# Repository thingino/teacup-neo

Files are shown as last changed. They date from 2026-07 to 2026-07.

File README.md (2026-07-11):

# Teacup Neo

A universal development platform for **any Ingenic SoC** — T10, T20, T21, T23, T30,
T31, T32, T33, T40, T41, and the A1 NVR processor — regardless of package
(QFN88 / QFN96 / BGA232 / BGA356 / BGA381).

Two boards:
- a **carrier** — the universal baseboard: adjustable SoC power, all peripherals,
  full pin breakout, and an on-board **ESP32-S3 management controller** so an agent
  (an LLM, CI, or a human) can drive the target wired *or* wireless — flash, reset,
  boot-select, console, and voltage-margin it hands-off;
- a small per-SoC **interposer** — the SoC + its package fanout + clock + decoupling
  + straps (+ optional local power / boot NOR), presented on a **DDR4 card-edge**
  (UDIMM-288 desktop) socket.

Swap the interposer, keep the carrier — the package stops mattering.

## The design

**Full spec: [`docs/UNIVERSAL.md`](docs/UNIVERSAL.md).** It covers the connector
choice, the power architecture (adjustable VCORE/VDDR with digipot voltage control +
margining), the verified T10→A1 rail table, clock/flash/boot, the ESP32-S3 BMC and
autonomous flash loop, full sensor/camera support (MIPI + DVP across the whole
family), full **A1** support (dual SATA 3.0 + dual GbE), dedicated camera-SoC
peripherals (audio, PWM/IR-cut/IR-LED, JTAG), carrier test points, and the
pin-breakout budget.

**Building it:** [`docs/BUILD.md`](docs/BUILD.md) is the agent-facing build playbook —
the headless KiCad pipeline (footprints → symbols → label-driven schematics →
`pcbnew` netlist apply → FreeRouting → manufacturing), the per-phase verification
gates, and the gotchas already proven on the T41 board in [`old/`](old/).

**Status: design / specification.** No open or deferred design questions remain; the
next step is the geography-first pin assignment against a carrier floorplan.

## `old/` — the T41 precursor

[`old/`](old/) holds the original single-SoC **T41 (QFN96)** board that proved the
approach and the headless-KiCad pipeline (kicad-cli + pcbnew + FreeRouting). It's
netlist-verified and ~83% auto-routed — details in [`old/README.md`](old/README.md).

License: GPL-3.0 (inherited from the upstream [Teacup](https://github.com/CapnRon/Teacup)).

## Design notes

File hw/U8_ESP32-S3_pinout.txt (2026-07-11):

U8 -- ESP32-S3-WROOM-1-N16R2 -- pin assignment
Generated from hw/sheets/bmc.kicad_sch (build_bmc.py, U8_PINS)

Pin  Module signal  Net / function
------------------------------------------------------------
1    GND            GND flag
2    3V3            +3V3_ALWAYS
3    EN             HOSTED_RESET
4    GPIO4          I2C_PWR_SDA
5    GPIO5          I2C_PWR_SCL
6    GPIO6          I2C_ID_SDA
7    GPIO7          I2C_ID_SCL
8    GPIO15         HOSTED_SPI_CLK
9    GPIO16         HOSTED_SPI_MOSI
10   GPIO17         UART1_TX
11   GPIO18         UART1_RX
12   GPIO8          BOOTSEL
13   GPIO19         BMC_USB_DM
14   GPIO20         BMC_USB_DP
15   GPIO3          RESET_EN
16   GPIO46         SW5V_EN_ALT
17   GPIO9          SFC_IO3
18   GPIO10         SFC_CS
19   GPIO11         SFC_IO0
20   GPIO12         SFC_CLK
21   GPIO13         SFC_IO1
22   GPIO14         SFC_IO2
23   GPIO21         HOSTED_SPI_MISO
24   GPIO47         HOSTED_SPI_CS
25   GPIO48         HOSTED_HANDSHAKE
26   GPIO45         HOSTED_DATA_READY
27   GPIO0          U8_BOOT
28   SPIIO6         EXP_INT
29   SPIIO7         spare
30   SPIDQS         EN_CS_U4
31   GPIO38         EN_CS_U5
32   MTCK           USB_OC1
33   MTDO           USB_OC2
34   MTDI           USB_OC3
35   MTMS           spare
36   U0RXD          ESP32_CONSOLE_RX
37   U0TXD          ESP32_CONSOLE_TX
38   GPIO2          SW5V_EN_BMC
39   GPIO1          VCORE_SNS
40   GND            (tied to pin 1's GND point)
41   GND            (tied to pin 1's GND point)

Notes:
- 2 GPIOs genuinely spare (29, 35); everything else allocated.
- Pins 28-30 (SPIIO6/SPIIO7/SPIDQS) are octal-PSRAM-only pins,
  usable as plain GPIO here because this is the quad-PSRAM (R2) variant.
- EN_CS_U4/U5 (flash CS-select) and SW5V_EN_BMC/SW5V_EN_ALT (power-domain
  switching) are kept on native GPIO deliberately -- margin/timing testing.
- USB_OC1-3 kept native for fast overcurrent response.
- USB_EN1-3, PG_SW5V, PG_VCORE, PG_SW5V_ALT, SW_SENSE_1/4, DCJACK_PRESENT
  moved off native GPIO onto U15 (TCA9555PWR, 16-bit I2C GPIO expander,
  LCSC C465732), sharing the I2C_PWR bus (not I2C_ID -- keeps the digipot/
  ID-EEPROM bus-isolation principle intact). Address 0x20 (A0-A2 grounded),
  no conflict with the MCP4661 digipot's 0x28-range address.
- HOSTED_SPI_CLK/MOSI/MISO/CS, HOSTED_HANDSHAKE, HOSTED_DATA_READY: ESP-Hosted
  full-duplex SPI co-processor link to the interposer SoC, crossing J1 pins 43-48.
  HOSTED_RESET (pin 3, ESP32's own EN) crosses via J1 pin 86 -- host side must
  drive it open-drain so it doesn't fight R8's pull-up.
- EXP_INT: U15's interrupt output, carrier-local, not crossing J1.

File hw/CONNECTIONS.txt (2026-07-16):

TEACUP UNIVERSAL CARRIER BOARD - CONNECTION REFERENCE
Generated directly from the KiCad netlist export (ground truth -- if the
schematic's visual layout is unclear or you're rebuilding it by hand, this
is what every pin SHOULD end up wired to, regardless of how it currently renders.
================================================================================

### POWER
--------------------------------------------------------------------------------

C1  (22uF)
      footprint: Capacitor_SMD:C_0805_2012Metric
      pin    1                       -> +5V_SW
      pin    2                       -> GND

C2  (100nF)
      footprint: Capacitor_SMD:C_0402_1005Metric
      pin    1                       -> +5V_SW
      pin    2                       -> GND

C3  (100nF)
      footprint: Capacitor_SMD:C_0402_1005Metric
      pin    1                       -> U1_BST
      pin    2                       -> U1_SW

C4  (1uF)
      footprint: Capacitor_SMD:C_0402_1005Metric
      pin    1                       -> U1_VCC
      pin    2                       -> GND

C5  (4.7nF)
      footprint: Capacitor_SMD:C_0402_1005Metric
      pin    1                       -> U1_SS
      pin    2                       -> GND

C6  (10uF)
      footprint: Capacitor_SMD:C_0805_2012Metric
      pin    1                       -> +5V_SW
      pin    2                       -> GND

C7  (100nF)
      footprint: Capacitor_SMD:C_0402_1005Metric
      pin    1                       -> U2_BST
      pin    2                       -> U2_SW

C9  (22uF)
      footprint: Capacitor_SMD:C_0805_2012Metric
      pin    1                       -> VCORE
      pin    2                       -> GND

C10  (22uF)
      footprint: Capacitor_SMD:C_0805_2012Metric
      pin    1                       -> VCORE
      pin    2                       -> GND

C11  (22uF)
      footprint: Capacitor_SMD:C_0805_2012Metric
      pin    1                       -> VDDR
      pin    2                       -> GND

C12  (100nF)
      footprint: Capacitor_SMD:C_0402_1005Metric
      pin    1                       -> +3V3
      pin    2                       -> GND

C13  (1nF)
      footprint: Capacitor_SMD:C_0402_1005Metric
      pin    1                       -> U4_CT
      pin    2                       -> GND

C14  (1uF)
      footprint: Capacitor_SMD:C_0603_1608Metric
      pin    1                       -> U5_VIN
      pin    2                       -> GND

C15  (10uF)
      footprint: Capacitor_SMD:C_0805_2012Metric
      pin    1                       -> +3V3_ALWAYS
      pin    2                       -> GND

C16  (10uF)
      footprint: Capacitor_SMD:C_0805_2012Metric
      pin    1                       -> +5V_SW
      pin    2                       -> GND

C17  (100nF)
      footprint: Capacitor_SMD:C_0402_1005Metric
      pin    1                       -> U7_BST
      pin    2                       -> U7_SW

C18  (22uF)
      footprint: Capacitor_SMD:C_0805_2012Metric
      pin    1                       -> +3V3
      pin    2                       -> GND

C19  (1uF)
      footprint: Capacitor_SMD:C_0603_1608Metric
      pin    1                       -> +3V3
      pin    2                       -> GND

C20  (10uF)
      footprint: Capacitor_SMD:C_0805_2012Metric
      pin    1                       -> +1V8
      pin    2                       -> GND

C23  (1nF)
      footprint: Capacitor_SMD:C_0402_1005Metric
      pin    1                       -> U14_CT
      pin    2                       -> GND

D1  (PMEG2010ER)
      footprint: Diode_SMD:Nexperia_CFP3_SOD-123W
      pin    1  K                    -> U5_VIN
      pin    2  A                    -> +5V_BMC

D2  (PMEG2010ER)
      footprint: Diode_SMD:Nexperia_CFP3_SOD-123W
      pin    1  K                    -> U5_VIN
      pin    2  A                    -> +5V_ALT

JP2  (0.8V)
      footprint: Connector_PinHeader_2.54mm:PinHeader_1x02_P2.54mm_Vertical
      pin    1  Pin_1                -> VCORE_FB_SEL
      pin    2  Pin_2                -> VCORE_FB_0V8

JP3  (0.9V)
      footprint: Connector_PinHeader_2.54mm:PinHeader_1x02_P2.54mm_Vertical
      pin    1  Pin_1                -> VCORE_FB_SEL
      pin    2  Pin_2                -> VCORE_FB_0V9

JP4  (1.0V)
      footprint: Connector_PinHeader_2.54mm:PinHeader_1x02_P2.54mm_Vertical
      pin    1  Pin_1                -> VCORE_FB_SEL
      pin    2  Pin_2                -> VCORE_FB_1V0

JP5  (1.1V)
      footprint: Connector_PinHeader_2.54mm:PinHeader_1x02_P2.54mm_Vertical
      pin    1  Pin_1                -> VCORE_FB_SEL
      pin    2  Pin_2                -> VCORE_FB_1V1

JP6  (COMPUTER)
      footprint: Connector_PinHeader_2.54mm:PinHeader_1x02_P2.54mm_Vertical
      pin    1  Pin_1                -> VCORE_FB_SEL
      pin    2  Pin_2                -> VCORE_FB_DIGIPOT

JP7  (1.35V)
      footprint: Connector_PinHeader_2.54mm:PinHeader_1x02_P2.54mm_Vertical
      pin    1  Pin_1                -> VDDR_FB_SEL
      pin    2  Pin_2                -> VDDR_FB_1V35

JP8  (1.5V)
      footprint: Connector_PinHeader_2.54mm:PinHeader_1x02_P2.54mm_Vertical
      pin    1  Pin_1                -> VDDR_FB_SEL
      pin    2  Pin_2                -> VDDR_FB_1V5

JP9  (1.8V)
      footprint: Connector_PinHeader_2.54mm:PinHeader_1x02_P2.54mm_Vertical
      pin    1  Pin_1                -> VDDR_FB_SEL
      pin    2  Pin_2                -> VDDR_FB_1V8

JP10  (COMPUTER)
      footprint: Connector_PinHeader_2.54mm:PinHeader_1x02_P2.54mm_Vertical
      pin    1  Pin_1                -> VDDR_FB_SEL
      pin    2  Pin_2                -> VDDR_FB_DIGIPOT

L1  (2.2uH)
      footprint: Inductor_SMD:L_1210_3225Metric
      pin    1                       -> U1_SW
      pin    2                       -> VCORE

L2  (2.2uH)
      footprint: Inductor_SMD:L_1210_3225Metric
      pin    1                       -> U2_SW
      pin    2                       -> VDDR

L3  (2.2uH)
      footprint: Inductor_SMD:L_1210_3225Metric
      pin    1                       -> U7_SW
      pin    2                       -> +3V3

R1  (100k)
      footprint: Resistor_SMD:R_0402_1005Metric
      pin    1                       -> +5V_SW
      pin    2                       -> U1_EN

R2  (10k)
      footprint: Resistor_SMD:R_0402_1005Metric
      pin    1                       -> +3V3
      pin    2                       -> PG_VCORE

R3  (100k)
      footprint: Resistor_SMD:R_0402_1005Metric
      pin    1                       -> +3V3
      pin    2                       -> U2_EN

R4  (10k)
      footprint: Resistor_SMD:R_0402_1005Metric
      pin    1                       -> +3V3
      pin    2                       -> PG_SW5V

R5  (100k)
      footprint: Resistor_SMD:R_0402_1005Metric
      pin    1                       -> +5V_SW
      pin    2                       -> U7_EN

R6  (31.6k)
      footprint: Resistor_SMD:R_0402_1005Metric
      pin    1                       -> +3V3
      pin    2                       -> P3V3_FB

R7  (10k)
      footprint: Resistor_SMD:R_0402_1005Metric
      pin    1                       -> P3V3_FB
      pin    2                       -> GND

R20  (100k)
      footprint: Resistor_SMD:R_0402_1005Metric
      pin    1                       -> EN_SW_BMC
      pin    2                       -> GND

R21  (1k)
      footprint: Resistor_SMD:R_0402_1005Metric
      pin    1                       -> SW5V_EN_BMC
      pin    2                       -> EN_SW_BMC

R22  (100k)
      footprint: Resistor_SMD:R_0402_1005Metric
      pin    1                       -> EN_SW_ALT
      pin    2                       -> GND

R23  (1k)
      footprint: Resistor_SMD:R_0402_1005Metric
      pin    1                       -> SW5V_EN_ALT
      pin    2                       -> EN_SW_ALT

R24  (10k)
      footprint: Resistor_SMD:R_0402_1005Metric
      pin    1                       -> +3V3
      pin    2                       -> PG_SW5V_ALT

R25  (4.7k)
      footprint: Resistor_SMD:R_0402_1005Metric
      pin    1                       -> +3V3
      pin    2                       -> I2C_PWR_SDA

R26  (4.7k)
      footprint: Resistor_SMD:R_0402_1005Metric
      pin    1                       -> +3V3
      pin    2                       -> I2C_PWR_SCL

R27  (3.32k)
      footprint: Resistor_SMD:R_0402_1005Metric
      pin    1                       -> VCORE
      pin    2                       -> VCORE_FB_0V8

R28  (10.0k)
      footprint: Resistor_SMD:R_0402_1005Metric
      pin    1                       -> VCORE_FB_0V8
      pin    2                       -> GND

R29  (4.99k)
      footprint: Resistor_SMD:R_0402_1005Metric
      pin    1                       -> VCORE
      pin    2                       -> VCORE_FB_0V9

R30  (10.0k)
      footprint: Resistor_SMD:R_0402_1005Metric
      pin    1                       -> VCORE_FB_0V9
      pin    2                       -> GND

R31  (6.65k)
      footprint: Resistor_SMD:R_0402_1005Metric
      pin    1                       -> VCORE
      pin    2                       -> VCORE_FB_1V0

R32  (10.0k)
      footprint: Resistor_SMD:R_0402_1005Metric
      pin    1                       -> VCORE_FB_1V0
      pin    2                       -> GND

R33  (8.25k)
      footprint: Resistor_SMD:R_0402_1005Metric
      pin    1                       -> VCORE
      pin    2                       -> VCORE_FB_1V1

R34  (10.0k)
      footprint: Resistor_SMD:R_0402_1005Metric
      pin    1                       -> VCORE_FB_1V1
      pin    2                       -> GND

R35  (6.81k)
      footprint: Resistor_SMD:R_0402_1005Metric
      pin    1                       -> VDDR
      pin    2                       -> VDDR_FB_1V35

R36  (10.0k)
      footprint: Resistor_SMD:R_0402_1005Metric
      pin    1                       -> VDDR_FB_1V35
      pin    2                       -> GND

R37  (8.66k)
      footprint: Resistor_SMD:R_0402_1005Metric
      pin    1                       -> VDDR
      pin    2                       -> VDDR_FB_1V5

R38  (10.0k)
      footprint: Resistor_SMD:R_0402_1005Metric
      pin    1                       -> VDDR_FB_1V5
      pin    2                       -> GND

R39  (12.4k)
      footprint: Resistor_SMD:R_0402_1005Metric
      pin    1                       -> VDDR
      pin    2                       -> VDDR_FB_1V8

R40  (10.0k)
      footprint: Resistor_SMD:R_0402_1005Metric
      pin    1                       -> VDDR_FB_1V8
      pin    2                       -> GND

U1  (AP62600SJ-7)
      footprint: teacup-carrier:QFN-12_L3.0-W2.0-P0.50-TL_AP62600SJ-7
      pin    1  PGND                 -> GND
      pin    2  VIN                  -> +5V_SW
      pin    3  EN                   -> U1_EN
      pin    4  MODE                 -> GND
      pin    5  FSEL                 -> GND
      pin    6  PG                   -> PG_VCORE
      pin    7  BST                  -> U1_BST
      pin    8  SW                   -> U1_SW
      pin    9  VCC                  -> U1_VCC
      pin   10  SS/TR                -> U1_SS
      pin   11  GND                  -> GND
      pin   12  FB                   -> VCORE_FB_SEL

U2  (AP62300WU-7)
      footprint: teacup-carrier:TSOT-23-6_L2.9-W1.6-P0.95-LS2.8-BL
      pin    1  GND                  -> GND
      pin    2  SW                   -> U2_SW
      pin    3  VIN                  -> +5V_SW
      pin    4  FB                   -> VDDR_FB_SEL
      pin    5  EN                   -> U2_EN
      pin    6  BST                  -> U2_BST

U3  (MCP4661-104E_ST)
      footprint: Package_SO:TSSOP-14_4.4x5mm_P0.65mm
      pin    1  HVC/A0               -> GND
      pin    2  SCL                  -> I2C_PWR_SCL
      pin    3  SDA                  -> I2C_PWR_SDA
      pin    4  VSS                  -> GND
      pin    5  P1B                  -> GND
      pin    6  P1W                  -> VDDR_FB_DIGIPOT
      pin    7  P1A                  -> VDDR
      pin    8  P0A                  -> VCORE
      pin    9  P0W                  -> VCORE_FB_DIGIPOT
      pin   10  P0B                  -> GND
      pin   11  WP                   -> +3V3
      pin   12  A2                   -> GND
      pin   13  A1                   -> GND
      pin   14  VDD                  -> +3V3

U4  (TPS22990DMLR)
      footprint: teacup-carrier:WSON-10_L3.0-W2.0-P0.50-BL-EP_TI_DML
      pin    1  CT                   -> U4_CT
      pin    2  NC                   -> (not connected)
      pin    3  VIN                  -> +5V_BMC
      pin    4  VBIAS                -> +5V_BMC
      pin    5  ON                   -> EN_SW_BMC
      pin    6  GND                  -> GND
      pin    7  PG                   -> PG_SW5V
      pin    8  VOUT                 -> +5V_SW
      pin    9  VOUT                 -> +5V_SW
      pin   10  VOUT                 -> +5V_SW
      pin   11  VIN                  -> +5V_BMC

U5  (AZ1117CH-3.3TRG1)
      footprint: Package_TO_SOT_SMD:SOT-223-3_TabPin2
      pin    1  IN                   -> U5_VIN
      pin    2  GND                  -> GND
      pin    3  OUT                  -> +3V3_ALWAYS

U6  (AZ1117CH-1.8TRG1)
      footprint: Package_TO_SOT_SMD:SOT-223-3_TabPin2
      pin    1  IN                   -> +3V3
      pin    2  GND                  -> GND
      pin    3  OUT                  -> +1V8

U7  (AP62300WU-7)
      footprint: teacup-carrier:TSOT-23-6_L2.9-W1.6-P0.95-LS2.8-BL
      pin    1  GND                  -> GND
      pin    2  SW                   -> U7_SW
      pin    3  VIN                  -> +5V_SW
      pin    4  FB                   -> P3V3_FB
      pin    5  EN                   -> U7_EN
      pin    6  BST                  -> U7_BST

U14  (TPS22990DMLR)
      footprint: teacup-carrier:WSON-10_L3.0-W2.0-P0.50-BL-EP_TI_DML
      pin    1  CT                   -> U14_CT
      pin    2  NC                   -> (not connected)
      pin    3  VIN                  -> +5V_ALT
      pin    4  VBIAS                -> +5V_ALT
      pin    5  ON                   -> EN_SW_ALT
      pin    6  GND                  -> GND
      pin    7  PG                   -> PG_SW5V_ALT
      pin    8  VOUT                 -> +5V_SW
      pin    9  VOUT                 -> +5V_SW
      pin   10  VOUT                 -> +5V_SW
      pin   11  VIN                  -> +5V_ALT

### DDR4 UDIMM-288 CONNECTOR
--------------------------------------------------------------------------------

J1  (AH58893-T9B10-3F)
      footprint: teacup-carrier:DDR4288S0511H_UDIMM288
      pin    1  P1                   -> VCORE
      pin    2  P2                   -> VCORE
      pin    3  P3                   -> VCORE
      pin    4  P4                   -> VCORE
      pin    5  P5                   -> GND
      pin    6  P6                   -> MICLP
      pin    7  P7                   -> HPOUTL
      pin    8  P8                   -> GND
      pin    9  P9                   -> VDDR
      pin   10  P10                  -> VDDR
      pin   11  P11                  -> GND
      pin   12  P12                  -> GND
      pin   13  P13                  -> +3V3
      pin   14  P14                  -> +3V3
      pin   15  P15                  -> +1V8
      pin   16  P16                  -> +1V8
      pin   17  P17                  -> +5V_SW
      pin   18  P18                  -> +5V_SW
      pin   19  P19                  -> GND
      pin   20  P20                  -> USBA_HOST_DP
      pin   21  P21                  -> USBA_HOST_DM
      pin   22  P22                  -> GND
      pin   23  P23                  -> VCORE_SNS
      pin   24  P24                  -> HOSTED_DATA_READY
      pin   25  P25                  -> HOSTED_HANDSHAKE
      pin   26  P26                  -> HOSTED_SPI_CS
      pin   27  P27                  -> HOSTED_SPI_MISO
      pin   28  P28                  -> SFC_IO2
      pin   29  P29                  -> SFC_IO1
      pin   30  P30                  -> SFC_CLK
      pin   31  P31                  -> SFC_IO0
      pin   32  P32                  -> SFC_CS
      pin   33  P33                  -> SFC_IO3
      pin   34  P34                  -> RESET_EN
      pin   35  P35                  -> BOOTSEL
      pin   36  P36                  -> GND
      pin   37  P37                  -> GND
      pin   38  P38                  -> GND
      pin   39  P39                  -> GND
      pin   40  P40                  -> GND
      pin   41  P41                  -> GND
      pin   42  P42                  -> UART1_RX
      pin   43  P43                  -> UART1_TX
      pin   44  P44                  -> HOSTED_SPI_MOSI
      pin   45  P45                  -> HOSTED_SPI_CLK
      pin   46  P46                  -> I2C_ID_SCL
      pin   47  P47                  -> I2C_ID_SDA
      pin   48  P48                  -> HOSTED_RESET
      pin   49  P49                  -> GND
      pin   50  P50                  -> MSC0_D1
      pin   51  P51                  -> GND
      pin   52  P52                  -> MSC0_D0
      pin   53  P53                  -> MSC0_CLK
      pin   54  P54                  -> MSC0_CMD
      pin   55  P55                  -> MSC0_D3_CD
      pin   56  P56                  -> MSC0_D2
      pin   57  P57                  -> GND
      pin   58  P58                  -> GND
      pin   59  P59                  -> GND
      pin   60  P60                  -> MIPI0_SCCB_SDA
      pin   61  P61                  -> MIPI0_SCCB_SCL
      pin   62  P62                  -> MIPI0_GPIO
      pin   63  P63                  -> GND
      pin   64  P64                  -> MIPI0_CLKP
      pin   65  P65                  -> MIPI0_CLKN
      pin   66  P66                  -> GND
      pin   67  P67                  -> MIPI0_D1P
      pin   68  P68                  -> MIPI0_D1N
      pin   69  P69                  -> GND
      pin   70  P70                  -> MIPI0_D0P
      pin   71  P71                  -> MIPI0_D0N
      pin   72  P72                  -> GND
      pin   73  P73                  -> MIPI1_SCCB_SDA
      pin   74  P74                  -> MIPI1_SCCB_SCL
      pin   75  P75                  -> MIPI1_GPIO
      pin   76  P76                  -> GND
      pin   77  P77                  -> MIPI1_CLKP
      pin   78  P78                  -> MIPI1_CLKN
      pin   79  P79                  -> GND
      pin   80  P80                  -> MIPI1_D1P
      pin   81  P81                  -> MIPI1_D1N
      pin   82  P82                  -> GND
      pin   83  P83                  -> MIPI1_D0P
      pin   84  P84                  -> MIPI1_D0N
      pin   85  P85                  -> GND
      pin   86  P86                  -> GND
      pin   87  P87                  -> GMAC0_MDIO
      pin   88  P88                  -> GMAC0_MDCK
      pin   89  P89                  -> GMAC0_TXCLK
      pin   90  P90                  -> GMAC0_PHYCLK
      pin   91  P91                  -> GMAC0_TXEN
      pin   92  P92                  -> GMAC0_TXD0
      pin   93  P93                  -> GMAC0_TXD1
      pin   94  P94                  -> GMAC0_RXDV
      pin   95  P95                  -> GMAC0_RXD0
      pin   96  P96                  -> GMAC0_RXD1
      pin   97  P97                  -> GND
      pin   98  P98                  -> UART0_RXD
      pin   99  P99                  -> UART0_TXD
      pin  100  P100                 -> UART0_CTS
      pin  101  P101                 -> UART0_RTS
      pin  102  P102                 -> GND
      pin  103  P103                 -> UART2_RXD
      pin  104  P104                 -> UART2_TXD
      pin  105  P105                 -> UART2_CTS
      pin  106  P106                 -> UART2_RTS
      pin  107  P107                 -> GND
      pin  108  P108                 -> UART3_RXD
      pin  109  P109                 -> UART3_TXD
      pin  110  P110                 -> UART3_CTS
      pin  111  P111                 -> UART3_RTS
      pin  112  P112                 -> GND
      pin  113  P113                 -> GMAC1_MDIO
      pin  114  P114                 -> GMAC1_MDCK
      pin  115  P115                 -> GMAC1_TXCLK
      pin  116  P116                 -> GMAC1_PHYCLK
      pin  117  P117                 -> GMAC1_TXEN
      pin  118  P118                 -> GMAC1_TXD0
      pin  119  P119                 -> GMAC1_TXD1
      pin  120  P120                 -> GMAC1_RXDV
      pin  121  P121                 -> GMAC1_RXD0
      pin  122  P122                 -> GMAC1_RXD1
      pin  123  P123                 -> GND
      pin  124  P124                 -> SSI0_CLK
      pin  125  P125                 -> SSI0_DT
      pin  126  P126                 -> SSI0_DR
      pin  127  P127                 -> SSI0_CE0
      pin  128  P128                 -> SSI0_CE1
      pin  129  P129                 -> SSI0_GPC
      pin  130  P130                 -> GND
      pin  131  P131                 -> SSI1_CLK
      pin  132  P132                 -> SSI1_DT
      pin  133  P133                 -> SSI1_DR
      pin  134  P134                 -> SSI1_CE0
      pin  135  P135                 -> GND
      pin  136  P136                 -> PWM0
      pin  137  P137                 -> PWM1
      pin  138  P138                 -> PWM2
      pin  139  P139                 -> PWM3
      pin  140  P140                 -> PWM4
      pin  141  P141                 -> PWM5
      pin  142  P142                 -> PWM6
      pin  143  P143                 -> PWM7
      pin  144  P144                 -> GND
      pin  145  P145                 -> GND
      pin  146  P146                 -> SAR_AUX0
      pin  147  P147                 -> GND
      pin  148  P148                 -> SMB0_SDA
      pin  149  P149                 -> SMB0_SCK
      pin  150  P150                 -> SMB1_SDA
      pin  151  P151                 -> SMB1_SCK
      pin  152  P152                 -> GND
      pin  153  P153                 -> GPIO0
      pin  154  P154                 -> GPIO1
      pin  155  P155                 -> GPIO2
      pin  156  P156                 -> GPIO3
      pin  157  P157                 -> GPIO4
      pin  158  P158                 -> GPIO5
      pin  159  P159                 -> GPIO6
      pin  160  P160                 -> GPIO7
      pin  161  P161                 -> GPIO8
      pin  162  P162                 -> GPIO9
      pin  163  P163                 -> GPIO10
      pin  164  P164                 -> GPIO11
      pin  165  P165                 -> GPIO12
      pin  166  P166                 -> GPIO13
      pin  167  P167                 -> GPIO14
      pin  168  P168                 -> GPIO15
      pin  169  P169                 -> GND
      pin  170  P170                 -> GND
      pin  171  P171                 -> GND
      pin  172  P172                 -> GND
      pin  173  P173                 -> SPARE_P173
      pin  174  P174                 -> SPARE_P174
      pin  175  P175                 -> SPARE_P175
      pin  176  P176                 -> SPARE_P176
      pin  177  P177                 -> SPARE_P177
      pin  178  P178                 -> SPARE_P178
      pin  179  P179                 -> SPARE_P179
      pin  180  P180                 -> SPARE_P180
      pin  181  P181                 -> SPARE_P181
      pin  182  P182                 -> SPARE_P182
      pin  183  P183                 -> SPARE_P183
      pin  184  P184                 -> SPARE_P184
      pin  185  P185                 -> SPARE_P185
      pin  186  P186                 -> SPARE_P186
      pin  187  P187                 -> SPARE_P187
      pin  188  P188                 -> SPARE_P188
      pin  189  P189                 -> SPARE_P189
      pin  190  P190                 -> SPARE_P190
      pin  191  P191                 -> SPARE_P191
      pin  192  P192                 -> SPARE_P192
      pin  193  P193                 -> SPARE_P193
      pin  194  P194                 -> SPARE_P194
      pin  195  P195                 -> SPARE_P195
      pin  196  P196                 -> SPARE_P196
      pin  197  P197                 -> SPARE_P197
      pin  198  P198                 -> SPARE_P198
      pin  199  P199                 -> SPARE_P199
      pin  200  P200                 -> SPARE_P200
      pin  201  P201                 -> SPARE_P201
      pin  202  P202                 -> SPARE_P202
      pin  203  P203                 -> SPARE_P203
      pin  204  P204                 -> SPARE_P204
      pin  205  P205                 -> SPARE_P205
      pin  206  P206                 -> SPARE_P206
      pin  207  P207                 -> SPARE_P207
      pin  208  P208                 -> SPARE_P208
      pin  209  P209                 -> SPARE_P209
      pin  210  P210                 -> SPARE_P210
      pin  211  P211                 -> SPARE_P211
      pin  212  P212                 -> SPARE_P212
      pin  213  P213                 -> SPARE_P213
      pin  214  P214                 -> SPARE_P214
      pin  215  P215                 -> SPARE_P215
      pin  216  P216                 -> SPARE_P216
      pin  217  P217                 -> SPARE_P217
      pin  218  P218                 -> SPARE_P218
      pin  219  P219                 -> SPARE_P219
      pin  220  P220                 -> SPARE_P220
      pin  221  P221                 -> SPARE_P221
      pin  222  P222                 -> SPARE_P222
      pin  223  P223                 -> SPARE_P223
      pin  224  P224                 -> SPARE_P224
      pin  225  P225                 -> SPARE_P225
      pin  226  P226                 -> SPARE_P226
      pin  227  P227                 -> SPARE_P227
      pin  228  P228                 -> SPARE_P228
      pin  229  P229                 -> SPARE_P229
      pin  230  P230                 -> SPARE_P230
      pin  231  P231                 -> SPARE_P231
      pin  232  P232                 -> SPARE_P232
      pin  233  P233                 -> SPARE_P233
      pin  234  P234                 -> SPARE_P234
      pin  235  P235                 -> SPARE_P235
      pin  236  P236                 -> SPARE_P236
      pin  237  P237                 -> SPARE_P237
      pin  238  P238                 -> SPARE_P238
      pin  239  P239                 -> SPARE_P239
      pin  240  P240                 -> SPARE_P240
      pin  241  P241                 -> SPARE_P241
      pin  242  P242                 -> SPARE_P242
      pin  243  P243                 -> SPARE_P243
      pin  244  P244                 -> SPARE_P244
      pin  245  P245                 -> SPARE_P245
      pin  246  P246                 -> SPARE_P246
      pin  247  P247                 -> SPARE_P247
      pin  248  P248                 -> SPARE_P248
      pin  249  P249                 -> SPARE_P249
      pin  250  P250                 -> SPARE_P250
      pin  251  P251                 -> SPARE_P251
      pin  252  P252                 -> SPARE_P252
      pin  253  P253                 -> SPARE_P253
      pin  254  P254                 -> SPARE_P254
      pin  255  P255                 -> SPARE_P255
      pin  256  P256                 -> SPARE_P256
      pin  257  P257                 -> SPARE_P257
      pin  258  P258                 -> SPARE_P258
      pin  259  P259                 -> SPARE_P259
      pin  260  P260                 -> SPARE_P260
      pin  261  P261                 -> SPARE_P261
      pin  262  P262                 -> SPARE_P262
      pin  263  P263                 -> SPARE_P263
      pin  264  P264                 -> SPARE_P264
      pin  265  P265                 -> SPARE_P265
      pin  266  P266                 -> SPARE_P266
      pin  267  P267                 -> SPARE_P267
      pin  268  P268                 -> SPARE_P268
      pin  269  P269                 -> SPARE_P269
      pin  270  P270                 -> SPARE_P270
      pin  271  P271                 -> SPARE_P271
      pin  272  P272                 -> SPARE_P272
      pin  273  P273                 -> SPARE_P273
      pin  274  P274                 -> SPARE_P274
      pin  275  P275                 -> SPARE_P275
      pin  276  P276                 -> SPARE_P276
      pin  277  P277                 -> SPARE_P277
      pin  278  P278                 -> SPARE_P278
      pin  279  P279                 -> SPARE_P279
      pin  280  P280                 -> SPARE_P280
      pin  281  P281                 -> SPARE_P281
      pin  282  P282                 -> SPARE_P282
      pin  283  P283                 -> MSC1_CLK
      pin  284  P284                 -> MSC1_CMD
      pin  285  P285                 -> MSC1_D0
      pin  286  P286                 -> MSC1_D1
      pin  287  P287                 -> MSC1_D2
      pin  288  P288                 -> MSC1_D3_CD

### BMC - ESP32-S3
--------------------------------------------------------------------------------

C21  (10uF)
      footprint: Capacitor_SMD:C_0805_2012Metric
      pin    1                       -> +3V3_ALWAYS
      pin    2                       -> GND

C22  (100nF)
      footprint: Capacitor_SMD:C_0402_1005Metric
      pin    1                       -> +3V3_ALWAYS
      pin    2                       -> GND

C24  (100nF)
      footprint: Capacitor_SMD:C_0402_1005Metric
      pin    1                       -> +3V3
      pin    2                       -> GND

C25  (100nF)
      footprint: Capacitor_SMD:C_0402_1005Metric
      pin    1                       -> +3V3
      pin    2                       -> GND

C26  (100nF)
      footprint: Capacitor_SMD:C_0402_1005Metric
      pin    1                       -> +3V3
      pin    2                       -> GND

R8  (10k)
      footprint: Resistor_SMD:R_0402_1005Metric
      pin    1                       -> +3V3
      pin    2                       -> HOSTED_RESET

R9  (10k)
      footprint: Resistor_SMD:R_0402_1005Metric
      pin    1                       -> +3V3
      pin    2                       -> U8_BOOT

R10  (10k)
      footprint: Resistor_SMD:R_0402_1005Metric
      pin    1                       -> +3V3
      pin    2                       -> SW_SENSE_1

R11  (10k)
      footprint: Resistor_SMD:R_0402_1005Metric
      pin    1                       -> +3V3
      pin    2                       -> SW_SENSE_4

R41  (4.7k)
      footprint: Resistor_SMD:R_0402_1005Metric
      pin    1                       -> +3V3
      pin    2                       -> I2C_ID_SDA

R42  (4.7k)
      footprint: Resistor_SMD:R_0402_1005Metric
      pin    1                       -> +3V3
      pin    2                       -> I2C_ID_SCL

SW1  (SSSS711403)
      footprint: teacup-carrier:SW-TH_SSSS711403
      pin    1                       -> SW_SENSE_1
      pin    2                       -> (not connected)
      pin    3                       -> GND
      pin    4                       -> SW_SENSE_4
      pin    5                       -> (not connected)
      pin    6                       -> (not connected)

SW2  (SSSS711403)
      footprint: teacup-carrier:SW-TH_SSSS711403
      pin    1                       -> EN_SW_ALT
      pin    2                       -> (not connected)
      pin    3                       -> +5V_ALT
      pin    4                       -> EN_SW_BMC
      pin    5                       -> (not connected)
      pin    6                       -> (not connected)

U8  (ESP32-S3-WROOM-1-N16R2)
      footprint: teacup-carrier:ESP32-S3-WROOM-1
      pin    1  GND                  -> GND
      pin    2  3V3                  -> +3V3_ALWAYS
      pin    3  EN                   -> HOSTED_RESET
      pin    4  GPIO4                -> I2C_PWR_SDA
      pin    5  GPIO5                -> I2C_PWR_SCL
      pin    6  GPIO6                -> I2C_ID_SDA
      pin    7  GPIO7                -> I2C_ID_SCL
      pin    8  GPIO15               -> HOSTED_SPI_CLK
      pin    9  GPIO16               -> HOSTED_SPI_MOSI
      pin   10  GPIO17               -> UART1_TX
      pin   11  GPIO18               -> UART1_RX
      pin   12  GPIO8                -> BOOTSEL
      pin   13  GPIO19               -> BMC_USB_DM
      pin   14  GPIO20               -> BMC_USB_DP
      pin   15  GPIO3                -> RESET_EN
      pin   16  GPIO46               -> SW5V_EN_ALT
      pin   17  GPIO9                -> SFC_IO3
      pin   18  GPIO10               -> SFC_CS
      pin   19  GPIO11               -> SFC_IO0
      pin   20  GPIO12               -> SFC_CLK
      pin   21  GPIO13               -> SFC_IO1
      pin   22  GPIO14               -> SFC_IO2
      pin   23  GPIO21               -> HOSTED_SPI_MISO
      pin   24  GPIO47               -> HOSTED_SPI_CS
      pin   25  GPIO48               -> HOSTED_HANDSHAKE
      pin   26  GPIO45               -> HOSTED_DATA_READY
      pin   27  GPIO0                -> U8_BOOT
      pin   28  SPIIO6               -> EXP_INT
      pin   29  SPIIO7               -> (not connected)
      pin   30  SPIDQS               -> EN_CS_U4
      pin   31  GPIO38               -> EN_CS_U5
      pin   32  MTCK                 -> USB_OC1
      pin   33  MTDO                 -> USB_OC2
      pin   34  MTDI                 -> USB_OC3
      pin   35  MTMS                 -> (not connected)
      pin   36  U0RXD                -> ESP32_CONSOLE_RX
      pin   37  U0TXD                -> ESP32_CONSOLE_TX
      pin   38  GPIO2                -> SW5V_EN_BMC
      pin   39  GPIO1                -> VCORE_SNS
      pin   40  GND                  -> GND
      pin   41  GND                  -> GND

U9  (TS5A3166)
      footprint: Package_TO_SOT_SMD:SOT-23-5
      pin    1  NO                   -> NOR_U4_CE
      pin    2  COM                  -> SFC_CS
      pin    3  GND                  -> GND
      pin    4  IN                   -> EN_CS_U4
      pin    5  V+                   -> +3V3

U10  (TS5A3166)
      footprint: Package_TO_SOT_SMD:SOT-23-5
      pin    1  NO                   -> NOR_U5_CE
      pin    2  COM                  -> SFC_CS
      pin    3  GND                  -> GND
      pin    4  IN                   -> EN_CS_U5
      pin    5  V+                   -> +3V3

U11  (DIP-8 Socket)
      footprint: Package_DIP:DIP-8_W7.62mm_Socket
      pin    1  ~{CS}                -> NOR_U5_CE
      pin    2  DO(IO1)              -> SFC_IO1
      pin    3  IO2                  -> SFC_IO2
      pin    4  GND                  -> GND
      pin    5  DI(IO0)              -> SFC_IO0
      pin    6  CLK                  -> SFC_CLK
      pin    7  IO3                  -> SFC_IO3
      pin    8  VCC                  -> +3V3

U12  (TPS2053BDR)
      footprint: Package_SO:SOIC-16_3.9x9.9mm_P1.27mm
      pin    1  GND                  -> GND
      pin    2  IN1                  -> +5V_SW
      pin    3  EN1                  -> USB_EN1
      pin    4  EN2                  -> USB_EN2
      pin    5  GND                  -> GND
      pin    6  IN2                  -> +5V_SW
      pin    7  EN3                  -> USB_EN3
      pin    8  NC                   -> (not connected)
      pin    9  NC                   -> (not connected)
      pin   10  NC                   -> (not connected)
      pin   11  OUT3                 -> USB3_VBUS_OUT
      pin   12  OC3                  -> USB_OC3
      pin   13  OC2                  -> USB_OC2
      pin   14  OUT2                 -> USB2_VBUS_OUT
      pin   15  OUT1                 -> USB1_VBUS_OUT
      pin   16  OC1                  -> USB_OC1

U13  (W25Q32JVSS)
      footprint: Package_SO:SOIC-8_5.3x5.3mm_P1.27mm
      pin    1  ~{CS}                -> NOR_U4_CE
      pin    2  DO(IO1)              -> SFC_IO1
      pin    3  IO2                  -> SFC_IO2
      pin    4  GND                  -> GND
      pin    5  DI(IO0)              -> SFC_IO0
      pin    6  CLK                  -> SFC_CLK
      pin    7  IO3                  -> SFC_IO3
      pin    8  VCC                  -> +3V3

U15  (TCA9555PWR)
      footprint: Package_SO:TSSOP-24_4.4x7.8mm_P0.65mm
      pin    1  ~{INT}               -> EXP_INT
      pin    2  A1                   -> GND
      pin    3  A2                   -> GND
      pin    4  P00                  -> USB_EN1
      pin    5  P01                  -> USB_EN2
      pin    6  P02                  -> USB_EN3
      pin    7  P03                  -> PG_SW5V
      pin    8  P04                  -> PG_VCORE
      pin    9  P05                  -> PG_SW5V_ALT
      pin   10  P06                  -> SW_SENSE_1
      pin   11  P07                  -> SW_SENSE_4
      pin   12  GND                  -> GND
      pin   13  P10                  -> DCJACK_PRESENT
      pin   14  P11                  -> (not connected)
      pin   15  P12                  -> (not connected)
      pin   16  P13                  -> (not connected)
      pin   17  P14                  -> (not connected)
      pin   18  P15                  -> (not connected)
      pin   19  P16                  -> (not connected)
      pin   20  P17                  -> (not connected)
      pin   21  A0                   -> GND
      pin   22  SCL                  -> I2C_PWR_SCL
      pin   23  SDA                  -> I2C_PWR_SDA
      pin   24  VCC                  -> +3V3

### CARRIER PHYSICAL I/O
--------------------------------------------------------------------------------

C27  (10uF)
      footprint: Capacitor_SMD:C_0805_2012Metric
      pin    1                       -> +5V_BMC
      pin    2                       -> GND

C28  (10uF)
      footprint: Capacitor_SMD:C_0805_2012Metric
      pin    1                       -> +5V_ALT
      pin    2                       -> GND

C29  (10uF)
      footprint: Capacitor_SMD:C_0805_2012Metric
      pin    1                       -> DCJACK_VBUS
      pin    2                       -> GND

J2  (TYPE-C-31-M-12)
      footprint: Connector_USB:USB_C_Receptacle_HRO_TYPE-C-31-M-12
      pin   A1  GND                  -> GND
      pin  A12  GND                  -> GND
      pin   A4  VBUS                 -> ALTUSB_VBUS
      pin   A5  CC1                  -> USBC_CC1
      pin   A6  D+                   -> USBA_HOST_DP
      pin   A7  D-                   -> USBA_HOST_DM
      pin   A8  SBU1                 -> (not connected)
      pin   A9  VBUS                 -> ALTUSB_VBUS
      pin   B1  GND                  -> GND
      pin  B12  GND                  -> GND
      pin   B4  VBUS                 -> ALTUSB_VBUS
      pin   B5  CC2                  -> USBC_CC2
      pin   B6  D+                   -> USBA_HOST_DP
      pin   B7  D-                   -> USBA_HOST_DM
      pin   B8  SBU2                 -> (not connected)
      pin   B9  VBUS                 -> ALTUSB_VBUS
      pin   S1  SHIELD               -> GND

J3  (TE_292303-7)
      footprint: Connector_USB:USB_A_TE_292303-7_Horizontal
      pin    1  VBUS                 -> USB1_VBUS_OUT
      pin    2  D-                   -> USBA_HOST_DM
      pin    3  D+                   -> USBA_HOST_DP
      pin    4  GND                  -> GND
      pin    5  Shield               -> GND

J4  (Hirose_DM3D-SF)
      footprint: Connector_Card:microSD_HC_Hirose_DM3D-SF
      pin    1  DAT2                 -> MSC0_D2
      pin    2  DAT3/CD              -> MSC0_D3_CD
      pin    3  CMD                  -> MSC0_CMD
      pin    4  VDD                  -> +3V3
      pin    5  CLK                  -> MSC0_CLK
      pin    6  VSS                  -> GND
      pin    7  DAT0                 -> MSC0_D0
      pin    8  DAT1                 -> MSC0_D1
      pin    9  DET_B                -> GND
      pin   10  DET_A                -> MSC0_CD
      pin   11  SHIELD               -> (not connected)

J5  (Wuerth_694106301002)
      footprint: Connector_BarrelJack:BarrelJack_Wuerth_6941xx301002
      pin    1                       -> DCJACK_VBUS
      pin    2                       -> GND
      pin    3                       -> DCJACK_PRESENT

J6  (AudioJack4_Ground)
      footprint: Connector_Audio:Jack_3.5mm_PJ320D_Horizontal
      pin    G                       -> (not connected)
      pin   R1                       -> HPOUTL
      pin   R2                       -> GND
      pin    S                       -> MICLP
      pin    T                       -> HPOUTL

J7  (SFW15R-2STE1LF)
      footprint: teacup-carrier:FPC-SMD_15P-P1.00_SFW15R-2STE1LF
      pin    1                       -> +3V3
      pin    2                       -> MIPI0_SCCB_SDA
      pin    3                       -> MIPI0_SCCB_SCL
      pin    4                       -> +3V3
      pin    5                       -> MIPI0_SENSOR_EN
      pin    6                       -> GND
      pin    7                       -> MIPI0_CLKP
      pin    8                       -> MIPI0_CLKN
      pin    9                       -> GND
      pin   10                       -> MIPI0_D1P
      pin   11                       -> MIPI0_D1N
      pin   12                       -> GND
      pin   13                       -> MIPI0_D0P
      pin   14                       -> MIPI0_D0N
      pin   15                       -> GND
      pin   16                       -> (not connected)
      pin   17                       -> (not connected)

J8  (SFW15R-2STE1LF)
      footprint: teacup-carrier:FPC-SMD_15P-P1.00_SFW15R-2STE1LF
      pin    1                       -> +3V3
      pin    2                       -> MIPI1_SCCB_SDA
      pin    3                       -> MIPI1_SCCB_SCL
      pin    4                       -> +3V3
      pin    5                       -> MIPI1_SENSOR_EN
      pin    6                       -> GND
      pin    7                       -> MIPI1_CLKP
      pin    8                       -> MIPI1_CLKN
      pin    9                       -> GND
      pin   10                       -> MIPI1_D1P
      pin   11                       -> MIPI1_D1N
      pin   12                       -> GND
      pin   13                       -> MIPI1_D0P
      pin   14                       -> MIPI1_D0N
      pin   15                       -> GND
      pin   16                       -> (not connected)
      pin   17                       -> (not connected)

J9  (TYPE-C-31-M-12)
      footprint: Connector_USB:USB_C_Receptacle_HRO_TYPE-C-31-M-12
      pin   A1  GND                  -> GND
      pin  A12  GND                  -> GND
      pin   A4  VBUS                 -> +5V_BMC
      pin   A5  CC1                  -> USBC2_CC1
      pin   A6  D+                   -> BMC_USB_DP
      pin   A7  D-                   -> BMC_USB_DM
      pin   A8  SBU1                 -> (not connected)
      pin   A9  VBUS                 -> +5V_BMC
      pin   B1  GND                  -> GND
      pin  B12  GND                  -> GND
      pin   B4  VBUS                 -> +5V_BMC
      pin   B5  CC2                  -> USBC2_CC2
      pin   B6  D+                   -> BMC_USB_DP
      pin   B7  D-                   -> BMC_USB_DM
      pin   B8  SBU2                 -> (not connected)
      pin   B9  VBUS                 -> +5V_BMC
      pin   S1  SHIELD               -> GND

J38  (AMP_MIC_TAP)
      footprint: Connector_PinHeader_2.54mm:PinHeader_1x03_P2.54mm_Vertical
      pin    1  Pin_1                -> HPOUTL
      pin    2  Pin_2                -> GND
      pin    3  Pin_3                -> MICLP

JP11  (EN_SEL)
      footprint: Connector_PinHeader_2.54mm:PinHeader_1x03_P2.54mm_Vertical_SMD_Pin1Left
      pin    1  Pin_1                -> MIPI0_GPIO
      pin    2  Pin_2                -> MIPI0_SENSOR_EN
      pin    3  Pin_3                -> +3V3

JP12  (EN_SEL)
      footprint: Connector_PinHeader_2.54mm:PinHeader_1x03_P2.54mm_Vertical_SMD_Pin1Left
      pin    1  Pin_1                -> MIPI1_GPIO
      pin    2  Pin_2                -> MIPI1_SENSOR_EN
      pin    3  Pin_3                -> +3V3

Q1  (AO3401A)
      footprint: Package_TO_SOT_SMD:SOT-23
      pin    1  G                    -> Q1_GATE
      pin    2  S                    -> DCJACK_VBUS
      pin    3  D                    -> +5V_ALT

Q2  (AO3401A)
      footprint: Package_TO_SOT_SMD:SOT-23
      pin    1  G                    -> Q2_GATE
      pin    2  S                    -> ALTUSB_VBUS
      pin    3  D                    -> +5V_ALT

R12  (5.1k)
      footprint: Resistor_SMD:R_0402_1005Metric
      pin    1                       -> USBC_CC1
      pin    2                       -> GND

R13  (5.1k)
      footprint: Resistor_SMD:R_0402_1005Metric
      pin    1                       -> USBC_CC2
      pin    2                       -> GND

R14  (10k)
      footprint: Resistor_SMD:R_0402_1005Metric
      pin    1                       -> +3V3
      pin    2                       -> DCJACK_PRESENT

R15  (100k)
      footprint: Resistor_SMD:R_0402_1005Metric
      pin    1                       -> Q1_GATE
      pin    2                       -> GND

R16  (4.7k)
      footprint: Resistor_SMD:R_0402_1005Metric
      pin    1                       -> DCJACK_VBUS
      pin    2                       -> Q2_GATE

R17  (100k)
      footprint: Resistor_SMD:R_0402_1005Metric
      pin    1                       -> Q2_GATE
      pin    2                       -> GND

R18  (5.1k)
      footprint: Resistor_SMD:R_0402_1005Metric
      pin    1                       -> USBC2_CC1
      pin    2                       -> GND

R19  (5.1k)
      footprint: Resistor_SMD:R_0402_1005Metric
      pin    1                       -> USBC2_CC2
      pin    2                       -> GND

R43  (1M)
      footprint: Resistor_SMD:R_0402_1005Metric
      pin    1                       -> +3V3
      pin    2                       -> MSC0_CD

### PIN BREAKOUT HEADERS
--------------------------------------------------------------------------------

J20  (HDR_J20)
      footprint: Connector_PinHeader_2.54mm:PinHeader_2x06_P2.54mm_Vertical
      pin    1  Pin_1                -> GND
      pin    2  Pin_2                -> GMAC0_MDIO
      pin    3  Pin_3                -> GMAC0_MDCK
      pin    4  Pin_4                -> GMAC0_TXCLK
      pin    5  Pin_5                -> GMAC0_PHYCLK
      pin    6  Pin_6                -> GMAC0_TXEN
      pin    7  Pin_7                -> GMAC0_TXD0
      pin    8  Pin_8                -> GMAC0_TXD1
      pin    9  Pin_9                -> GMAC0_RXDV
      pin   10  Pin_10               -> GMAC0_RXD0
      pin   11  Pin_11               -> GMAC0_RXD1
      pin   12  Pin_12               -> GND

J21  (HDR_J21)
      footprint: Connector_PinHeader_2.54mm:PinHeader_2x06_P2.54mm_Vertical
      pin    1  Pin_1                -> GND
      pin    2  Pin_2                -> GMAC1_MDIO
      pin    3  Pin_3                -> GMAC1_MDCK
      pin    4  Pin_4                -> GMAC1_TXCLK
      pin    5  Pin_5                -> GMAC1_PHYCLK
      pin    6  Pin_6                -> GMAC1_TXEN
      pin    7  Pin_7                -> GMAC1_TXD0
      pin    8  Pin_8                -> GMAC1_TXD1
      pin    9  Pin_9                -> GMAC1_RXDV
      pin   10  Pin_10               -> GMAC1_RXD0
      pin   11  Pin_11               -> GMAC1_RXD1
      pin   12  Pin_12               -> GND

J22  (HDR_J22)
      footprint: Connector_PinHeader_2.54mm:PinHeader_1x05_P2.54mm_Vertical
      pin    1  Pin_1                -> GND
      pin    2  Pin_2                -> UART0_RXD
      pin    3  Pin_3                -> UART0_TXD
      pin    4  Pin_4                -> UART0_CTS
      pin    5  Pin_5                -> UART0_RTS

J23  (HDR_J23)
      footprint: Connector_PinHeader_2.54mm:PinHeader_1x05_P2.54mm_Vertical
      pin    1  Pin_1                -> GND
      pin    2  Pin_2                -> UART2_RXD
      pin    3  Pin_3                -> UART2_TXD
      pin    4  Pin_4                -> UART2_CTS
      pin    5  Pin_5                -> UART2_RTS

J24  (HDR_J24)
      footprint: Connector_PinHeader_2.54mm:PinHeader_1x05_P2.54mm_Vertical
      pin    1  Pin_1                -> GND
      pin    2  Pin_2                -> UART3_RXD
      pin    3  Pin_3                -> UART3_TXD
      pin    4  Pin_4                -> UART3_CTS
      pin    5  Pin_5                -> UART3_RTS

J25  (HDR_J25)
      footprint: Connector_PinHeader_2.54mm:PinHeader_2x04_P2.54mm_Vertical
      pin    1  Pin_1                -> GND
      pin    2  Pin_2                -> SSI0_CLK
      pin    3  Pin_3                -> SSI0_DT
      pin    4  Pin_4                -> SSI0_DR
      pin    5  Pin_5                -> SSI0_CE0
      pin    6  Pin_6                -> SSI0_CE1
      pin    7  Pin_7                -> SSI0_GPC
      pin    8  Pin_8                -> GND

J26  (HDR_J26)
      footprint: Connector_PinHeader_2.54mm:PinHeader_1x05_P2.54mm_Vertical
      pin    1  Pin_1                -> GND
      pin    2  Pin_2                -> SSI1_CLK
      pin    3  Pin_3                -> SSI1_DT
      pin    4  Pin_4                -> SSI1_DR
      pin    5  Pin_5                -> SSI1_CE0

J27  (HDR_J27)
      footprint: Connector_PinHeader_2.54mm:PinHeader_2x05_P2.54mm_Vertical
      pin    1  Pin_1                -> GND
      pin    2  Pin_2                -> PWM0
      pin    3  Pin_3                -> PWM1
      pin    4  Pin_4                -> PWM2
      pin    5  Pin_5                -> PWM3
      pin    6  Pin_6                -> PWM4
      pin    7  Pin_7                -> PWM5
      pin    8  Pin_8                -> PWM6
      pin    9  Pin_9                -> PWM7
      pin   10  Pin_10               -> GND

J28  (HDR_J28)
      footprint: Connector_PinHeader_2.54mm:PinHeader_1x02_P2.54mm_Vertical
      pin    1  Pin_1                -> GND
      pin    2  Pin_2                -> SAR_AUX0

J29  (HDR_J29)
      footprint: Connector_PinHeader_2.54mm:PinHeader_1x05_P2.54mm_Vertical
      pin    1  Pin_1                -> GND
      pin    2  Pin_2                -> SMB0_SDA
      pin    3  Pin_3                -> SMB0_SCK
      pin    4  Pin_4                -> SMB1_SDA
      pin    5  Pin_5                -> SMB1_SCK

J30  (HDR_J30)
      footprint: Connector_PinHeader_2.54mm:PinHeader_2x09_P2.54mm_Vertical
      pin    1  Pin_1                -> GND
      pin    2  Pin_2                -> GPIO0
      pin    3  Pin_3                -> GPIO1
      pin    4  Pin_4                -> GPIO2
      pin    5  Pin_5                -> GPIO3
      pin    6  Pin_6                -> GPIO4
      pin    7  Pin_7                -> GPIO5
      pin    8  Pin_8                -> GPIO6
      pin    9  Pin_9                -> GPIO7
      pin   10  Pin_10               -> GPIO8
      pin   11  Pin_11               -> GPIO9
      pin   12  Pin_12               -> GPIO10
      pin   13  Pin_13               -> GPIO11
      pin   14  Pin_14               -> GPIO12
      pin   15  Pin_15               -> GPIO13
      pin   16  Pin_16               -> GPIO14
      pin   17  Pin_17               -> GPIO15
      pin   18  Pin_18               -> GND

J31  (HDR_J31)
      footprint: Connector_PinHeader_2.54mm:PinHeader_2x11_P2.54mm_Vertical
      pin    1  Pin_1                -> GND
      pin    2  Pin_2                -> SPARE_P173
      pin    3  Pin_3                -> SPARE_P174
      pin    4  Pin_4                -> SPARE_P175
      pin    5  Pin_5                -> SPARE_P176
      pin    6  Pin_6                -> SPARE_P177
      pin    7  Pin_7                -> SPARE_P178
      pin    8  Pin_8                -> SPARE_P179
      pin    9  Pin_9                -> SPARE_P180
      pin   10  Pin_10               -> SPARE_P181
      pin   11  Pin_11               -> SPARE_P182
      pin   12  Pin_12               -> SPARE_P183
      pin   13  Pin_13               -> SPARE_P184
      pin   14  Pin_14               -> SPARE_P185
      pin   15  Pin_15               -> SPARE_P186
      pin   16  Pin_16               -> SPARE_P187
      pin   17  Pin_17               -> SPARE_P188
      pin   18  Pin_18               -> SPARE_P189
      pin   19  Pin_19               -> SPARE_P190
      pin   20  Pin_20               -> SPARE_P191
      pin   21  Pin_21               -> SPARE_P192
      pin   22  Pin_22               -> GND

J32  (HDR_J32)
      footprint: Connector_PinHeader_2.54mm:PinHeader_2x13_P2.54mm_Vertical
      pin    1  Pin_1                -> GND
      pin    2  Pin_2                -> SPARE_P193
      pin    3  Pin_3                -> SPARE_P194
      pin    4  Pin_4                -> SPARE_P195
      pin    5  Pin_5                -> SPARE_P196
      pin    6  Pin_6                -> SPARE_P197
      pin    7  Pin_7                -> SPARE_P198
      pin    8  Pin_8                -> SPARE_P199
      pin    9  Pin_9                -> SPARE_P200
      pin   10  Pin_10               -> SPARE_P201
      pin   11  Pin_11               -> SPARE_P202
      pin   12  Pin_12               -> SPARE_P203
      pin   13  Pin_13               -> SPARE_P204
      pin   14  Pin_14               -> SPARE_P205
      pin   15  Pin_15               -> SPARE_P206
      pin   16  Pin_16               -> SPARE_P207
      pin   17  Pin_17               -> SPARE_P208
      pin   18  Pin_18               -> SPARE_P209
      pin   19  Pin_19               -> SPARE_P210
      pin   20  Pin_20               -> SPARE_P211
      pin   21  Pin_21               -> SPARE_P212
      pin   22  Pin_22               -> SPARE_P213
      pin   23  Pin_23               -> SPARE_P214
      pin   24  Pin_24               -> SPARE_P215
      pin   25  Pin_25               -> SPARE_P216
      pin   26  Pin_26               -> GND

J33  (HDR_J33)
      footprint: Connector_PinHeader_2.54mm:PinHeader_2x13_P2.54mm_Vertical
      pin    1  Pin_1                -> GND
      pin    2  Pin_2                -> SPARE_P217
      pin    3  Pin_3                -> SPARE_P218
      pin    4  Pin_4                -> SPARE_P219
      pin    5  Pin_5                -> SPARE_P220
      pin    6  Pin_6                -> SPARE_P221
      pin    7  Pin_7                -> SPARE_P222
      pin    8  Pin_8                -> SPARE_P223
      pin    9  Pin_9                -> SPARE_P224
      pin   10  Pin_10               -> SPARE_P225
      pin   11  Pin_11               -> SPARE_P226
      pin   12  Pin_12               -> SPARE_P227
      pin   13  Pin_13               -> SPARE_P228
      pin   14  Pin_14               -> SPARE_P229
      pin   15  Pin_15               -> SPARE_P230
      pin   16  Pin_16               -> SPARE_P231
      pin   17  Pin_17               -> SPARE_P232
      pin   18  Pin_18               -> SPARE_P233
      pin   19  Pin_19               -> SPARE_P234
      pin   20  Pin_20               -> SPARE_P235
      pin   21  Pin_21               -> SPARE_P236
      pin   22  Pin_22               -> SPARE_P237
      pin   23  Pin_23               -> SPARE_P238
      pin   24  Pin_24               -> SPARE_P239
      pin   25  Pin_25               -> SPARE_P240
      pin   26  Pin_26               -> GND

J34  (HDR_J34)
      footprint: Connector_PinHeader_2.54mm:PinHeader_2x13_P2.54mm_Vertical
      pin    1  Pin_1                -> GND
      pin    2  Pin_2                -> SPARE_P241
      pin    3  Pin_3                -> SPARE_P242
      pin    4  Pin_4                -> SPARE_P243
      pin    5  Pin_5                -> SPARE_P244
      pin    6  Pin_6                -> SPARE_P245
      pin    7  Pin_7                -> SPARE_P246
      pin    8  Pin_8                -> SPARE_P247
      pin    9  Pin_9                -> SPARE_P248
      pin   10  Pin_10               -> SPARE_P249
      pin   11  Pin_11               -> SPARE_P250
      pin   12  Pin_12               -> SPARE_P251
      pin   13  Pin_13               -> SPARE_P252
      pin   14  Pin_14               -> SPARE_P253
      pin   15  Pin_15               -> SPARE_P254
      pin   16  Pin_16               -> SPARE_P255
      pin   17  Pin_17               -> SPARE_P256
      pin   18  Pin_18               -> SPARE_P257
      pin   19  Pin_19               -> SPARE_P258
      pin   20  Pin_20               -> SPARE_P259
      pin   21  Pin_21               -> SPARE_P260
      pin   22  Pin_22               -> SPARE_P261
      pin   23  Pin_23               -> SPARE_P262
      pin   24  Pin_24               -> SPARE_P263
      pin   25  Pin_25               -> SPARE_P264
      pin   26  Pin_26               -> GND

J35  (HDR_J35)
      footprint: Connector_PinHeader_2.54mm:PinHeader_2x13_P2.54mm_Vertical
      pin    1  Pin_1                -> GND
      pin    2  Pin_2                -> SPARE_P265
      pin    3  Pin_3                -> SPARE_P266
      pin    4  Pin_4                -> SPARE_P267
      pin    5  Pin_5                -> SPARE_P268
      pin    6  Pin_6                -> SPARE_P269
      pin    7  Pin_7                -> SPARE_P270
      pin    8  Pin_8                -> SPARE_P271
      pin    9  Pin_9                -> SPARE_P272
      pin   10  Pin_10               -> SPARE_P273
      pin   11  Pin_11               -> SPARE_P274
      pin   12  Pin_12               -> SPARE_P275
      pin   13  Pin_13               -> SPARE_P276
      pin   14  Pin_14               -> SPARE_P277
      pin   15  Pin_15               -> SPARE_P278
      pin   16  Pin_16               -> SPARE_P279
      pin   17  Pin_17               -> SPARE_P280
      pin   18  Pin_18               -> SPARE_P281
      pin   19  Pin_19               -> SPARE_P282
      pin   20  Pin_20               -> GND
      pin   21  Pin_21               -> GND
      pin   22  Pin_22               -> GND
      pin   23  Pin_23               -> GND
      pin   24  Pin_24               -> GND
      pin   25  Pin_25               -> GND
      pin   26  Pin_26               -> GND

J36  (HDR_J36)
      footprint: Connector_PinHeader_2.54mm:PinHeader_1x03_P2.54mm_Vertical
      pin    1  Pin_1                -> GND
      pin    2  Pin_2                -> UART1_RX
      pin    3  Pin_3                -> UART1_TX

J37  (HDR_J37)
      footprint: Connector_PinHeader_2.54mm:PinHeader_1x07_P2.54mm_Vertical
      pin    1  Pin_1                -> GND
      pin    2  Pin_2                -> MSC1_CLK
      pin    3  Pin_3                -> MSC1_CMD
      pin    4  Pin_4                -> MSC1_D0
      pin    5  Pin_5                -> MSC1_D1
      pin    6  Pin_6                -> MSC1_D2
      pin    7  Pin_7                -> MSC1_D3_CD

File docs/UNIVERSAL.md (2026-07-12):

# Teacup Universal — modular Ingenic dev platform

A two-board architecture that lets one baseboard host **any** Ingenic T-series /
A1 SoC by swapping a small per-SoC module. Package (QFN88 / QFN96 / BGA232 / …)
stops mattering — each SoC's package-specific fanout is absorbed by its module,
which presents a standard edge to a common socket.

- **Interposer** — the per-SoC module: SoC + package fanout + decoupling + clock
  + (optional) local power + (optional) NOR + straps, presented on a card edge (DDR4 UDIMM-288, §1).
- **Carrier** — the universal baseboard: card-edge socket + all peripherals + full
  pin breakout + 5V input + adjustable SoC power.

Terminology note: "interposer" = SoC module; "carrier" = baseboard. (Reversed
from some earlier notes — this doc is canonical.)

---

## 1. Connector: DDR4 UDIMM-288 card-edge socket (in use for this build)

A **card-edge** connector: module side = gold fingers (a fab option, $0 parts),
socket on the carrier. Chosen over Socket 370 (module needs machined pins — cost
on the part you build most) and mezzanine stacks (delicate for bench swapping).
Fingers escape perpendicular on their own layer; single row per face, so no
pad-to-pad routing. We use it **mechanically only** — the pinout is ours (§8).
4-layer carrier suffices (no PCIe/DDR crossing the edge).

**This build uses the DDR4 UDIMM-288 desktop socket.** §1a below keeps the
SO-DIMM-260 / MXM3-314 comparison and part numbers on file — the card-edge
approach is shared across all three, so re-spinning to a different socket later
(e.g. a compact camera-only build on SO-DIMM-260) reuses everything in this
section except the connector footprint and edge geometry.

**Part: Foxconn AH58893-T9B10-3F** (LCSC **C42403003**, SMD vertical, 288-position,
0.85 mm pitch). Verified on LCSC 2026-07-10: **738 in stock**, $1.93 (1+) down to
$1.26 (100+), EasyEDA footprint + symbol available for conversion to KiCad. Premium
alt if this part ever dries up: Amphenol FCI **DDR4288V0213TF** (Mouser
523-DDR4288V0213TF) — pin-compatible DDR4 UDIMM-288 socket, drop-in mechanical
substitute.

**Why UDIMM-288:** most capable and most forgiving option for a do-everything
bench that must host **A1 + SATA**. **0.85 mm pitch** (coarsest of the three
options in §1a) makes the edge fingers easiest to fab and the contacts most
robust. **288 pins → ~93 grounds**, the headroom that keeps A1's SATA (3 Gbps) +
HDMI TMDS and dual 2-lane MIPI cleanly flanked. A **heavy-duty high-cycle socket**
built for constant re-insertion, and the bigger card gives the BGA parts (A1
BGA356, T40) room to fan out. **JLCPCB-assemblable with real, verified stock** —
the deciding factor over the fine-pitch MXM3-314 (JAE discontinued, effectively
unsourceable) and the more compact SO-DIMM-260 (still viable — kept on file in
§1a for a future compact re-spin, but 288 already clears the full superset with
margin, so there's no reason to carry two connector footprints through this
build). Trade-off accepted: **~133 mm socket length**, full-width card latch at
both ends, can't be shortened — the carrier and interposer run large. That size
is the price of the margin.

**Footprint / symbol:**
- **Foxconn AH58893-T9B10-3F**: <https://www.lcsc.com/product-detail/C42403003.html> — pull the EasyEDA footprint + symbol from this page and convert to KiCad (same workflow as the QFN96 and FFC footprints built for the T41 board — see `old/hw/teacup.pretty/`).
- Premium alt **Amphenol FCI DDR4288V0213TF**: <https://www.mouser.com/ProductDetail/523-DDR4288V0213TF>
- Socket **orientation: vertical** (card stands up, desktop-RAM style — matches "interposer plugs into carrier like a DIMM"). **Stack height** TBD once the carrier floorplan sets component clearance underneath.

**Interposer mechanical:**
- **PCB thickness = 1.0 mm ±0.1** (DDR4 UDIMM card-edge spec). Hard requirement —
  too thick won't seat / spreads the contacts, too thin = intermittent. Standard
  JLCPCB/PCBWay thickness; 4–6 layer at 1.0 mm is fine.
- **Edge geometry is fixed by the socket:** gold-finger row (144/face at 0.85 mm ≈
  122 mm span → ~133 mm card width), the DDR4 **UDIMM key notch** at its JEDEC
  position, and the **side latch cut-outs**. Copy from the DDR4 UDIMM mechanical
  drawing.
- **Depth + component layout are ours** — the card only needs to be as deep
  (~20–30 mm) as fits the SoC island. Put the SoC + tall parts (NOR SOIC ~1.75 mm,
  buck inductor ~1.2 mm, crystal ~0.8 mm) on the **top** face; keep the bottom
  (toward the carrier) low-profile. The socket floats the card above the carrier
  at its stack height, so ~1.75 mm tall parts clear easily.

### 1a. Other connector options (reference only — not used in this build)

Kept on file in case a future variant re-spins away from UDIMM-288 (e.g. a
compact camera-only build with no A1/SATA target). All three share the
gold-finger card-edge approach; only pitch, length, card thickness, and the
carrier footprint differ.

| | **DDR4 UDIMM-288 desktop (in use)** | **DDR4 SO-DIMM-260 (compact option)** | **MXM3-314 (backup premium)** |
|---|---|---|---|
| Contacts | 288 | 260 | 314 |
| Pitch | **0.85 mm** (coarsest, easiest) | 0.5 mm | 0.5 mm |
| Socket length | ~133 mm (longest) | ~68 mm (compact) | ~90 mm |
| Card thickness | 1.0 mm | 1.0 mm | 1.2 mm |
| Cost | ~$1.3–1.9 | ~$0.83–1.67 | ~$10.69–17 |
| LCSC / JLCPCB | **SMD, 738 stock** (verified) | deep, sustained | last 25, discontinued |
| Ground headroom | **~93** | ~65 | ~119 |
| Trade | rugged + coarse + max-ground, **big board** | compact, cheap | fine pitch, **scarce** |

**SO-DIMM-260 — the compact / JLCPCB-friendly option.** ~68 mm, ~$1, and **the
deepest, most sustained LCSC stock of the three** (verified thousands: Foxconn
ASAA821-E8SB0-7H C2925427, AS0A826-H2SB-7H C2761525). Its 260 pins still clear the
full superset (~180 sig + 15 pwr + 65 gnd, §8), so a **camera-only build** (no A1
SATA/HDMI) is ideal on 260 — smaller, cheaper, fully JLCPCB-built. Re-spin to this
when A1 isn't a target.

**MXM3-314 — backup premium.** A fading laptop-GPU part (JAE discontinued, ACES
0-stock, only 25 on LCSC), kept for when you want max grounds and don't mind
hand-soldering an Amphenol socket. Fine 0.5 mm pitch, ~90 mm.

**Footprints / links:**
- **DDR4 SO-DIMM Foxconn ASAA821-E8SB0-7H** (compact build; EasyEDA footprint on LCSC): <https://lcsc.com/product-detail/Memory-Connector-DDR_FOXCONN-ASAA821-E8SB0-7H_C2925427.html> — also AS0A826-H2SB-7H (C2761525, ~2800 stock)
- MXM3 Amphenol 10151114-001TLF footprint+symbol: <https://www.snapeda.com/search/?q=10151114-001TLF&search-type=parts>; JAE MM70-314B1-2-R300 (LCSC C4818180, last 25)

**If re-spinning to SO-DIMM-260:** edge geometry becomes ~130/face at 0.5 mm ≈
65 mm → ~68 mm card width, SO-DIMM key notch (distinct JEDEC position from
UDIMM). Card thickness stays 1.0 mm ±0.1. MXM3-314 uses 1.2 mm card thickness and
its own notch/latch geometry per the Amphenol/JAE mechanical drawing.

---

## 2. Power architecture

The SoC core and DDR voltages are **SoC-specific** (section 3); everything else
(1.8 V, 3.3 V) is universal. That single fact drives the whole power design.

Two build modes, supported by **one connector** via bidirectional VCORE/VDDR:

| Mode | Interposer holds | Carrier holds | Result |
|---|---|---|---|
| **A — self-contained** | SoC, clock, decap, **own bucks**, straps, (NOR) | 5V, peripherals, breakout | boots on any carrier or bare on the bench |
| **B — minimal** | SoC, clock, decap, straps | **adjustable VCORE+VDDR**, peripherals | dead-simple module, needs its carrier to boot |

**The contract:** VCORE and VDDR are bidirectional connector nets. Exactly **one
driver per rail per build** — either the interposer's buck *or* the carrier's
adjustable buck, never both. Stuffing decides. 1.8 V / 3.3 V are always carrier-
sourced (universal). This lets cheap dumb interposers and premium self-contained
ones share the same baseboard.

Hard SI rules (why the interposer can't just draw everything across the edge):
- **Decoupling is mandatory on the interposer**, within mm of the SoC balls,
  vias straight to plane. A cap behind the connector's per-pin inductance is
  useless above a few MHz.
- **Sensor MIPI crosses the socket to carrier camera FFC(s) — and it's budgeted.**
  §8 already puts **2× CSI (dual 2-lane MIPI) in the 260 superset** on a carrier FFC,
  with ~65 grounds to spare — so cameras on the carrier is the default, not a pin
  problem. It crosses fine: D-PHY here is 1.5 Gbps/lane (T33/T40) to 2 Gbps/lane
  (T41), and **both sockets are qualified well past that** — DDR4 SO-DIMM passes
  DDR4-3200 (~1.6 GHz differential DQS + 3.2 GT/s DQ), MXM3 carries 8 GT/s PCIe Gen3
  — with flanking-ground pairs + length match. An interposer **may also** carry its
  own camera FFC (optional) for a self-contained mode-A module or the shortest
  sensor channel, but — unlike the clock below — it is **not required** to stay local.
  The only config that overflows 260 is dual 2-lane MIPI **plus** a full 16-bit DVP
  broken out simultaneously (+~36 pins) — which no single SoC implements (§10); the
  UDIMM-288 / MXM3-314 options exist for that phantom case.
- **Clock stays on the interposer — this one is a hard rule** (unlike MIPI above).
  EXCLK_XIN/XOUT are **high-Z analog oscillator nodes**; socket stub capacitance
  detunes the crystal loop and kills 24 MHz startup margin. Different mechanism from
  a driven, terminated differential link — a connector that passes 8 GT/s PCIe still
  can't carry a pico-amp oscillator node. RTC 32.768k crystal too, where used.
- **Mode-B VCORE sense — no analog remote-sense across the connector.** Putting the
  buck's feedback loop through the socket's finger inductance invites instability,
  and it costs pins. Instead, a three-part scheme that's DC-accurate *and*
  loop-stable:
  1. The carrier buck **Kelvin-senses at the connector** (carrier side) — kills
     the carrier-trace IR drop, keeps the connector out of the control loop.
  2. **Parallel several VCORE + GND fingers** so the connector's DC resistance is
     tiny (≈4 VCORE fingers → ~10 mV drop at 2 A) — within the ±5 % core margin.
  3. **Strong interposer decoupling** carries the *fast* transient. Above the buck's
     loop bandwidth (~100s of kHz) no sense scheme helps — that energy can only
     come from local C, and the connector inductance is why it must be local.
  4. For the residual DC error and for margining, a high-Z **VCORE_SNS** pin runs
     from the interposer point-of-load back to the **BMC ADC** (§9): the BMC reads
     the *true ball voltage* and trims the digipot (§2 above) to hit target —
     **software remote-sense.** Slow, exact, unconditionally stable, and it's the
     same measurement voltage-margining already needs. One connector pin.

**Digital voltage control (digipot) — software-set VCORE/VDDR + margining.** In
mode B, digitize each buck's FB divider with a **dual non-volatile I²C digipot:
MCP4661-104E/ST** (Microchip, TSSOP-14, **100 kΩ**, 257 taps, 2.7–5.5 V supply).
Confirmed direct from the Microchip datasheet; well-stocked at DigiKey
(1,062 units, verified 2026-07-11) — the LCSC listing for this exact TSSOP-14/
100 kΩ combination is thin-to-absent (only a QFN `-T.../ML` tape-and-reel
variant turns up, C144215), so DigiKey is the primary source for this part;
sub any dual-NV I²C pot if BOM sourcing needs a package change.

**Why 100 kΩ, not a lower value:** the pot's three terminals sit directly
across the FB divider (VOUT-to-GND, wiper to FB), so its `RAB` draws a small
continuous current off the rail it's regulating — at 1.8 V (VDDR) that's
**~18 µA on 100 kΩ** vs. ~180 µA on 10 kΩ or ~360 µA on 5 kΩ (the other two
MCP4661 stock options considered, C637131/10 kΩ and C145605/5 kΩ — both also
thin-to-out-of-stock at LCSC). Buck FB-pin bias current is nanoamp-class on
these parts, so 100 kΩ doesn't hurt divider accuracy — it just cuts the pot's
own quiescent draw by 10–20×, which matters since this current runs
continuously on every powered rail, not just during a margining sweep.
257 taps over 100 kΩ ≈ **~390 Ω/step**, still ≈1 mV/step-class resolution
over the VCORE/VDDR span once folded through the ratiometric divider math
below. The **ESP32 BMC** (§9)
sets it, making the whole power path software-defined and unlocking **voltage
margining**: the agent can sweep VCORE to find a SoC's minimum-stable core voltage,
undervolt headroom, and stability margins — real characterization, LLM-driven.
- **Ratiometric** — use the pot as the divider ratio so its ±20% absolute
  tolerance cancels; only the ratio sets voltage.
- **Loop stability** — the wiper R/C sits on the FB node; keep the feed-forward
  cap and check the buck's compensation.
- **Safe sequencing (critical)** — the BMC **sets the digipot *then* enables the
  rail** (load switch / buck EN), so VCORE is never brought up over-voltage on a
  0.8 V part. The NV pot retains its setting across power cycles; the BMC-gated
  enable covers the very first boot. This is the resolution to mode-B FB safety.

**VCORE/VDDR voltage-select jumpers — hardware-deterministic default,
supersedes the digipot-safety procedure above (decided).** The sequencing
rule above depends on the BMC having actually run at least once to write a
safe value into the digipot's NV memory — true after first bring-up, but the
same gap reopens every time an interposer is swapped for a different SoC: the
digipot's *stored* value belongs to whatever was seated last, not what's
seated now. Rather than trust NV memory (or gate power behind a manual
one-time procedure, the earlier `JP1`/bring-up-checklist approach — see git
history, now removed), `U1`/`U2`'s FB pins are the common pole of a physical
jumper bank instead of being hard-wired to the digipot wiper:
- **4 fixed presets for VCORE** (0.8/0.9/1.0/1.1 V, covering every SoC in §3's
  rail table) **+ 3 for VDDR** (1.35/1.5/1.8 V), each a plain two-resistor
  divider off the buck's own FB reference (0.6 V / 0.8 V respectively),
  permanently powered across VOUT/GND regardless of jumper position (~50-100
  µA each, negligible) so only the *selected* network's midpoint is ever
  electrically tied to FB.
- **One more position routes FB to the digipot wiper exactly as before** — the
  EEPROM-on-interposer → BMC-reads-it → BMC-writes-digipot flow (§7) still
  works whenever this position is deliberately selected, and *only* then.
- Populate exactly one shunt per regulator — none leaves FB floating
  (dangerous), two shorts two dividers together (undefined voltage).
- **The user sets these by hand** for whichever interposer is seated. Manual,
  but that's what removes the unsafe window: a preset position is correct
  voltage from the very first switching cycle, with zero dependency on
  firmware, I²C, or what happened to be left in NV memory from the last
  interposer. Values deliberately biased slightly low rather than high —
  safer to undervolt an unknown SoC than overvolt it.
- Consequence: `SW2`'s pole now ties straight to `+5V_ALT`, no gating jumper —
  the overvoltage risk that gate existed to prevent is now prevented in
  hardware on the FB path itself, regardless of what `SW2` or the digipot do.

---

## 3. SoC input-rail reference (T10 → A1)

Nominal voltages from each SoC's `*_BOARD_DESIGN_GUIDE` / datasheet in
`~/projects/thingino/ingenic-docs`. Core/DDR vary; 1.8/3.3 are universal.

| Rail | T10/T20 | T21 | T23 | T30 | T31 | T32 | T33 | T40 | T41 | A1 |
|---|---|---|---|---|---|---|---|---|---|---|
| **VDD core** | 1.1 | 1.0 | 0.8 | 1.0 | 0.8 | 0.8 | 0.9 | 0.9 | 0.8 | 0.9 |
| **DDR** (VDDMEM/DDRVDD) | 1.8 | 1.8/1.5 | 1.8/1.5 | 1.8 | 1.8/1.5/1.35 | 1.5/1.35 | 1.35/1.5/1.8 | 1.35 | 1.35/1.5/1.8 | 1.8 |
| **+1.8 V** analog/IO | DVP only† | 1.8 | 1.8 | 1.8 | 1.8 | 1.8 | 1.8 | 1.8 | 1.8 | 1.8 |
| **+3.3 V** IO | 3.3 | 3.3 | 3.3 | 3.3 | 3.3 | 3.3 | 3.3 | 3.3 | 3.3 | 3.3 |
| **+0.9 V** analog (PLL_VDD/USB_09/CSI_09) | 1.1 | 1.0 | 0.8 | 1.0 | 0.8 | 0.8 | 0.9 | 0.9 | int‡ | 0.9 |
| EFUSE (burn only) | **2.5** | 1.5 | 1.8 | **1.5** | 1.8 | 1.8 | 1.8 | 1.8 | 1.8 | 1.8 |

T30 confirmed from `T30 ... Data Sheet.20180416`: core 1.0 V, DDR 1.8 V (DDR2),
1.8 analog, 3.3 IO, RTC 1.0 V, EFUSE 1.5 V.
† **T10/T20 is the outlier** — 65 nm-era: core 1.1 V, analog (ADC/CODEC/PLL-HV) on
**3.3 V** not 1.8, EFUSE 2.5 V. It only uses 1.8 for the DVP sensor.
‡ On **SIP-QFN** parts (T31ZX, T41NQ/XQ) the 0.8–0.9 V analog sub-rails are
internal — not externally supplied. A1 and the older/non-SIP parts expose them.

DDR notes: value depends on the SoC's DDR variant (DDR2 = 1.8, DDR2L/DDR3 = 1.5,
DDR3L / T31A / T40 / T41 = 1.35). All target SoCs except the DDR3 spins are SIP,
so DDRVDD feeds the in-package die — no external DDR bus, but the rail is still
required at the right voltage.

Analog sub-rails (USB_AVD33/18/09, PLL_AVDD, CSI_VCC, CODEC_AVDD, and A1's
VGA/HDMI_AVDD plus **SATA0/1_VCC 0.9 V + SATA0/1_VCCH 1.8 V** with a SATA_RBIAS
2 kΩ 1% ref) are the **same voltages** as the main rails but must be
**bead-isolated** (1 kΩ@100 MHz) separate nets — they are their own domains for
test/probe purposes (section 6). The SATA PHY analog rails live on the **A1
interposer** (like all SoC-specific analog), fed from the carrier 0.9/1.8 through
their own beads.

---

## 4. Regulator spec (sized to the worst SoC)

Current minimums are stated in the board design guides (VDDCORE: T40/T41/A1 say
≥2A, T10–T31 say ≥1A; VDDMEM: all say ≥1A). Analog rails spec bead isolation
(tens of mA each) — aggregates below are conservative.

| Rail | Voltage | Max current | Ripple | Regulator |
|---|---|---|---|---|
| **VCORE** | 0.8–1.1 V adj | **2 A** (T40/T41/A1) | ≤60 mVpp | Adjustable buck **≥3 A**, FB-set by interposer — **AP62600SJ-7** (in use; alternatives on file in §4a) |
| **VDDR** | 1.35–1.8 V adj | **1 A** | ≤70 mVpp | Adjustable buck **≥1.5 A**, FB-set by interposer — **AP62300WU-7** (in use; SY8089-class notes on file in §4b) |
| **+1.8 V** | 1.8 V | ~0.5 A | low | buck/LDO ≥1 A |
| **+3.3 V** | 3.3 V | ~0.5 A SoC + peripherals | low | buck **≥2 A** (shared w/ carrier peripherals) |
| **+0.9 V analog** | 0.8–0.9 V | ~0.15 A | low | tiny LDO **on the interposer** (A1/old only; internal on SIP-QFN) |
| EFUSE program | 1.5 / 1.8 / 2.5 V | <50 mA one-shot | — | jumper-fed pad, **not** a continuous reg |
| **+5 V in** | 5 V | ~1.5 A SoC + peripherals → **spec ≥3 A** | — | barrel or USB-C |

**The two that matter on the carrier: an adjustable ≥3 A VCORE buck + an
adjustable ≥1.5 A VDDR buck**, both voltage-programmed by a feedback resistor on
the interposer (plug T41 → 0.8 V, T40 → 0.9 V, T20 → 1.1 V; auto-set). The 2 A
XBurst2 core requirement is what sets the VCORE size — a T41-only board could use
2 A (as teacup-neo does with SY8089), but universal must carry the worst case.

**VCORE buck part: AP62600SJ-7** (Diodes Incorporated, VQFN2030-12, LCSC
**C4748917**). **4.5–18 V input**, 0.6 V–adj output (0.6 V ±1% reference, standard
external resistive divider — same ratiometric-digipot scheme as §2), **6 A**,
1.2 MHz, full-feature synchronous buck. Datasheet confirmed direct from
Diodes Inc. (DS42003 Rev. 3); sourceable through DigiKey (2,218 in stock,
verified 2026-07-10) and Mouser — LCSC listing exists (same part number, priced)
but was out of stock at last check, so DigiKey is the primary source for now.

Replaces two earlier candidates (both kept below, §4a) after two problems
surfaced in sequence:
1. **MP2315GJ-Z** (first pick) has a **0.8 V output floor** — exactly the nominal
   VCORE for four target SoCs (T23/T31/T32/T41, §3), leaving **zero undervolt
   headroom** for the voltage margining §2 requires. Disqualifying.
2. **MP2143DJ-LF-Z** (second pick) fixes the floor (0.6 V) but its **2.5–5.5 V
   input range** puts `vSafe5V`'s 5.5 V worst case exactly at the top of its
   *recommended* operating range with no buffer against a real-world
   out-of-spec 5 V source (e.g. an unregulated wall wart sitting at 5.6–5.8 V) —
   not an absolute-max violation (abs-max is ~6 V), but outside the
   manufacturer's guaranteed-performance window, an avoidable risk on a bench
   board meant to accept whatever 5 V supply is on hand.

AP62600 solves both at once: **0.6 V floor** (full margining headroom on every
0.8 V-nominal SoC) and **4.5–18 V input** (~12.5 V of margin above the
`vSafe5V` worst case — any plausible "5 V" source is comfortably inside its
rated continuous range). 6 A capability is well past the ≥3 A spec, with room
to spare. One trade-off worth noting: **VQFN2030-12**, not the TSOT23-8 package
of the other two candidates — the interposer/carrier footprint library will
need this land pattern, not a reuse of the SOT23 one.

### 4a. VCORE buck — earlier candidates (reference only, not used in this build)

Kept on file since both were genuinely considered and each remains a valid
option for a future re-spin with different constraints (e.g. a build that
never needs sub-0.8 V margining, or one with a tightly-regulated, known-clean
5 V input where AP62600's extra input headroom buys nothing).

**MP2315GJ-Z** (Monolithic Power Systems, TSOT23-8, LCSC **C45889**). 4.5–24 V
input, 0.8 V–adj output, **3 A**, 500 kHz, current-mode control. Datasheet
confirmed on LCSC; sourceable through DigiKey/Mouser/LCSC. Originally picked
for its wide 4.5–24 V input margin — a nominal 5 V input sits comfortably
mid-range, better than MP2143's tight ceiling. **Disqualified by its 0.8 V
output floor**: exactly the nominal VCORE for T23/T31/T32/T41 (§3), which
leaves no room for the voltage margining §2 requires on those parts. Still a
fine choice for a build that doesn't need to undervolt-margin an 0.8 V-core SoC.

**MP2143DJ-LF-Z** (Monolithic Power Systems, TSOT23-8). 2.5–5.5 V input, 0.6 V–adj
output, 3 A, 1.2 MHz, constant-on-time (COT) control, 40 µA quiescent current.
Also available in a 10-pin QFN (VFDFN) variant. COT control gives faster
transient response and can ease loop compensation versus current-mode control —
worth revisiting if VCORE ripple/transient performance with AP62600 turns out
marginal in bring-up, or for a build with a lower, tightly-regulated input rail
where the 5.5 V ceiling isn't a practical concern (its 0.6 V output floor is
identical to AP62600's, so margining isn't the issue here — input margin is).
Its 5.5 V top-of-range is genuinely within its *rated continuous* operating
window (not a stress condition) — the concern is zero buffer above that line
if the actual 5 V source runs even slightly hot, not that 5.5 V itself is unsafe.

**VDDR buck part: AP62300WU-7** (Diodes Incorporated, TSOT-23-6/TSOT26, LCSC
**C1880390**). **4.2–18 V input**, 0.8 V–adj output (0.8 V ±1% reference,
external resistive divider), **3 A**, 750 kHz, COT synchronous buck. Datasheet
confirmed direct from Diodes Inc.; well-stocked at both DigiKey (5,941 units,
verified 2026-07-10) and LCSC (2,525+ units, JLCPCB-listed) — better supply
position than AP62600's current LCSC gap.

Same family as the VCORE pick (§4 above) for a consistent vendor/footprint/
FB-divider-and-digipot story across both bucks, but right-sized rather than
reusing AP62600: VDDR only needs ≥1.5 A (spec, §4 table) against a 1 A actual
load, so **AP62300's 3 A is ample headroom without the cost/board-space of a
6 A part**, and its wide **4.2–18 V input** gives the same `vSafe5V`-margin
protection as AP62600, for the same reason (§4 above).

**On the 0.8 V floor — not disqualifying here, unlike VCORE.** AP62300's FB
reference is 0.8 V (not the 0.6 V of the AP62600 chosen for VCORE). For VCORE
that floor was disqualifying because it equals several SoCs' *nominal* core
voltage (§3), leaving zero undervolt headroom. VDDR is different: the lowest
DDR nominal across every target SoC is **1.35 V** (DDR3L, §3), so an 0.8 V
floor still leaves **~550 mV (41%) of undervolt headroom** — far more than any
realistic DDR margining sweep needs. No part change required to keep §2's
margining goal intact on this rail.

### 4b. VDDR buck — earlier note (reference only, not used in this build)

**SY8089A1AAC** (Silergy, SOT-23-5) — the part the single-SoC T41 board
(teacup-neo's predecessor / `old/`) used for its VCORE/VDDR supplies at 2 A,
referenced above (§4) for context on why a T41-only board could get away with
a smaller part than the universal platform's worst-case sizing requires. Not
carried forward as the VDDR pick here: it's a **fixed small-current-class**
part family sized for a single known SoC, not chosen against the universal
board's ≥1.5 A / wide-input-margin / FB-digipot-margining requirements the way
AP62300 was — kept on file as the historical reference point, not as a
rejected candidate that was evaluated head-to-head against AP62300.

---

## 5. Clock, flash, boot

- **Clock**: 24 MHz crystal + 1 M start + 33 R series on the **interposer**, tight
  to the SoC. RTC 32.768 kHz crystal on the interposer where the SoC has RTC.
  **Part: Seiko SC-32S** (32.768 kHz, **12.5 pF** load cap, ±20 ppm, SMD3215-2P,
  **0.75 mm** tall, LCSC **C97606**). Datasheet-confirmed spec; LCSC shows
  31,865 in stock (verified 2026-07-11, ~$0.13–0.23/unit). 12.5 pF is the
  de facto standard RTC crystal load cap this family's SoCs are designed
  around (T41's board design guide calls out an external 32.768 kHz clock
  without stating a different value, and 12.5 pF is standard across the
  industry absent a SoC-specific override) — confirm per-SoC if a future
  datasheet specifies otherwise. 0.75 mm height matches the crystal budget
  already assumed in §1's interposer stack-height note. A smaller sibling,
  **Seiko SC-20S** (SMD2012-2P, 0.6 mm, LCSC C97607, 5,045 in stock), is a
  drop-in if a future interposer is tight enough on board space to need it —
  same electrical spec, smaller footprint, just less deep stock.
- **NOR flash — dual location, optional on the interposer**:
  - 8-pad SPI NOR (W25Q-class) footprint on the interposer = **optional stuff**.
  - Carrier carries its own NOR too.
  - **Only the CS0 device is bootable**, and two flashes can't share CS0. So the
    boot flash owns CS0; the other is disconnected or demoted to a GPIO-CS as
    software-only storage (the Teacup SW2 CS-disconnect switch is the precedent).
  - Populate interposer NOR + flip CS-disconnect → module boots from its own
    flash = **self-contained** (mode A). Leave it empty → boots from carrier NOR
    = **dependent** (works with this carrier). The stuffing *is* the mode choice.
  - SFC bus (CLK + IO0-3 + CS ≈ 6 pins) crosses the connector to reach carrier
    NOR; keep the stub short or series-terminate at speed.
  - Free recovery: bootrom order **SFC → SD → USB**, so no-flash-found drops to
    SD then USB-boot on its own.
  - **The carrier's own NOR is itself dual — soldered primary + socketed
    alternate — matching the single-board Teacup's U4/U5 precedent exactly,
    not a single fixed chip.** Carrier stuffs a soldered SOIC-8 **W25Q32JVSS**
    (primary, always populated) *and* a DIP-8 socket (alternate/recovery,
    user-populated) on the **same shared SFC bus** (CLK/IO0-3 tied together),
    each with its own independent CE line. CE arbitration is **two
    TS5A3166DBVR** analog switches gated from ESP32 GPIO (§9's flash-select
    row). A 3-position manual switch (**SSSS711403**, same part as the
    reference board's manual CS switch) sits alongside as a *sense* input the
    ESP32 reads to decide which switch to enable — so, unlike the power-source
    override switch below (§9), this selection currently still requires BMC
    firmware to be running; it is not a direct hardware override.

---

## 6. Test points — interposer MVP + carrier instrumentation

**Directive (CaptainRon):** the interposer should carry the minimum to be a
**self-contained testable system off the carrier** — just test pads for a minimum
viable system. Baseline set:
- **USB pads** — the SoC USB (D+/D−/VBUS/GND), for **DFU flashing + USB gadget**
  standalone. The primary bring-up interface: Ingenic parts load firmware via
  bootrom **USB boot / DFU**, so this is how you flash a bare interposer with no
  carrier. Short stub off the USB line (the same USB also crosses the connector to
  the carrier's USB-C); keep the tap short for HS integrity, or castellated pads /
  a micro-USB for convenience.
- **UART pad** — debug console (UART1), to watch boot alongside the USB flash.
- **Flash chip pads** — the 8-pad SPI NOR footprint (boot + direct program).
- **Voltage pads** — power-in / probe for each rail (below).
- **Clock** — the 24 MHz crystal (already local per §5).

With USB + UART + power + NOR, a bare interposer is fully bring-up-able: power it,
**DFU-flash over USB**, watch the console over UART — the complete standalone loop.

Power it, console it, flash it **on the bench with no carrier at all.** This *is*
the self-contained interposer (mode A) — the pads just make bring-up + fault-find
possible before the carrier exists.

**Voltage pads — fuller version (per isolated domain).** For fault-isolation
granularity, place a pad on the SoC side of each rail's bead/0R so a domain can be
isolated and injected — per **isolated domain**, not per voltage:

`VCORE · VCORE-analog(0.9) · VDDR · +1.8-digital · +1.8-analog · +3.3-digital ·
+3.3-USB(USB_AVD33) · +5V · GND · EFUSE-program`

~7 rail pads for a fully-isolated interposer; a couple collapse into the chip on
SIP-QFN parts. A1 (USB ×3 + VGA + HDMI islands) is the worst case for pad count.
For the MVP, the coarse set (VCORE, VDDR, +1.8, +3.3, +5V, GND) is enough.

**Carrier instrumentation (test points throughout).** Beyond the full signal
breakout (§8 — every SoC pin at a labeled header, which doubles as a test point):
- **Power rails** — a labeled probe pad on each carrier rail: +5V, +3.3, +1.8,
  VCORE, VDDR.
- **Buck debug** — bring each buck's **SW (LX) node** and **FB node** to a pad, to
  scope switching ripple / loop behavior during power bring-up.
- **BMC control lines** — BOOTSEL, reset-EN, flash-select, PPRST_ — pads to observe
  or manually override the ESP32.
- **I²C** (digipot + ID EEPROM) — SDA/SCL pads to sniff / bit-bang.
- **Boot straps** — POR_CTL, BOOT_SEL0 pads on both sides.
- **Ground everywhere (the one that matters most)** — scatter **GND probe points
  next to every functional block** (each buck, the SoC/connector, USB, the MIPI
  FFC, the BMC). A scope's ground lead must be short — long leads ruin high-speed
  measurements. Cheap and load-bearing.

**Convention:** every test pad **silkscreen-labeled**, one consistent footprint
(1.0 mm round or a TP part), kept clear of connectors/tall parts so a probe or clip
reaches it. A well-instrumented board debugs in minutes; a bare one costs hours.

---

## 7. Carrier ID

A small **I2C EEPROM** (or 3–4 resistor-strapped ID pins) on the interposer so:
- software auto-selects the right DFU / flash / DT profile;
- in mode B, the carrier reads the ID and sets the adjustable VCORE/VDDR (or the
  interposer just FB-sets them directly with a resistor — simpler, no firmware).

**Part: 24AA025E48T-I/SN** (Microchip, SOIC-8, 2 Kbit / 256×8 I²C EEPROM,
1.7–5.5 V, 400 kHz). Datasheet confirmed direct from Microchip; DigiKey has
13,180 in stock (verified 2026-07-11, $0.40/unit) — the base `24AA025E48-I/SN`
part number is the same die, just a different tape/reel packaging suffix, and
was thin at LCSC (32 units) at last check, so DigiKey is the source for now.

**Why this part over a plain 24C02-class EEPROM:** it's **factory-programmed
with a globally unique 48-bit EUI-48 node address**, permanently burned in and
read-only — a free, guaranteed-unique serial number per interposer with zero
manufacturing-time programming step. That's a direct fit for §9's autonomous/
fleet-management goal: an agent managing many boards (or many interposers
swapped across one carrier over time) can identify *this exact physical
module* over I²C without ever having to assign or track serial numbers itself.
2 Kbit is far more than the ID needs alone, so the remaining user-writable
space holds the DFU/flash/DT profile data and VCORE/VDDR trim/calibration
values §7 already calls for — one part serves both roles. Standard I²C EEPROM
address pins are present too, though moot here since only one interposer is
ever on the bus at a time (§1's "one module seated" rule, §8).

---
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

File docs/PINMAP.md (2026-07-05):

# Teacup T31ZX -> T41NQ/XQ pin mapping notes

Full table: `pinmap_t31_to_t41.csv`. T41 pin data: `t41nq_pins.csv` (verified
identical across T41NQ/XQ/LQ datasheets - one layout serves all three).

## What maps 1:1 (same GPIO name, new pin number)

- MIPI CSI 2-lane + clock (DATAN0/CLKN/DATAN1 even keep the same pin numbers 24/26/28)
- USB0PN/PP/AVD33: same pins 35/36/37
- SFC NOR: CE/DR/DT/CLK -> SFC0 on PA23-28
- MSC0 4-bit SD: PB00-05
- GMAC RMII header: all 10 signals, PB06-16
- UART1 console: PB23/24
- Sensor I2C (SMB0/PA12,13), MCLK (PA15), sensor GPIO (PA18) - 1.8V domain preserved
- PWM0/1 (PB17/18), PB25-31 misc bank
- BOOT_SEL0 (PC00), crystal, VCM, HPOUTL, SADC input

## Remaps (T31 GPIO absent on T41 QFN96)

J4 GPIO header (was T31 PA06-11/14/16/17 @ 1.8V) -> PC bank **@ 3.3V (VDDIO2)**:

| J4 pin | was | becomes | function preserved |
|---|-----|---|---|
| J4.5 | PA06 | PC15 (pin 3)  | PWM0, EXCLK out |
| J4.6 | PA07 | PC16 (pin 4)  | PWM1, RTC32K |
| J4.7 | PA09 | PC17 (pin 5)  | PWM2, I2S_SDTO |
| J4.8 | PA08 | PC18 (pin 1)  | PWM3, I2S_SDTI |
| J4.9 | PA11 | PC14 (pin 91) | UART2_RXD |
| J4.10  | PA10 | PC13 (pin 92) | UART2_TXD |
| J4.11  | PA16 | PC19 (pin 89) | SMB1_SDA |
| J4.12  | PA14 | PC02 (pin 11) | (gains SSI0_CLK/MSC1_CLK) |
| J4.13  | PA17 | PC20 (pin 90) | SMB1_SCK |

UART0 4-wire (was PB19-22) -> PC08/09/11/12 (pins 95/94/2/96). Net-level
unchanged (USB-C SBU A8/B8 + J6). Domain: VDDIO2 must be 3.3V.

## Dropped vs T31

- **PPRST_ / reset button S2 / J9**: T41 QFN96 is POR-only. POR_CTL (pin 60,
  3.3V level) strap per vendor reference. S2/J9 deleted (or S2 repurposed to
  power-path EN for hard reset - TBD).
- External rails gone (internal on T41): PLL_VDDHV, MIPI_AVD08 (0.8V),
  USB_AVD18, DDRPLL_VCCD. Simplifies 1.8V/0.8V distribution.
- ADC_VREF + ADC_AVDD combine into single SADC_VREFP_AVDD.
- No UART boot, RTC, JTAG on QFN96.

## New on T41 (needs schematic work)

| Pin | Signal | Plan |
|-----|---|---|
| 60  | POR_CTL | strap per vendor ref (3.3V domain) |
| 83  | DDR_ZQ  | 240R 1% to GND |
| 84  | RZQ | 240R 1% to GND |
| 30  | MICNL | diff mic negative: bias/AC-couple per vendor ref |
| 42  | SFC0_WP_IO2 | wire to NOR WP# -> quad-SPI boot option |
| 45  | SFC0_HOLD_IO3 | wire to NOR HOLD# -> quad-SPI boot option |
| 6,7,10,12,13 | MSC1/SSI0 (PC03-07) | spare; test pads or new header - TBD |

## Rails delta

| Rail | T31 board | T41 board |
|---|---|---|
| Core | 0.8V (already!) | 0.8V, more pins (8), size buck >= 1.5A |
| DDRVDD | 1.8V | **1.35V DDR3L** (1.8V stuffing option -> T41LQ) |
| DDR_VREF | 100k/100k off 1.8V | same divider off 1.35V (verify vendor) |
| VDDIO18 (1.8V) | VDDIO0 | pins 17,50 + osc domain |
| VDDIO1/2 (3.3V) | 3x pins | pins 40,65 + 9 (VDDIO2 selectable, keep 3.3V) |
| EFUSE | tied GND | tied GND (programming off) |

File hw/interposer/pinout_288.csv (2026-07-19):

finger | carrier_net | t31_pin | t31_pin_name_or_note
1 | VCORE |  | SoC core/DDR rail (bidirectional)
2 | VCORE |  | SoC core/DDR rail (bidirectional)
3 | VCORE |  | SoC core/DDR rail (bidirectional)
4 | VCORE |  | SoC core/DDR rail (bidirectional)
5 | GND |  | GND
6 | MICLP | 41 | MICLP
7 | HPOUTL | 44 | HPOUTL
8 | GND |  | GND
9 | VDDR |  | SoC core/DDR rail (bidirectional)
10 | VDDR |  | SoC core/DDR rail (bidirectional)
11 | GND |  | GND
12 | GND |  | GND
13 | +3V3 |  | carrier-sourced rail
14 | +3V3 |  | carrier-sourced rail
15 | +1V8 |  | carrier-sourced rail
16 | +1V8 |  | carrier-sourced rail
17 | +5V_SW |  | carrier-sourced rail
18 | +5V_SW |  | carrier-sourced rail
19 | GND |  | GND
20 | USBA_HOST_DP | 36 | USB0PP
21 | USBA_HOST_DM | 35 | USB0PN
22 | GND |  | GND
23 | VCORE_SNS |  | BMC-only (crosses to U8, not the interposer SoC)
24 | HOSTED_DATA_READY |  | BMC-only (crosses to U8, not the interposer SoC)
25 | HOSTED_HANDSHAKE |  | BMC-only (crosses to U8, not the interposer SoC)
26 | HOSTED_SPI_CS |  | BMC-only (crosses to U8, not the interposer SoC)
27 | HOSTED_SPI_MISO |  | BMC-only (crosses to U8, not the interposer SoC)
28 | SFC_IO2 |  | BMC-only (crosses to U8, not the interposer SoC)
29 | SFC_IO1 |  | BMC-only (crosses to U8, not the interposer SoC)
30 | SFC_CLK |  | BMC-only (crosses to U8, not the interposer SoC)
31 | SFC_IO0 |  | BMC-only (crosses to U8, not the interposer SoC)
32 | SFC_CS |  | BMC-only (crosses to U8, not the interposer SoC)
33 | SFC_IO3 |  | BMC-only (crosses to U8, not the interposer SoC)
34 | RESET_EN |  | BMC-only (crosses to U8, not the interposer SoC)
35 | BOOTSEL |  | BMC-only (crosses to U8, not the interposer SoC)
36 | GND |  | GND
37 | GND |  | GND
38 | GND |  | GND
39 | GND |  | GND
40 | GND |  | GND
41 | GND |  | GND
42 | UART1_RX |  | BMC-only (crosses to U8, not the interposer SoC)
43 | UART1_TX |  | BMC-only (crosses to U8, not the interposer SoC)
44 | HOSTED_SPI_MOSI |  | BMC-only (crosses to U8, not the interposer SoC)
45 | HOSTED_SPI_CLK |  | BMC-only (crosses to U8, not the interposer SoC)
46 | I2C_ID_SCL |  | BMC-only (crosses to U8, not the interposer SoC)
47 | I2C_ID_SDA |  | BMC-only (crosses to U8, not the interposer SoC)
48 | HOSTED_RESET |  | BMC-only (crosses to U8, not the interposer SoC)
49 | GND |  | GND
50 | MSC0_D1 | 49 | MSC0_D1_SSI_SLV_DR_PB01
51 | GND |  | GND
52 | MSC0_D0 | 50 | MSC0_D0_SSI_SLV_DT_PB00
53 | MSC0_CLK | 51 | MSC0_CLK_SSI_SLV_CLK_PB04
54 | MSC0_CMD | 52 | MSC0_CMD_SSI_SLV_CE0_PB05
55 | MSC0_D3_CD | 53 | MSC0_D3_PB03
56 | MSC0_D2 | 54 | MSC0_D2_PB02
57 | GND |  | GND
58 | GND |  | GND
59 | GND |  | GND
60 | MIPI0_SCCB_SDA |  | not present on T31ZX
61 | MIPI0_SCCB_SCL |  | not present on T31ZX
62 | MIPI0_GPIO | 16 | SA1_DVP_MCLK_PA15
63 | GND |  | GND
64 | MIPI0_CLKP | 27 | MIPI_CLKP_DVP_D2
65 | MIPI0_CLKN | 26 | MIPI_CLKN_DVP_D3
66 | GND |  | GND
67 | MIPI0_D1P | 29 | MIPI_DATAP1_DVP_D0
68 | MIPI0_D1N | 28 | MIPI_DATAN1_DVP_D1
69 | GND |  | GND
70 | MIPI0_D0P | 25 | MIPI_DATAP0_DVP_D4
71 | MIPI0_D0N | 24 | MIPI_DATAN0_DVP_D5
72 | GND |  | GND
73 | MIPI1_SCCB_SDA |  | not present on T31ZX
74 | MIPI1_SCCB_SCL |  | not present on T31ZX
75 | MIPI1_GPIO |  | not present on T31ZX
76 | GND |  | GND
77 | MIPI1_CLKP |  | not present on T31ZX
78 | MIPI1_CLKN |  | not present on T31ZX
79 | GND |  | GND
80 | MIPI1_D1P |  | not present on T31ZX
81 | MIPI1_D1N |  | not present on T31ZX
82 | GND |  | GND
83 | MIPI1_D0P |  | not present on T31ZX
84 | MIPI1_D0N |  | not present on T31ZX
85 | GND |  | GND
86 | GND |  | GND
87 | GMAC0_MDIO | 57 | GMAC_MDIO_MSC1_D1_SLCD_D5_PB11
88 | GMAC0_MDCK | 58 | GMAC_MDCK_MSC1_D0_I2S_SDTO_SLCD_D4_PB10
89 | GMAC0_TXCLK | 62 | GMAC_TXCLK_SLCD_D0_PB06
90 | GMAC0_PHYCLK | 63 | GMAC_PHY_CLK_SLCD_D1_PB07
91 | GMAC0_TXEN | 66 | GMAC_TXEN_MSC1_CLK_I2S_ADC_MCLK_SLCD_D2_PB08
92 | GMAC0_TXD0 | 64 | GMAC_TXD0_MSC1_D2_I2S_ADC_LRCK_SLCD_D6_PB13
93 | GMAC0_TXD1 | 65 | GMAC_TXD1_MSC1_D3_I2S_DAC_MCLK_SLCD_D7_PB14
94 | GMAC0_RXDV | 59 | GMAC_RXDV_MSC1_CMD_I2S_SDTI_SLCD_D3_PB09
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

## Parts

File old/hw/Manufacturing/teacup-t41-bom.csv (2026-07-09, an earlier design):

Reference | Value | Footprint | QUANTITY | DNP
C1,C4,C7,C10,C13,C16 | 10uF | Capacitor_SMD:C_0805_2012Metric_Pad1.18x1.45mm_HandSolder | 6
C2,C5,C8,C11,C14,C17 | 1uF | Capacitor_SMD:C_0603_1608Metric_Pad1.08x0.95mm_HandSolder | 6
C3,C6,C9,C12,C15,C18,C19 | 100nF | Capacitor_SMD:C_0603_1608Metric_Pad1.08x0.95mm_HandSolder | 7
C20,C21 | 12pF | Capacitor_SMD:C_0402_1005Metric | 2
C22 | 4.7uF | Capacitor_SMD:C_0603_1608Metric_Pad1.08x0.95mm_HandSolder | 1
C23-C26,C28,C30-C32,C34-C39,C41-C46 | 100nF | Capacitor_SMD:C_0402_1005Metric | 20
C47,C50,C54 | 100nF | C_0402_1005Metric | 3
C48,C52 | 10uF | C_0805_2012Metric_Pad1.18x1.45mm_HandSolder | 2
C49,C53 | 22uF | C_0805_2012Metric_Pad1.18x1.45mm_HandSolder | 2
C51,C55 | 22pF | C_0402_1005Metric | 2
D1 | D_TVS_Dual_AAC | Package_TO_SOT_SMD:SOT-23-3 | 1
IC1 | T41NQ | teacup:QFN96_10x10_P0.35_EP7.6x7.2_T41 | 1
J1 | USB Type-C | Connector_USB:USB_C_Receptacle_HRO_TYPE-C-31-M-12 | 1
J2 | Micro_SD_Card | Connector_Card:microSD_HC_Hirose_DM3D-SF | 1
J3 | USB_A | Connector_USB:USB_A_TE_292303-7_Horizontal | 1
J4 | Conn_02x08_Odd_Even | Connector_PinHeader_2.54mm:PinHeader_2x08_P2.54mm_Vertical | 1
J6,J7 | Conn_02x07_Odd_Even | Connector_PinHeader_2.54mm:PinHeader_2x07_P2.54mm_Vertical | 2
J8 | DC_IN | Connector_BarrelJack:BarrelJack_Wuerth_6941xx301002 | 1
J9,J14 | Conn_01x02_MountingPin | Connector_PinHeader_2.54mm:PinHeader_1x02_P2.54mm_Vertical | 2
J10 | AudioJack4_Ground | Connector_Audio:Jack_3.5mm_PJ320D_Horizontal | 1
J11,J12 | Conn_01x04_Pin | Connector_PinHeader_2.54mm:PinHeader_1x04_P2.54mm_Vertical | 2
J13 | SFW15R-2STE1LF | SFW15R2STE1LF | 1
J15 | Conn_01x03_MountingPin | Connector_PinHeader_2.54mm:PinHeader_1x03_P2.54mm_Vertical_SMD_Pin1Left | 1
J16 | Conn_01x03_MountingPin | Connector_PinHeader_2.54mm:PinHeader_1x03_P2.54mm_Vertical | 1
L1,L2 | 2.2uH | Inductor_SMD:L_1210_3225Metric | 2
R1-R3,R6-R9,R25 | 0R | Resistor_SMD:R_0603_1608Metric_Pad0.98x0.95mm_HandSolder | 8
R4,R5 | 5k1 | Resistor_SMD:R_0603_1608Metric_Pad0.98x0.95mm_HandSolder | 2
R10-R14,R24 | 100k | Resistor_SMD:R_0603_1608Metric_Pad0.98x0.95mm_HandSolder | 6
R15-R20 | 47k | Resistor_SMD:R_0603_1608Metric_Pad0.98x0.95mm_HandSolder | 6
R21,R22 | 1M | Resistor_SMD:R_0402_1005Metric | 2
R26,R27 | 240R | R_0603_1608Metric_Pad0.98x0.95mm_HandSolder | 2
R28 | 1K | R_0603_1608Metric_Pad0.98x0.95mm_HandSolder | 1
R29 | 100k | R_0402_1005Metric | 1
R30 | 300k | R_0402_1005Metric | 1
R31 | 150k | R_0402_1005Metric | 1
R32 | 120k | R_0402_1005Metric | 1
S1 | CJS-1200TA | teacup:CJS-1200TA | 1
S2 | TL1015AF160QG | teacup:SW_TL1015AF160QG | 1
SW2 | SW_SPDT | Button_Switch_SMD:SW_SPDT_CK-JS102011SAQN | 1
U1 | AZ1117-3.3 | Package_TO_SOT_SMD:SOT-223-3_TabPin2 | 1
U2 | AZ1117-1.8 | Package_TO_SOT_SMD:SOT-223-3_TabPin2 | 1
U4 | W25Q32JVSS | Package_SO:SOIC-8_5.23x5.23mm_P1.27mm | 1
U6,U7 | SY8089A1AAC | Package_TO_SOT_SMD:SOT-23-5 | 2
Y1 | 24 MHz | Crystal:Crystal_SMD_2016-4Pin_2.0x1.6mm | 1

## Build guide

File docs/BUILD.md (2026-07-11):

# Teacup Neo — hardware build guide (headless KiCad, agent-facing)

This is the **how**. [`UNIVERSAL.md`](UNIVERSAL.md) is the **what** — the design
spec (connector, power, rails, pinout budget, peripherals). Read UNIVERSAL.md first;
this document tells an agent how to turn that spec into fabricated boards using the
headless toolchain, and it encodes the method + gotchas already proven on the T41
board (now archived in [`../old/`](../old/) — reuse those scripts as templates).

Two boards, built against **one shared pinout contract**:
- **interposer** — per-SoC module (SoC + fanout + clock + decoupling + straps
  + optional local power / NOR), gold-finger card edge.
- **carrier** — universal baseboard (DDR4 socket + power + peripherals + ESP32-S3
  BMC + full breakout).

> **Prime directive: verify every step by machine, never by eyeballing.** The T41
> board was trustworthy because each stage was checked programmatically — netlist
> export diff, per-pad net comparison, DRC. A schematic that "looks right" in a
> render is not verified. Every phase below ends in a **Verify** gate; do not
> advance past a failing gate.

---

## 1. Toolchain (exact, verified on this host)

| Tool | Version | Use |
|---|---|---|
| `kicad-cli` | **9.0.2** (`/usr/bin/kicad-cli`) | netlist/gerber/drill/pos/bom/svg/drc export |
| Python `pcbnew` | **9.0.2** | headless PCB surgery (footprint swap/add, per-pad `SetNet`, DSN/SES) |
| OpenJDK | **21.0.11** | runs FreeRouting |
| FreeRouting | **1.9.0** (download jar) | autorouter. **NOT 2.2.4** — it needs Java 25; we have 21 |
| `xvfb-run` | present (`/usr/bin/xvfb-run`) | FreeRouting throws `HeadlessException` without an X display |

Setup notes:
- **FreeRouting jar is not on disk** — fetch `freerouting-1.9.0.jar` from the v1.9.0
  GitHub release and keep the path in a variable. Confirm it starts:
  `xvfb-run java -jar freerouting-1.9.0.jar --help`.
- Stock KiCad libraries live at `/usr/share/kicad/footprints` and cover
  `Package_BGA`, `Package_QFP`, `Connector_PinHeader_*`, `MountingHole`, `Package_SO`
  (SOIC/SOT). **There is no DDR connector footprint** — the card edge is custom (§4).
- Schematic edits are done as **plain-text S-expression surgery** (regex on the
  `.kicad_sch`); PCB edits go through the **`pcbnew` Python API**. Both are
  scriptable and deterministic — that is the whole point.

Repo layout to create (mirrors `old/` but per-board):
```
hw/
  interposer/   interposer.kicad_pro|_sch|_pcb, teacup-neo.kicad_sym, *.pretty/
  carrier/      carrier.kicad_pro|_sch|_pcb,     teacup-neo.kicad_sym, *.pretty/
  common.pretty/   card-edge + shared footprints
scripts/        generators (copy + adapt from old/scripts/)
docs/pinout_288.csv   the contract (§3)
```

---

## 2. The proven method (reuse it verbatim, don't reinvent)

Everything below was validated on the T41 board. The scripts named are in
[`../old/scripts/`](../old/scripts/) — copy and adapt, don't start from scratch.

**2.1 Connectivity is by label name (flat sheet).** You do not draw wires. To
connect a pin to a net, place a **label** (signal), **power-symbol** (rail), or
**`no_connect`** (NC) at that pin's *absolute* position on the sheet. Same label
name = same net. This makes rewiring a pin a one-line placement, not a routing
problem. (`old/scripts/gen_schematic.py`, `gen_power_bucks.py`, `gen_new_circuits.py`.)

**2.2 The pin transform (calibrated).** A symbol pin at local `(sym.x, sym.y)` with
instance origin `O` lands at absolute `(O.x + sym.x, O.y − sym.y)` for rotation 0.
Parse the pin table from the symbol, compute each absolute position, place the
label there. Verify — never trust the transform blind.

**2.3 Verify the schematic by netlist diff, not by looking.**
```
kicad-cli sch export netlist -o /tmp/out.net hw/<board>/<board>.kicad_sch
```
Parse it, assert every intended `(ref,pin) -> net` is present and nothing was
orphaned. The T41 build treated "97 pins on intended nets, 0 mismatch" as the pass
condition. Do the same.

**2.4 PCB "update from schematic" is done in Python** (there is no
`kicad-cli pcb update-from-sch`). Pattern from `old/scripts/gen_pcb_update.py`:
```python
import pcbnew
b = pcbnew.LoadBoard(BRD)
# swap/add footprints (FootprintLoad from a .pretty), set position/rotation
# for each pad: pad.SetNet(b.FindNet(net_name_from_netlist))
# rip tracks when a pinout changed:  for t in list(b.GetTracks()): b.Delete(t)
pcbnew.SaveBoard(BRD, b)
```
**Verify: every pad's net == the netlist's net for that (ref,pad). 0 mismatch.**
Report the ratsnest (unrouted) count.

**2.5 Routing round-trip.** `old/scripts/gen_pcb_import_route.py` shows the return
leg; the full loop:
```python
pcbnew.ExportSpecctraDSN(b, "board.dsn")          # export
# xvfb-run java -jar freerouting-1.9.0.jar -de board.dsn -do board.ses -mp <passes>
pcbnew.ImportSpecctraSES(b, "board.ses")          # import result
pcbnew.ZONE_FILLER(b).Fill(b.Zones()); b.BuildConnectivity(); pcbnew.SaveBoard(BRD,b)
```
FreeRouting flags: `-de` design in (DSN), `-do` design out (SES), `-mp` max passes.
Always under `xvfb-run`.

**2.6 Manufacturing** is pure `kicad-cli` — copy `old/scripts/gen_manufacturing.sh`:
DRC → gerbers + drill → pos (centroid) → BOM → top/bottom SVG renders.

---

## 3. Phase 0 — the pinout contract (do this FIRST)

Both boards build against a single artifact: **`docs/pinout_288.csv`** — a map of
each of the 288 socket positions to a net. Neither board can be laid out until this
exists, because the interposer's gold fingers and the carrier's socket pads must
agree pin-for-pin.

Assign **geography-first** (UNIVERSAL.md §8), not by GPIO bank order:
- The **superset** is ~180 signals + ~15 power; the rest of the 288 positions are
  **ground fill** (target ≥ 1 GND per 3 signals; 288 gives ~93 grounds).
- **High-speed on one contact row** so each escapes on a single layer.
- **Diff pairs** (MIPI 100 Ω, A1 SATA ~90 Ω, HDMI TMDS, RGMII) on **adjacent fingers,
  same face, a GND finger each side.**
- **Power clustered** at one end (the 5 V pour is a blob, not a snake).
- **Mutually-exclusive peripherals share positions** (UNIVERSAL.md §8 escape valve):
  A1 display-out (HDMI/VGA/RGB) reuses the T-series **camera-zone**; DVP reuses the
  MIPI/GPIO positions (no interposer is ever both). This is what keeps A1+SATA inside
  288.
- **A1-unique** positions: dual SATA (4 pairs), 2nd RGMII, extra USB (§10).

**Verify:** every signal named in §3/§8/§9/§10 has exactly one position; every diff
pair has flanking grounds; ground ratio ≥ 1/3; SoC-specific pin maps (per-SoC
column) all fit the assigned positions. Output is a reviewed CSV, committed.

---

## 4. Phase 1 — the card-edge footprint (the one genuinely new part)

Two mating halves of the **same 288 geometry** (UNIVERSAL.md §1 mechanical). Build
like `old/scripts/gen_footprint.py` built the QFN96 — parametric Python emitting a
`.kicad_mod`.

**4a. Interposer edge** = a footprint whose "pads" are the gold fingers:
- 288 edge pads, **144 per face**, **0.85 mm pitch** (~122 mm finger span → ~133 mm
  card), on `F.Cu` (top face) and `B.Cu` (bottom face).
- `Edge.Cuts` outline carrying the **DDR4 UDIMM key notch** at its JEDEC position
  (distinct from SO-DIMM) and the two **side latch cut-outs**.
- Board **thickness 1.0 mm ±0.1** — a hard seating requirement (set in board setup,
  not the footprint, but the fingers assume it).
- ENIG/hard-gold on the fingers, chamfered lead-in (fab/gerber concern, note it).

**4b. Carrier socket** = the mating connector footprint:
- Primary **Foxconn AH58893-T9B10-3F** (LCSC **C42403003**, SMD vertical, 288P, 738
  stock). Import the LCSC/EasyEDA footprint if available, else draw from the datasheet.
- Alt: Amphenol FCI **DDR4288V0213TF**.

**Verify:** finger/pad count == 288; pitch 0.85; notch + latch positions match the
JEDEC DDR4 UDIMM drawing; **finger N on the interposer maps to socket pad N maps to
`pinout_288.csv` row N** (a 1:1 cross-check script). A card edge that seats but is
mirror-flipped or off-by-one is the worst failure mode — check it explicitly.

---

## 5. Phase 2 — the interposer (build ONE reference first: T41 or T31)

Prove the interposer pipeline on a SoC we already have data for (T41 footprint +
symbol + pins exist in `old/`), then parametrize.

1. **Footprints** — SoC package (`old/hw/teacup.pretty/QFN96…` exists for T41; BGA
   parts use `Package_BGA` or a generated `.kicad_mod`), the **card edge** (§4a),
   plus NOR SOIC, crystal, buck, passives from stock libs.
2. **Symbol** — `old/scripts/gen_symbol.py` builds a KiCad 9 symbol from a per-SoC
   pin CSV (grouped by function onto 4 sides). One CSV per SoC.
3. **Schematic** (label method, §2.1) — place, for every SoC pin: a label routing it
   to its **card-edge finger** per `pinout_288.csv`; the **clock** (24 MHz xtal + 1 M
   + 33 R, tight); **decoupling** (mandatory local, §2 SI rules); **straps**
   (BOOT_SEL, POR); optional **local bucks** (mode A) or FB-set resistors (mode B);
   optional **8-pad NOR** on SFC0.
4. **Verify schematic** by netlist diff (§2.3).
5. **PCB** — 1.0 mm board, 4-layer; place the SoC island + the card-edge footprint;
   apply the netlist in Python (§2.4); **verify 0 pad-net mismatch.**
6. **Route** — short and local. Keep the clock off any connector. MIPI/DDR (external-
   DDR parts) get controlled-impedance care (§7). FreeRouting the rest (§2.5).
7. **DRC + outputs** (§2.6).

**Parametrize:** other SoCs = new pin CSV → `gen_symbol.py` → new package footprint →
re-run the schematic generator against `pinout_288.csv`. The card edge, clock, decap,
and straps are the same template; only the SoC fanout changes. Note per-SoC deltas
(DDR voltage, SIP vs external DDR, DVP vs MIPI, A1's SATA/analog rails).

---

## 6. Phase 3 — the carrier (universal baseboard)

Bigger, but the same method. Build in **functional blocks**, each label-connected and
netlist-verified independently before integration.

1. **Footprints** — the **socket** (§4b); ESP32-S3-WROOM-1-N16R2 module; the
   adjustable bucks (VCORE ≥3 A / VDDR ≥1.5 A) + LDOs; MCP4661 digipot; USB-C ×2,
   RJ45 ×2, SATA ×2, HDMI, VGA, microSD, audio jack + codec passives, camera FFC,
   DIP8/SOP8 flash, JTAG 2×5, IR-cut/IR-LED drivers, test-point pads; GPIO headers.
2. **Symbols** for each IC.
3. **Schematic — one block at a time**, each label-connected + netlist-verified:
   - **Power** (UNIVERSAL.md §2/§4): switched SoC-5V domain (one load switch feeds
     VCORE/VDDR bucks + carrier 3.3/1.8 + connector 5V) vs **always-on** BMC 3.3;
     digipot on the FB dividers; VCORE_SNS to the BMC ADC.
   - **BMC** (§9): ESP32-S3, USB, BOOTSEL/reset/flash-select GPIO, UART fan-in, I²C.
   - **Peripherals** (§8): USB, dual GbE, dual SATA, HDMI/VGA, SD, audio (mic→codec,
     HPOUT→jack, I²S/DMIC headers), camera FFC + DVP header, PWM/IR-cut/IR-LED, JTAG.
   - **Breakout** (§8): every remaining socket position → labeled 0.1" header.
4. **Verify** the full schematic by netlist diff.
5. **PCB** — 4–6 layer (§7); **floorplan by geography** (§8): place the socket, then
   each block so its nets exit the socket already pointed at it (USB by the USB
   jacks, MIPI by the FFC, SATA by the SATA connectors, power clustered). Apply
   netlist in Python; **verify 0 pad-net mismatch.**
6. **Route** — FreeRouting the bulk single-ended nets; **hand-route the diff pairs**
   (§7). DRC + outputs.

---

## 7. Controlled impedance & the manual-routing gap (READ before any routing)

**FreeRouting does not do controlled impedance.** It gets you ~80–85% (single-ended,
low-speed) fast, but the high-speed pairs need a defined stackup and hand routing.
This was the T41 board's explicit "not fab-ready" gap — do not let an autorouter
"finish" and call it done.

1. **Define the stackup first** so impedance is calculable: interposer 4-layer at
   1.0 mm (fixed by the card-edge spec); carrier 4-layer, or **6-layer** if the A1
   SATA/HDMI + dual-MIPI density gets tight. Set dielectric heights in board setup.
2. **Targets:** MIPI D-PHY ~100 Ω diff; SATA ~90 Ω (100 Ω also common per PHY); HDMI
   TMDS ~100 Ω diff; RGMII single-ended ~50 Ω, length-matched to its clock.
3. **Route diff pairs by hand** (pcbnew or the GUI), length-matched, GND-flanked,
   minimum vias. Lock them, then let FreeRouting fill in around them.
4. A **human review in the KiCad GUI** before fab is mandatory (placement de-overlap,
   impedance, return paths) — the same caveat as the T41 board.

---

## 8. Verification gates (must pass before advancing)

| Phase | Gate |
|---|---|
| Pinout (§3) | every §8 signal has 1 position; diff pairs GND-flanked; GND ratio ≥ 1/3 |
| Card edge (§4) | 288 pads; 0.85 mm pitch; notch/latch per JEDEC; finger↔socket↔CSV 1:1, not mirrored/off-by-one |
| Footprint | pad count + pitch == datasheet; courtyard sane |
| Symbol | pin count == datasheet; no duplicate pin numbers |
| Schematic | `kicad-cli sch export netlist` clean; every intended net present; ERC power/NC resolved |
| PCB apply | every pad net == netlist (**0 mismatch**); ratsnest reported |
| Routing | 0 unrouted; **0 DRC errors**; diff pairs impedance + length checked |
| Manufacturing | gerbers/drill/pos/BOM emitted; JLCPCB DFM rule pass |

---

## 9. Gotchas (hard-won on the T41 build — you will hit these)

- **Schematic S-expr symbol prefixing.** When embedding a symbol into a sheet's
  `lib_symbols`, the **parent** gets the library prefix (`teacup-neo:T41NQ`) but the
  **child sub-symbols keep the unprefixed name** (`T41NQ_0_1`, `T41NQ_1_1`). Prefix
  the children and KiCad reports **"Failed to load schematic."**
- **Removing old stubs orphans wire-only nets.** Deleting a pin's old connection can
  strand nets that were only held by a wire (crystal, boot-sel, VREF, VCM…). Keep the
  stub or add a reconnection label at the old pin position, then re-verify the netlist.
- **FreeRouting version/headless.** Use **1.9.0 with Java 21** (2.2.4 needs Java 25).
  A bare run throws `HeadlessException` → always `xvfb-run`.
- **No DDR connector in stock KiCad** → the card edge is a custom footprint (§4).
- **1.0 mm board thickness is a hard requirement** for the edge to seat — set it in
  board setup; too thick spreads the contacts, too thin is intermittent.
- **Part stock data goes stale.** Verify parts on live vendor pages, not cached
  search. (The socket **C42403003** and ESP32 **C2913205** were live-verified; re-check
  at BOM time.)
- **New generated file / net → verify, don't assume.** Confirm by netlist export or
  pad-net readback, the same way you'd `nm` a new object file.
- **Retail SoC secure-boot / eFuse state is unknown** — a locked part can't be
  reflashed. Note it in the BOM (the lab once hit a locked T32NQ).

---

## 10. Definition of done (per board)

1. Schematic netlist-verified (every intended net; 0 mismatch).
2. PCB netlist applied with 0 pad-net mismatch.
3. 0 unrouted ratsnest; 0 DRC errors; diff pairs impedance + length verified.
4. Stackup defined; card-edge geometry matches the JEDEC UDIMM drawing.
5. Manufacturing set emitted (gerbers, drill, centroid, BOM, renders) and passed a
   JLCPCB DFM check.
6. **Human GUI review** signed off (placement, impedance, return paths).
7. BOM parts live-verified for stock + secure-boot state.

---

## Appendix — reusable scripts (`old/scripts/`, T41 templates)

| Script | What it does | Adapt for |
|---|---|---|
| `gen_footprint.py` | parametric `.kicad_mod` (built the QFN96) | the card edge (§4) + BGA/QFN packages |
| `gen_symbol.py` | KiCad 9 symbol from a per-SoC pin CSV | every SoC symbol |
| `gen_schematic.py` | swap SoC + rewire by net-name labels; pin transform; netlist-verify | interposer schematic per SoC |
| `gen_power_bucks.py` | add regulators, label-connected | carrier power block |
| `gen_new_circuits.py` | add passives/straps by label | decoupling, straps, NOR |
| `gen_pcb_update.py` | headless "update from schematic": footprint swap/add, per-pad `SetNet`, rip tracks; verifies pad nets | both PCBs |
| `gen_pcb_import_route.py` | DSN/SES round-trip + zone fill | both PCBs |
| `gen_manufacturing.sh` | DRC + gerbers/drill/pos/BOM/SVG via `kicad-cli` | both boards |

Start each new board by copying the relevant script, repointing its paths, and
running its **Verify** step before trusting the output.

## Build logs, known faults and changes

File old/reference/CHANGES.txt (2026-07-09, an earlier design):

Align schematic to default 0.635mm grid.
Add logo and mounting holes into schematic.
Enable "Exclude from simulation" attribute on all components.
Rearrange USB section.
Move symbols and footprints into project libraries.
Create +2V8 symbol and use it. Changing the value on a power symbol doesn't change everything, the voltage is on the pin in the symbol.
Minor silkscreen fixes.
Update schematic to match board layout attributes, enabling to update pcb from schematic without issues.
Add "power supply" designators in the schematic to help ERC.
ERC and DRC free of issues.

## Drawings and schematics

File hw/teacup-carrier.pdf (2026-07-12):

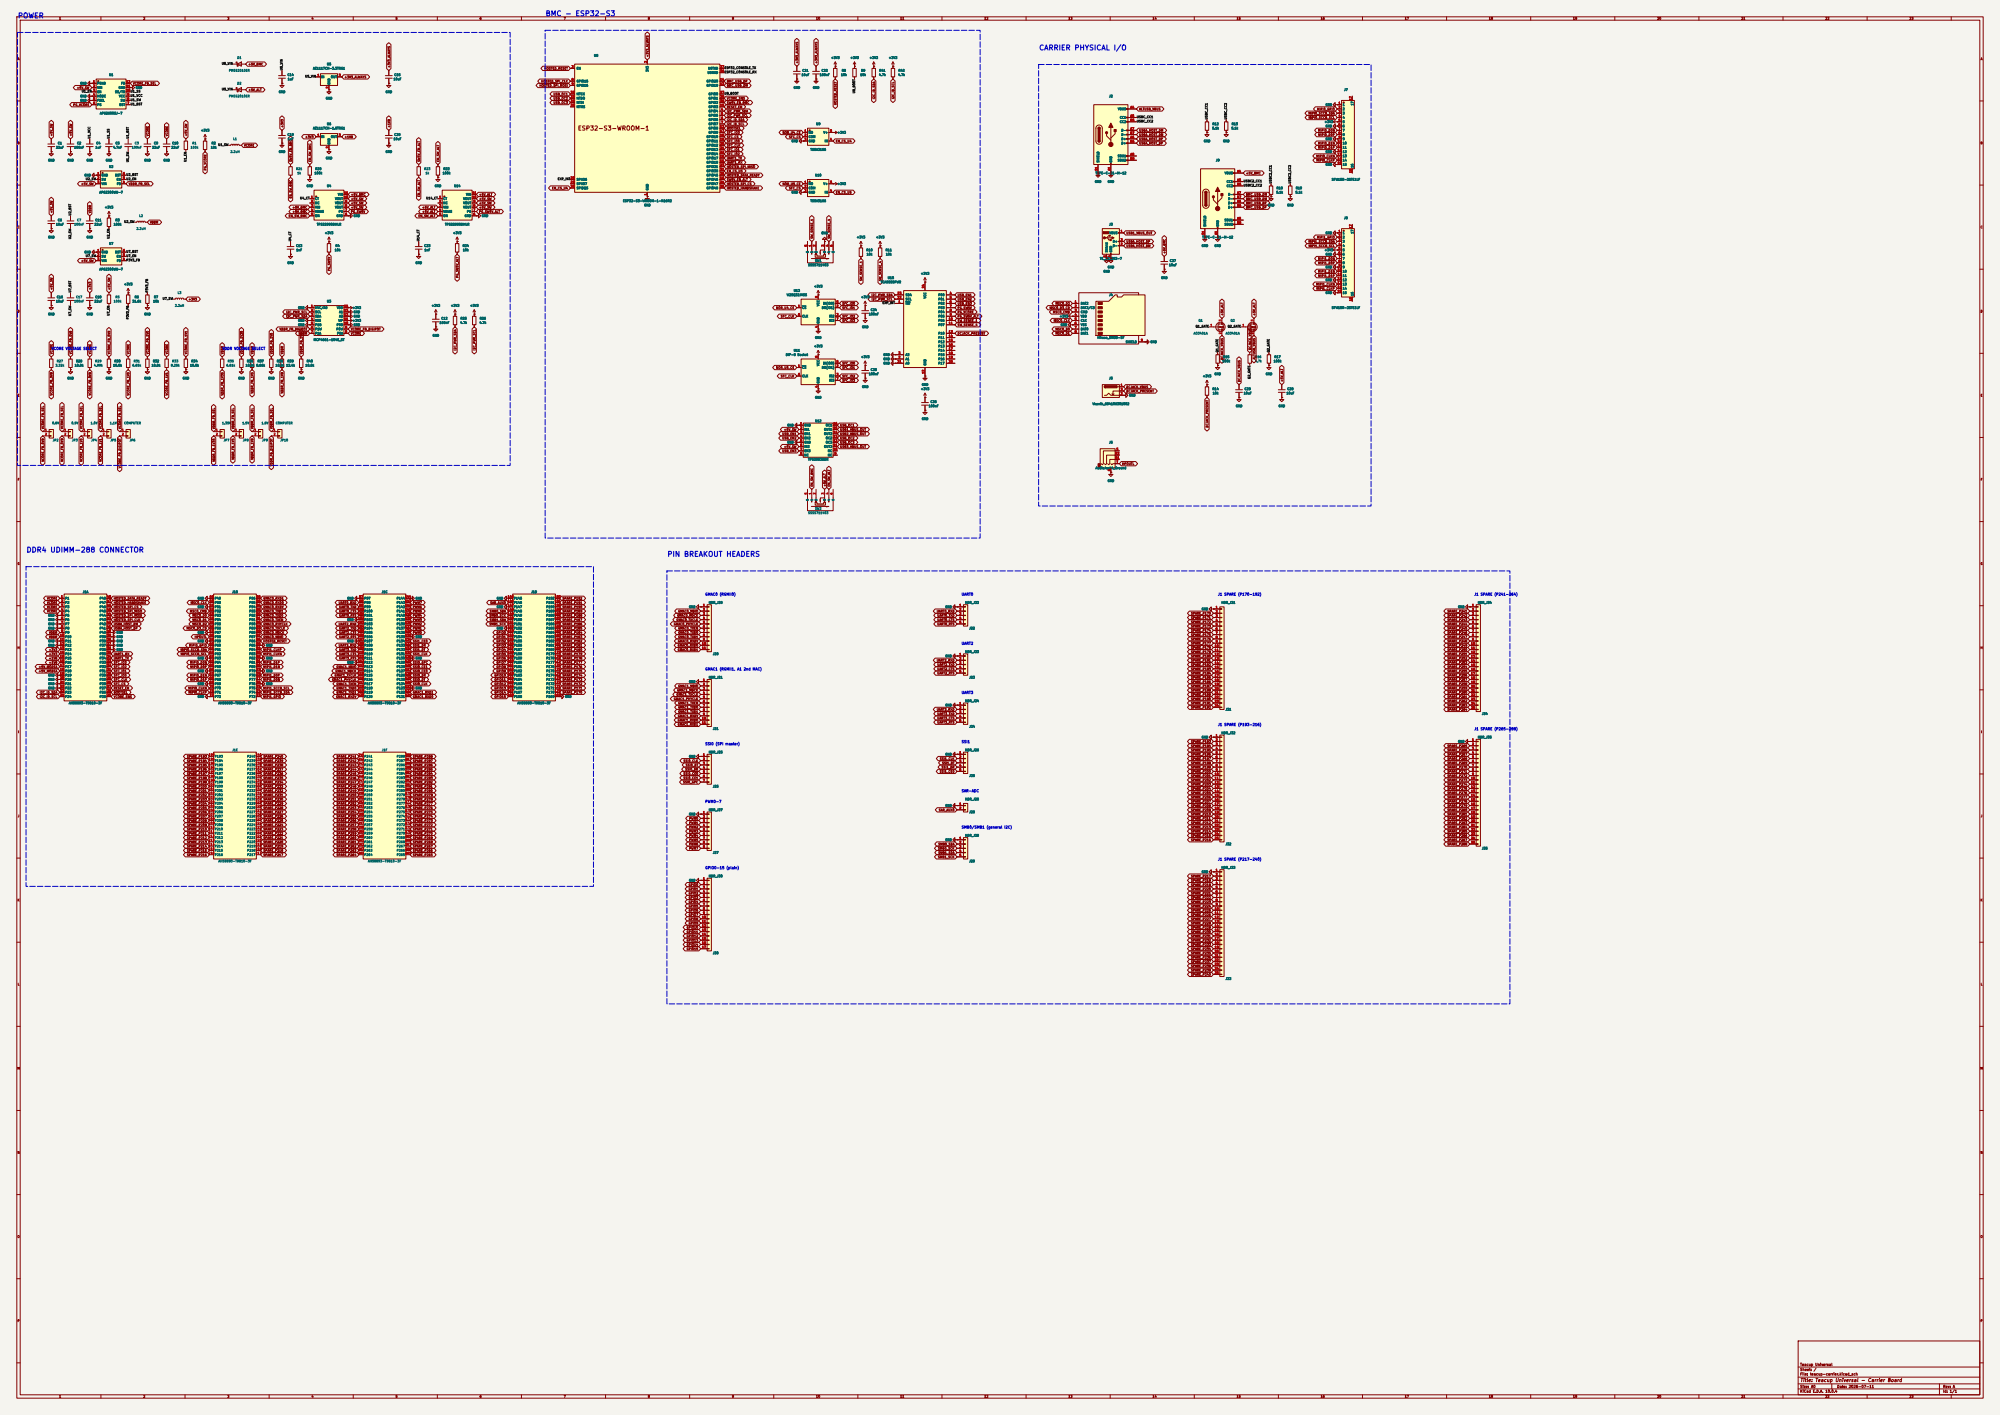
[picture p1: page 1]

SS/TR 10 GND 11 FB 12 U1

SS/TR 10 GND 11 FB 12 GND
GND

GND GND A1 | VBUS VBUS SBU1 SBU1 | A4 CC1 A4 CC1 A5 D+ A5 D+ B5 D+ B5 D+ A8 CC2 A8 CC2 A6 D-A6 D-B6 D-B6 D-J8 J8

VBUS | 1 D-1 D-3 GND 3 GND 2 D+ 2 D+ AO3401A R15 | 1 2 2 3 3 4 4 5 5 6 6 7 7 8 8 9 9 10 10 11 11 12 12 13 13 14 14 15 15

8 +3V3 GND U12
GND U11 DIP-8 Socket CS

Teacup Universal
Sheet: /
File: teacup-carrier.kicad_sch
Title: Teacup Universal - Carrier Board

Size: A0 | Rev: A
KiCad E.D.A. 10.0.4 | Id: 1/1

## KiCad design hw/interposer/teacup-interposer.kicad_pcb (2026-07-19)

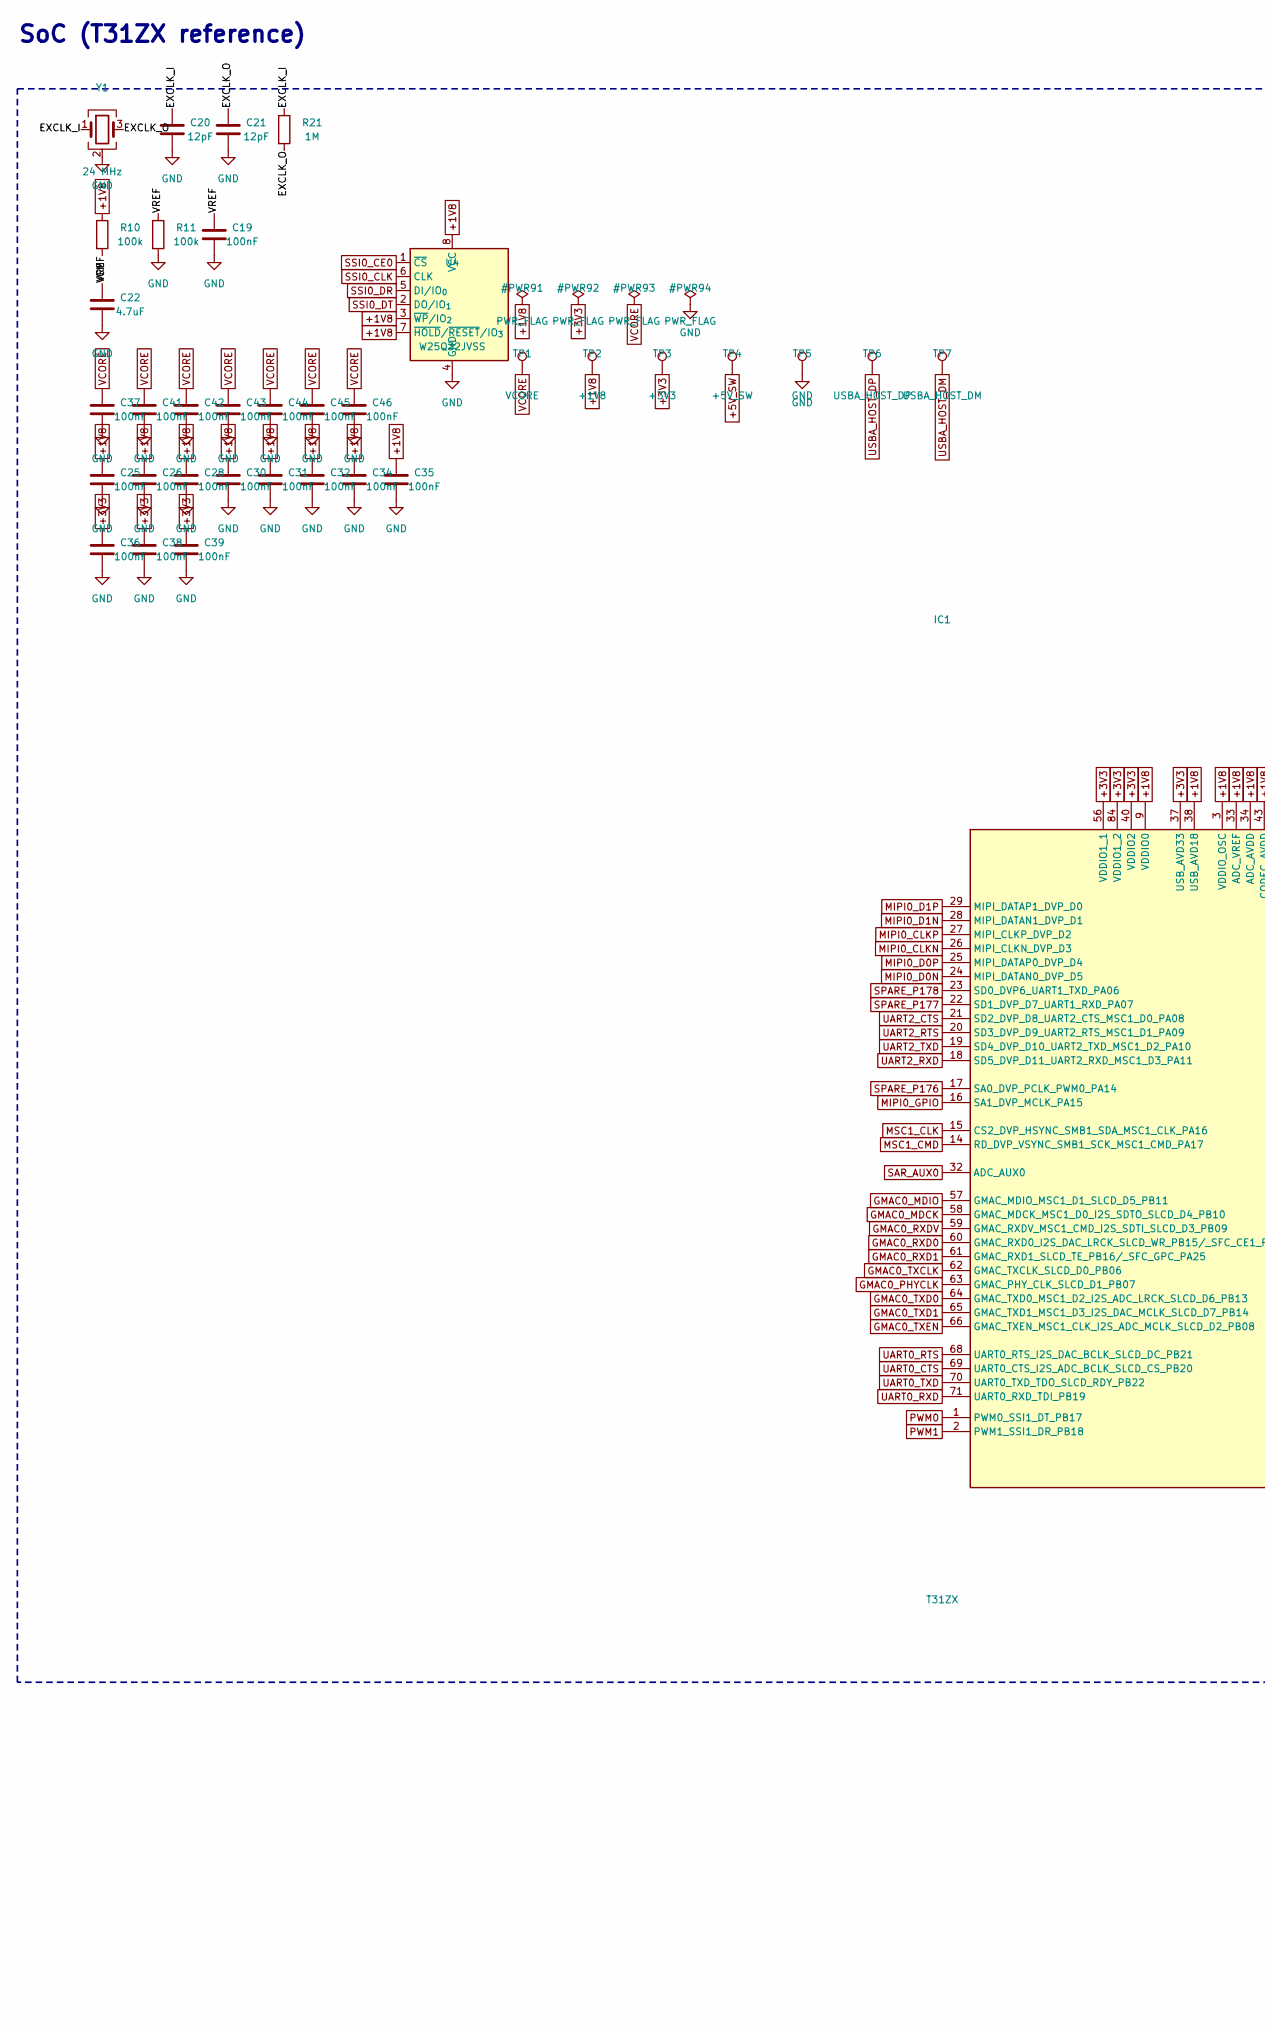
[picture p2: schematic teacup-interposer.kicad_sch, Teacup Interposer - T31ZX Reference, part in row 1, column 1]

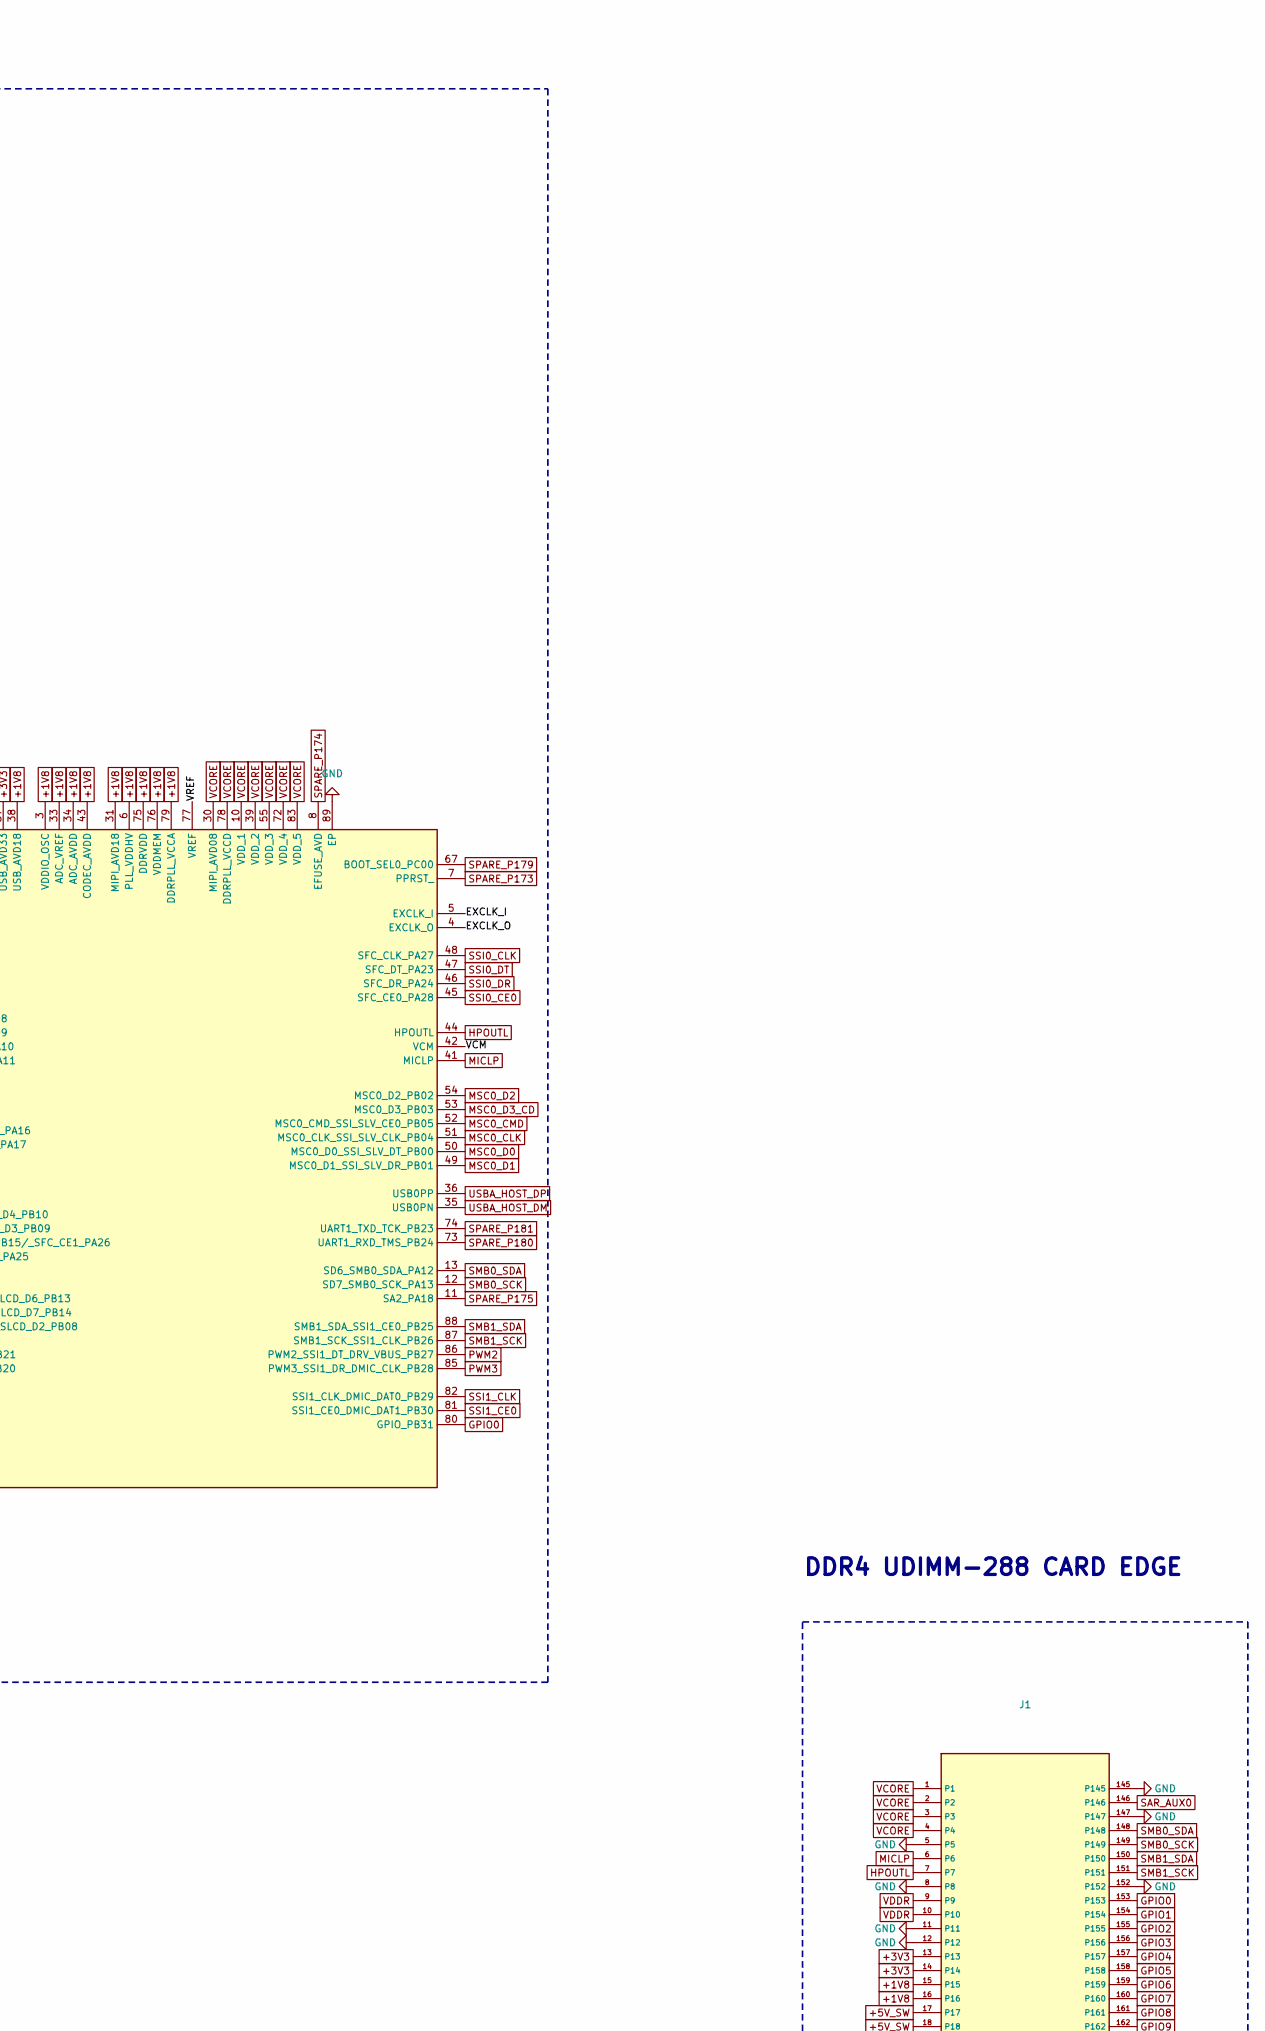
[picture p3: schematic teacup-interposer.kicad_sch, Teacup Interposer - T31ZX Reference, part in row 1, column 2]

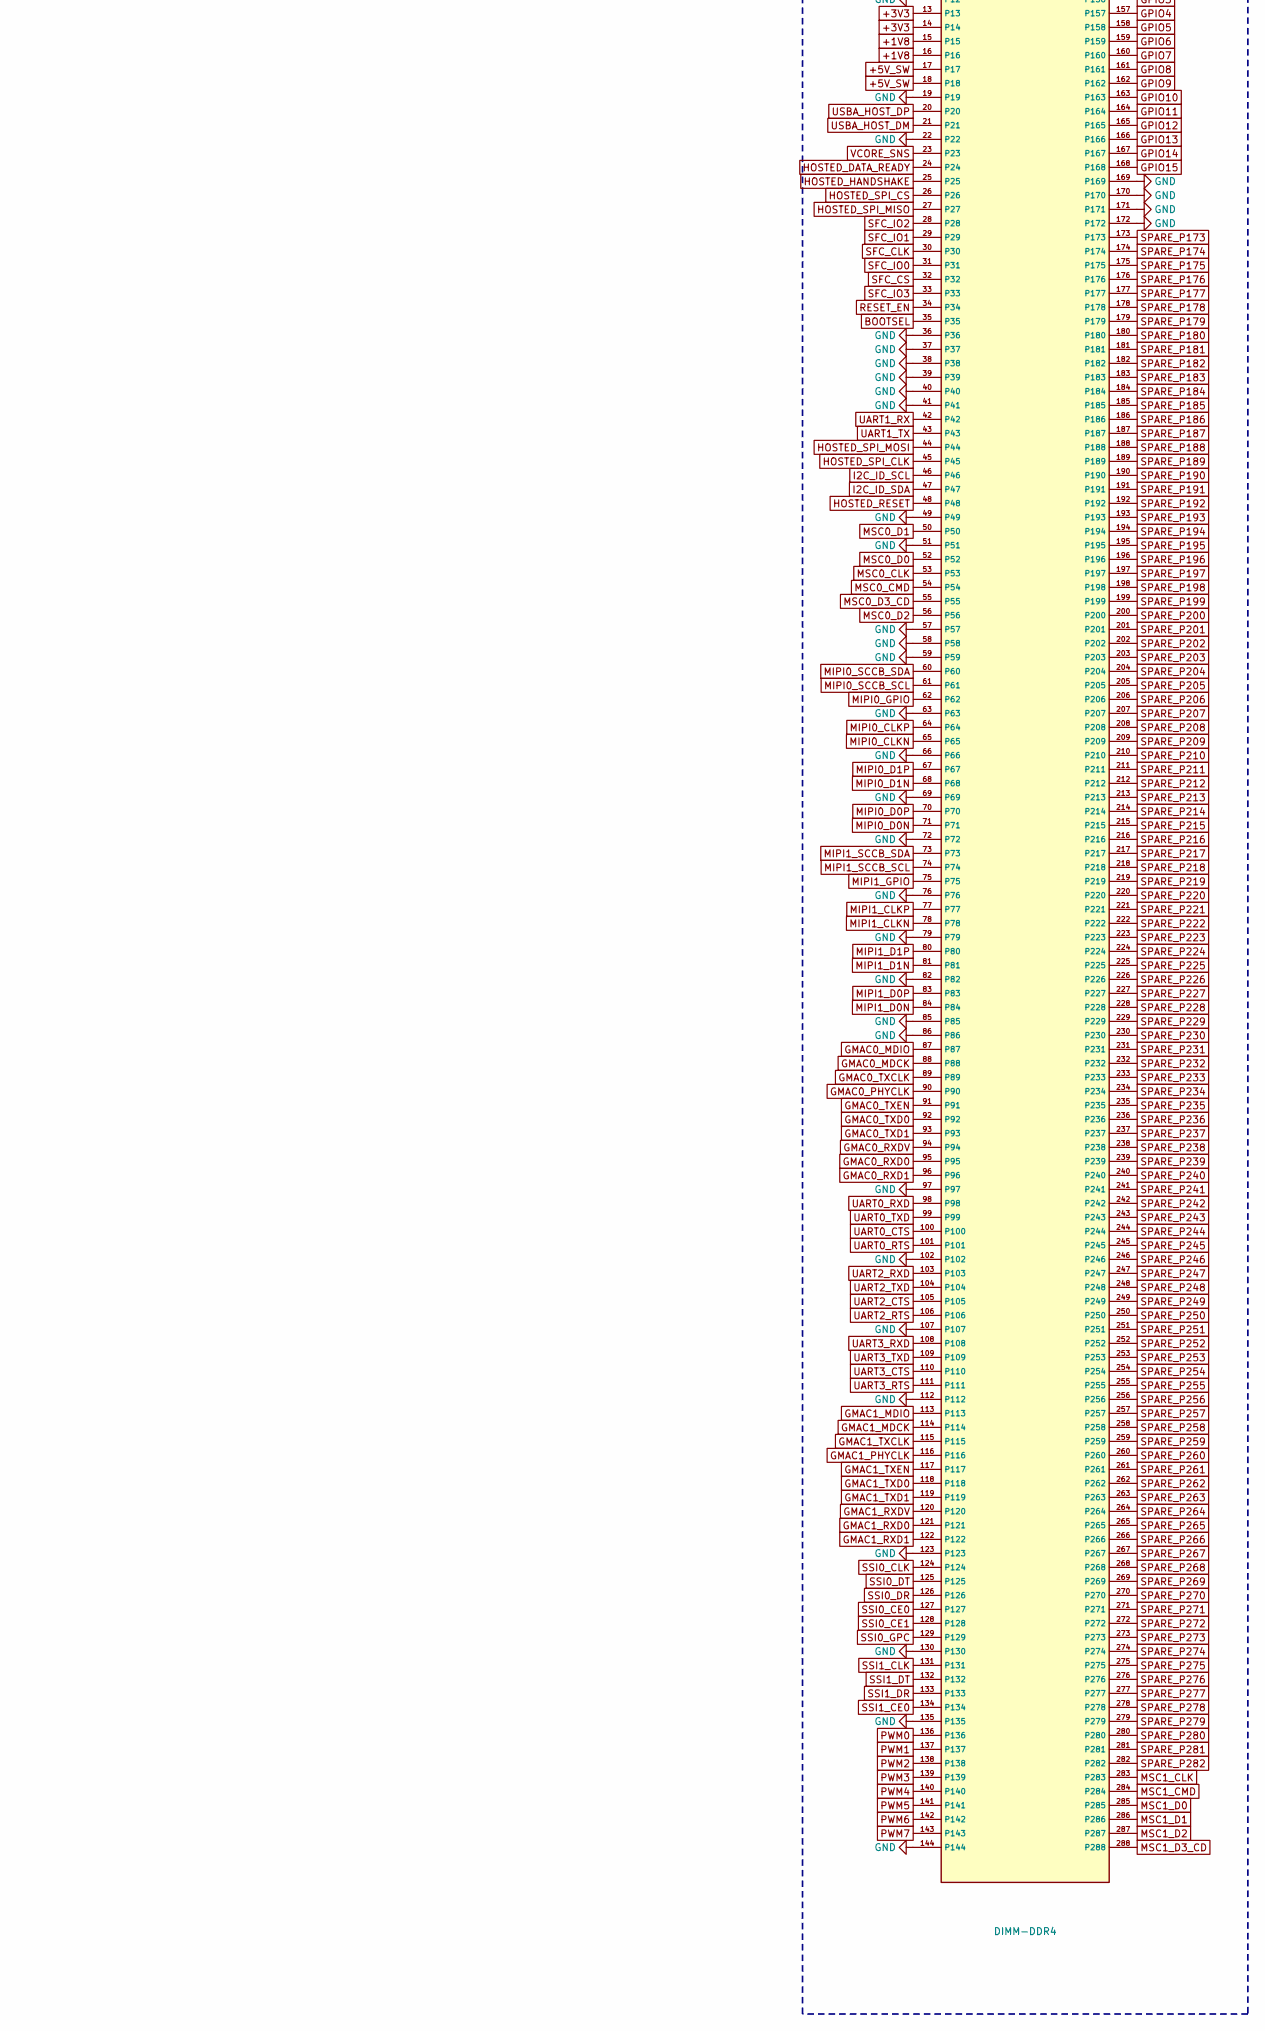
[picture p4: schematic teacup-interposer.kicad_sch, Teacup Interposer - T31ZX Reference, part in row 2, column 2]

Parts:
C19: 100nF; C_0603_1608Metric
C20, C21: 12pF; C_0402_1005Metric
C22: 4.7uF; C_0603_1608Metric_Pad1.08x0.95mm_HandSolder
C25, C26, C28, C30, C31, C32, C34, C35, C36, C37, C38, C39, C41, C42, C43, C44, C45, C46: 100nF; C_0402_1005Metric
IC1: T31ZX; QFN35P900X900X90-89N-D
J1: DIMM-DDR4
R10, R11: 100k; R_0603_1608Metric
R21: 1M; R_0402_1005Metric
TP1: VCORE; TestPoint_Pad_2.0x2.0mm
TP2: +1V8; TestPoint_Pad_2.0x2.0mm
TP3: +3V3; TestPoint_Pad_2.0x2.0mm
TP4: +5V_SW; TestPoint_Pad_2.0x2.0mm
TP5: GND; TestPoint_Pad_2.0x2.0mm
TP6: USBA_HOST_DP; TestPoint_Pad_2.0x2.0mm
TP7: USBA_HOST_DM; TestPoint_Pad_2.0x2.0mm
U4: W25Q32JVSS; SOIC-8_5.3x5.3mm_P1.27mm
Y1: 24 MHz; Crystal_SMD_2016-4Pin_2.0x1.6mm

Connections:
+5V_SW: J1.17, J1.18, TP4.1
/EXCLK_O: C21.1, IC1.4 (EXCLK_O), R21.2, Y1.3
/VCM: C22.1, IC1.42 (VCM)
/VREF: C19.1, IC1.77 (VREF), R10.2, R11.1
BOOTSEL: J1.35
GMAC0_MDCK: IC1.58 (GMAC_MDCK_MSC1_D0_I2S_SDTO_SLCD_D4_PB10), J1.88
GMAC0_MDIO: IC1.57 (GMAC_MDIO_MSC1_D1_SLCD_D5_PB11), J1.87
GMAC0_PHYCLK: IC1.63 (GMAC_PHY_CLK_SLCD_D1_PB07), J1.90
GMAC0_RXD0: IC1.60 (GMAC_RXD0_I2S_DAC_LRCK_SLCD_WR_PB15/_SF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), J1.95
GMAC0_RXD1: IC1.61 (GMAC_RXD1_SLCD_TE_PB16/_SFC_GPC_PA25), J1.96
GMAC0_RXDV: IC1.59 (GMAC_RXDV_MSC1_CMD_I2S_SDTI_SLCD_D3_PB09), J1.94
GMAC0_TXCLK: IC1.62 (GMAC_TXCLK_SLCD_D0_PB06), J1.89
GMAC0_TXD0: IC1.64 (GMAC_TXD0_MSC1_D2_I2S_ADC_LRCK_SLCD_D6_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), J1.92
GMAC0_TXD1: IC1.65 (GMAC_TXD1_MSC1_D3_I2S_DAC_MCLK_SLCD_D7_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), J1.93
GMAC0_TXEN: IC1.66 (GMAC_TXEN_MSC1_CLK_I2S_ADC_MCLK_SLCD_D2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), J1.91
GMAC1_MDCK: J1.114
GMAC1_MDIO: J1.113
GMAC1_PHYCLK: J1.116
GMAC1_RXD0: J1.121
GMAC1_RXD1: J1.122
GMAC1_RXDV: J1.120
GMAC1_TXCLK: J1.115
GMAC1_TXD0: J1.118
GMAC1_TXD1: J1.119
GMAC1_TXEN: J1.117
GPIO0: IC1.80 (GPIO_PB31), J1.153
GPIO1: J1.154
GPIO2: J1.155
GPIO3: J1.156
GPIO4: J1.157
GPIO5: J1.158
GPIO6: J1.159
GPIO7: J1.160
GPIO8: J1.161
GPIO9: J1.162
GPIO10: J1.163
GPIO11: J1.164
GPIO12: J1.165
GPIO13: J1.166
GPIO14: J1.167
GPIO15: J1.168
HOSTED_DATA_READY: J1.24
HOSTED_HANDSHAKE: J1.25
HOSTED_RESET: J1.48
HOSTED_SPI_CLK: J1.45
HOSTED_SPI_CS: J1.26
HOSTED_SPI_MISO: J1.27
HOSTED_SPI_MOSI: J1.44
HPOUTL: IC1.44 (HPOUTL), J1.7
I2C_ID_SCL: J1.46
I2C_ID_SDA: J1.47
MICLP: IC1.41 (MICLP), J1.6
MIPI0_CLKN: IC1.26 (MIPI_CLKN_DVP_D3), J1.65
MIPI0_CLKP: IC1.27 (MIPI_CLKP_DVP_D2), J1.64
MIPI0_D0N: IC1.24 (MIPI_DATAN0_DVP_D5), J1.71
MIPI0_D0P: IC1.25 (MIPI_DATAP0_DVP_D4), J1.70
MIPI0_D1N: IC1.28 (MIPI_DATAN1_DVP_D1), J1.68
MIPI0_D1P: IC1.29 (MIPI_DATAP1_DVP_D0), J1.67
MIPI0_GPIO: IC1.16 (SA1_DVP_MCLK_PA15), J1.62
MIPI0_SCCB_SCL: J1.61
MIPI0_SCCB_SDA: J1.60
MIPI1_CLKN: J1.78
MIPI1_CLKP: J1.77
MIPI1_D0N: J1.84
MIPI1_D0P: J1.83
MIPI1_D1N: J1.81
MIPI1_D1P: J1.80
MIPI1_GPIO: J1.75
MIPI1_SCCB_SCL: J1.74
MIPI1_SCCB_SDA: J1.73
MSC0_CLK: IC1.51 (MSC0_CLK_SSI_SLV_CLK_PB04), J1.53
MSC0_CMD: IC1.52 (MSC0_CMD_SSI_SLV_CE0_PB05), J1.54
MSC0_D0: IC1.50 (MSC0_D0_SSI_SLV_DT_PB00), J1.52
MSC0_D1: IC1.49 (MSC0_D1_SSI_SLV_DR_PB01), J1.50
MSC0_D2: IC1.54 (MSC0_D2_PB02), J1.56
MSC0_D3_CD: IC1.53 (MSC0_D3_PB03), J1.55
MSC1_CLK: IC1.15 (CS2_DVP_HSYNC_SMB1_SDA_MSC1_CLK_PA16), J1.283
MSC1_CMD: IC1.14 (RD_DVP_VSYNC_SMB1_SCK_MSC1_CMD_PA17), J1.284
MSC1_D0: J1.285
MSC1_D1: J1.286
MSC1_D2: J1.287
MSC1_D3_CD: J1.288
PWM0: IC1.1 (PWM0_SSI1_DT_PB17), J1.136
PWM1: IC1.2 (PWM1_SSI1_DR_PB18), J1.137
PWM2: IC1.86 (PWM2_SSI1_DT_DRV_VBUS_PB27), J1.138
PWM3: IC1.85 (PWM3_SSI1_DR_DMIC_CLK_PB28), J1.139
PWM4: J1.140
PWM5: J1.141
PWM6: J1.142
PWM7: J1.143
RESET_EN: J1.34
SAR_AUX0: IC1.32 (ADC_AUX0), J1.146
SFC_CLK: J1.30
SFC_CS: J1.32
SFC_IO0: J1.31
SFC_IO1: J1.29
SFC_IO2: J1.28
SFC_IO3: J1.33
SMB0_SCK: IC1.12 (SD7_SMB0_SCK_PA13), J1.149
SMB0_SDA: IC1.13 (SD6_SMB0_SDA_PA12), J1.148
SMB1_SCK: IC1.87 (SMB1_SCK_SSI1_CLK_PB26), J1.151
SMB1_SDA: IC1.88 (SMB1_SDA_SSI1_CE0_PB25), J1.150
SPARE_P173: IC1.7 (PPRST_), J1.173
SPARE_P174: IC1.8 (EFUSE_AVD), J1.174
SPARE_P175: IC1.11 (SA2_PA18), J1.175
SPARE_P176: IC1.17 (SA0_DVP_PCLK_PWM0_PA14), J1.176
SPARE_P177: IC1.22 (SD1_DVP_D7_UART1_RXD_PA07), J1.177
SPARE_P178: IC1.23 (SD0_DVP6_UART1_TXD_PA06), J1.178
SPARE_P179: IC1.67 (BOOT_SEL0_PC00), J1.179
SPARE_P180: IC1.73 (UART1_RXD_TMS_PB24), J1.180
SPARE_P181: IC1.74 (UART1_TXD_TCK_PB23), J1.181
SPARE_P182: J1.182
SPARE_P183: J1.183
SPARE_P184: J1.184
SPARE_P185: J1.185
SPARE_P186: J1.186
SPARE_P187: J1.187
SPARE_P188: J1.188
SPARE_P189: J1.189
SPARE_P190: J1.190
SPARE_P191: J1.191
SPARE_P192: J1.192
SPARE_P193: J1.193
SPARE_P194: J1.194
SPARE_P195: J1.195
SPARE_P196: J1.196
SPARE_P197: J1.197
SPARE_P198: J1.198
SPARE_P199: J1.199
SPARE_P200: J1.200
SPARE_P201: J1.201
SPARE_P202: J1.202
SPARE_P203: J1.203
SPARE_P204: J1.204
SPARE_P205: J1.205
SPARE_P206: J1.206
SPARE_P207: J1.207
SPARE_P208: J1.208
SPARE_P209: J1.209
SPARE_P210: J1.210
SPARE_P211: J1.211
SPARE_P212: J1.212
SPARE_P213: J1.213
SPARE_P214: J1.214
SPARE_P215: J1.215
SPARE_P216: J1.216
SPARE_P217: J1.217
SPARE_P218: J1.218
SPARE_P219: J1.219
SPARE_P220: J1.220
SPARE_P221: J1.221
SPARE_P222: J1.222
SPARE_P223: J1.223
SPARE_P224: J1.224
SPARE_P225: J1.225
SPARE_P226: J1.226
SPARE_P227: J1.227
SPARE_P228: J1.228
SPARE_P229: J1.229
SPARE_P230: J1.230
SPARE_P231: J1.231
SPARE_P232: J1.232
SPARE_P233: J1.233
SPARE_P234: J1.234
SPARE_P235: J1.235
SPARE_P236: J1.236
SPARE_P237: J1.237
SPARE_P238: J1.238
SPARE_P239: J1.239
SPARE_P240: J1.240
SPARE_P241: J1.241
SPARE_P242: J1.242
SPARE_P243: J1.243
SPARE_P244: J1.244
SPARE_P245: J1.245
SPARE_P246: J1.246
SPARE_P247: J1.247
SPARE_P248: J1.248
SPARE_P249: J1.249
SPARE_P250: J1.250
SPARE_P251: J1.251
SPARE_P252: J1.252
SPARE_P253: J1.253
SPARE_P254: J1.254
SPARE_P255: J1.255
SPARE_P256: J1.256
SPARE_P257: J1.257
SPARE_P258: J1.258
SPARE_P259: J1.259
SPARE_P260: J1.260
SPARE_P261: J1.261
SPARE_P262: J1.262
SPARE_P263: J1.263
SPARE_P264: J1.264
SPARE_P265: J1.265
SPARE_P266: J1.266
SPARE_P267: J1.267
SPARE_P268: J1.268
SPARE_P269: J1.269
SPARE_P270: J1.270
SPARE_P271: J1.271
SPARE_P272: J1.272
SPARE_P273: J1.273
SPARE_P274: J1.274
SPARE_P275: J1.275
SPARE_P276: J1.276
SPARE_P277: J1.277
SPARE_P278: J1.278
SPARE_P279: J1.279
SPARE_P280: J1.280
SPARE_P281: J1.281
SPARE_P282: J1.282
SSI0_CE0: IC1.45 (SFC_CE0_PA28), J1.127, U4.1 (~CS)
SSI0_CE1: J1.128
SSI0_CLK: IC1.48 (SFC_CLK_PA27), J1.124, U4.6 (CLK)
SSI0_DR: IC1.46 (SFC_DR_PA24), J1.126, U4.5 (DI/IO_{0})
SSI0_DT: IC1.47 (SFC_DT_PA23), J1.125, U4.2 (DO/IO_{1})
SSI0_GPC: J1.129
SSI1_CE0: IC1.81 (SSI1_CE0_DMIC_DAT1_PB30), J1.134
SSI1_CLK: IC1.82 (SSI1_CLK_DMIC_DAT0_PB29), J1.131
SSI1_DR: J1.133
SSI1_DT: J1.132
UART0_CTS: IC1.69 (UART0_CTS_I2S_ADC_BCLK_SLCD_CS_PB20), J1.100
UART0_RTS: IC1.68 (UART0_RTS_I2S_DAC_BCLK_SLCD_DC_PB21), J1.101
UART0_RXD: IC1.71 (UART0_RXD_TDI_PB19), J1.98
UART0_TXD: IC1.70 (UART0_TXD_TDO_SLCD_RDY_PB22), J1.99
UART1_RX: J1.42
UART1_TX: J1.43
UART2_CTS: IC1.21 (SD2_DVP_D8_UART2_CTS_MSC1_D0_PA08), J1.105
UART2_RTS: IC1.20 (SD3_DVP_D9_UART2_RTS_MSC1_D1_PA09), J1.106
UART2_RXD: IC1.18 (SD5_DVP_D11_UART2_RXD_MSC1_D3_PA11), J1.103
UART2_TXD: IC1.19 (SD4_DVP_D10_UART2_TXD_MSC1_D2_PA10), J1.104
UART3_CTS: J1.110
UART3_RTS: J1.111
UART3_RXD: J1.108
UART3_TXD: J1.109
USBA_HOST_DM: IC1.35 (USB0PN), J1.21, TP7.1
USBA_HOST_DP: IC1.36 (USB0PP), J1.20, TP6.1
VCORE_SNS: J1.23
VDDR: J1.9, J1.10

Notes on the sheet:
SoC (T31ZX reference)
DDR4 UDIMM-288 CARD EDGE

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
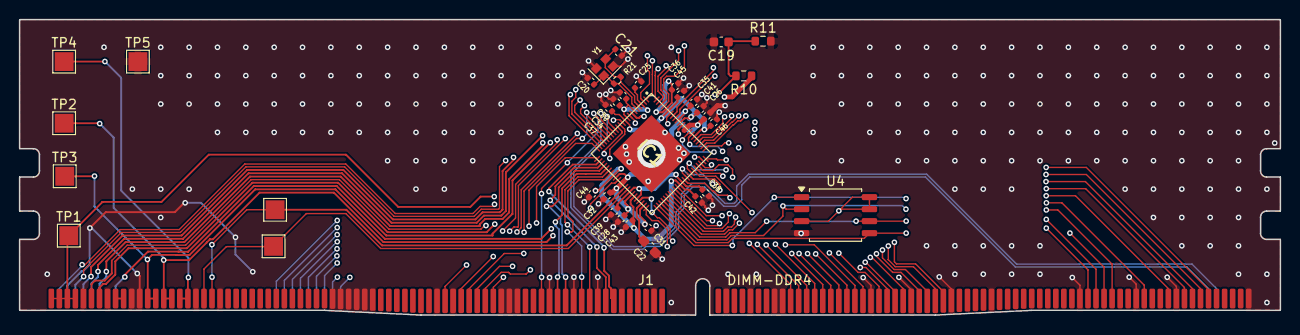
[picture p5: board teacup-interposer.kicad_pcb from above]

Board: 4 copper layers, 133.3 x 31.2 mm, 36 parts (0 on the bottom side), 72 nets.

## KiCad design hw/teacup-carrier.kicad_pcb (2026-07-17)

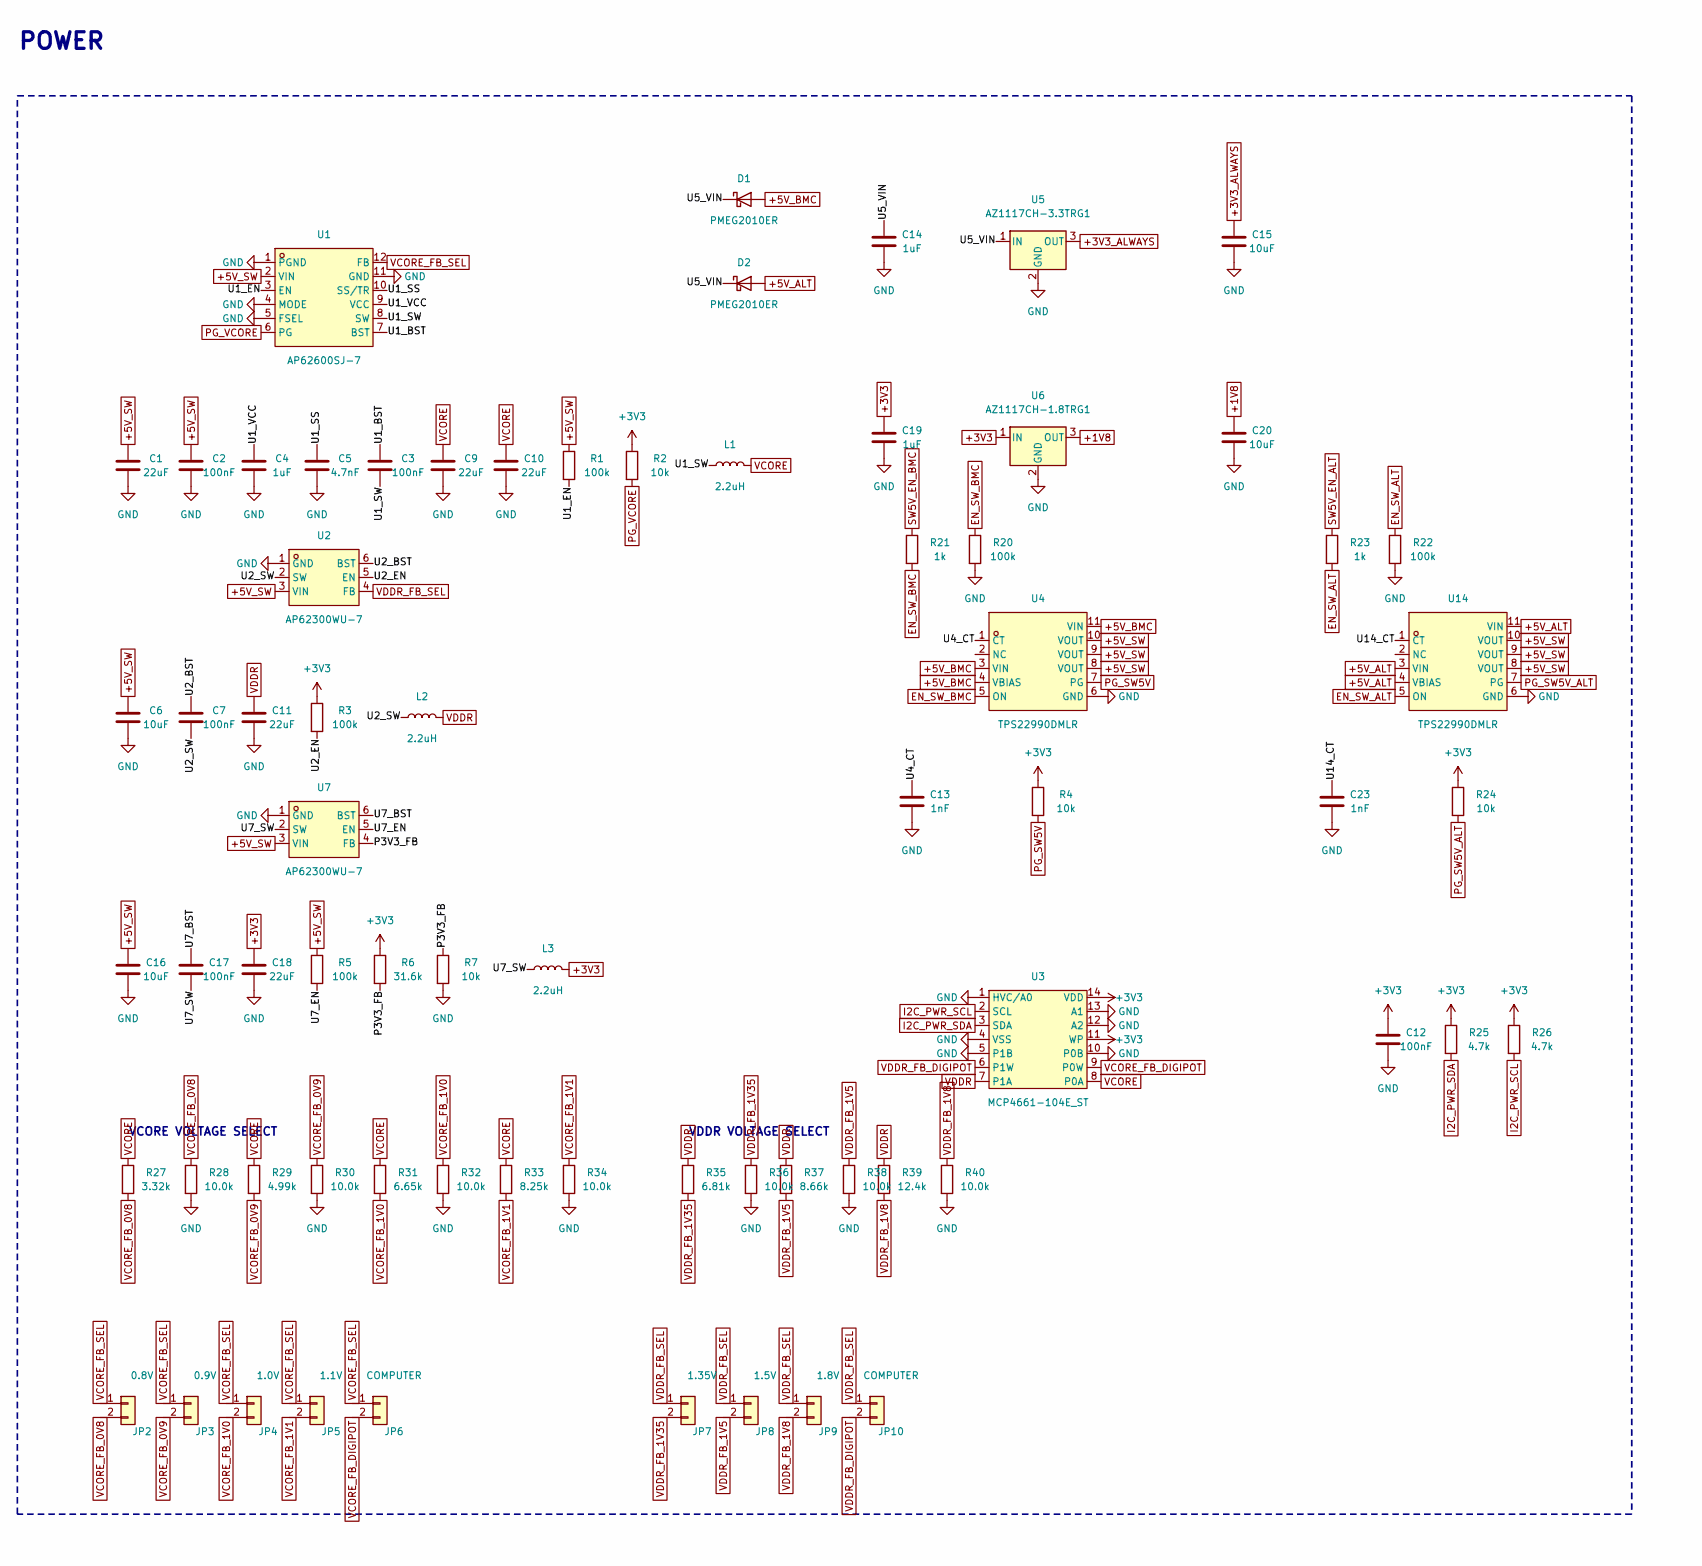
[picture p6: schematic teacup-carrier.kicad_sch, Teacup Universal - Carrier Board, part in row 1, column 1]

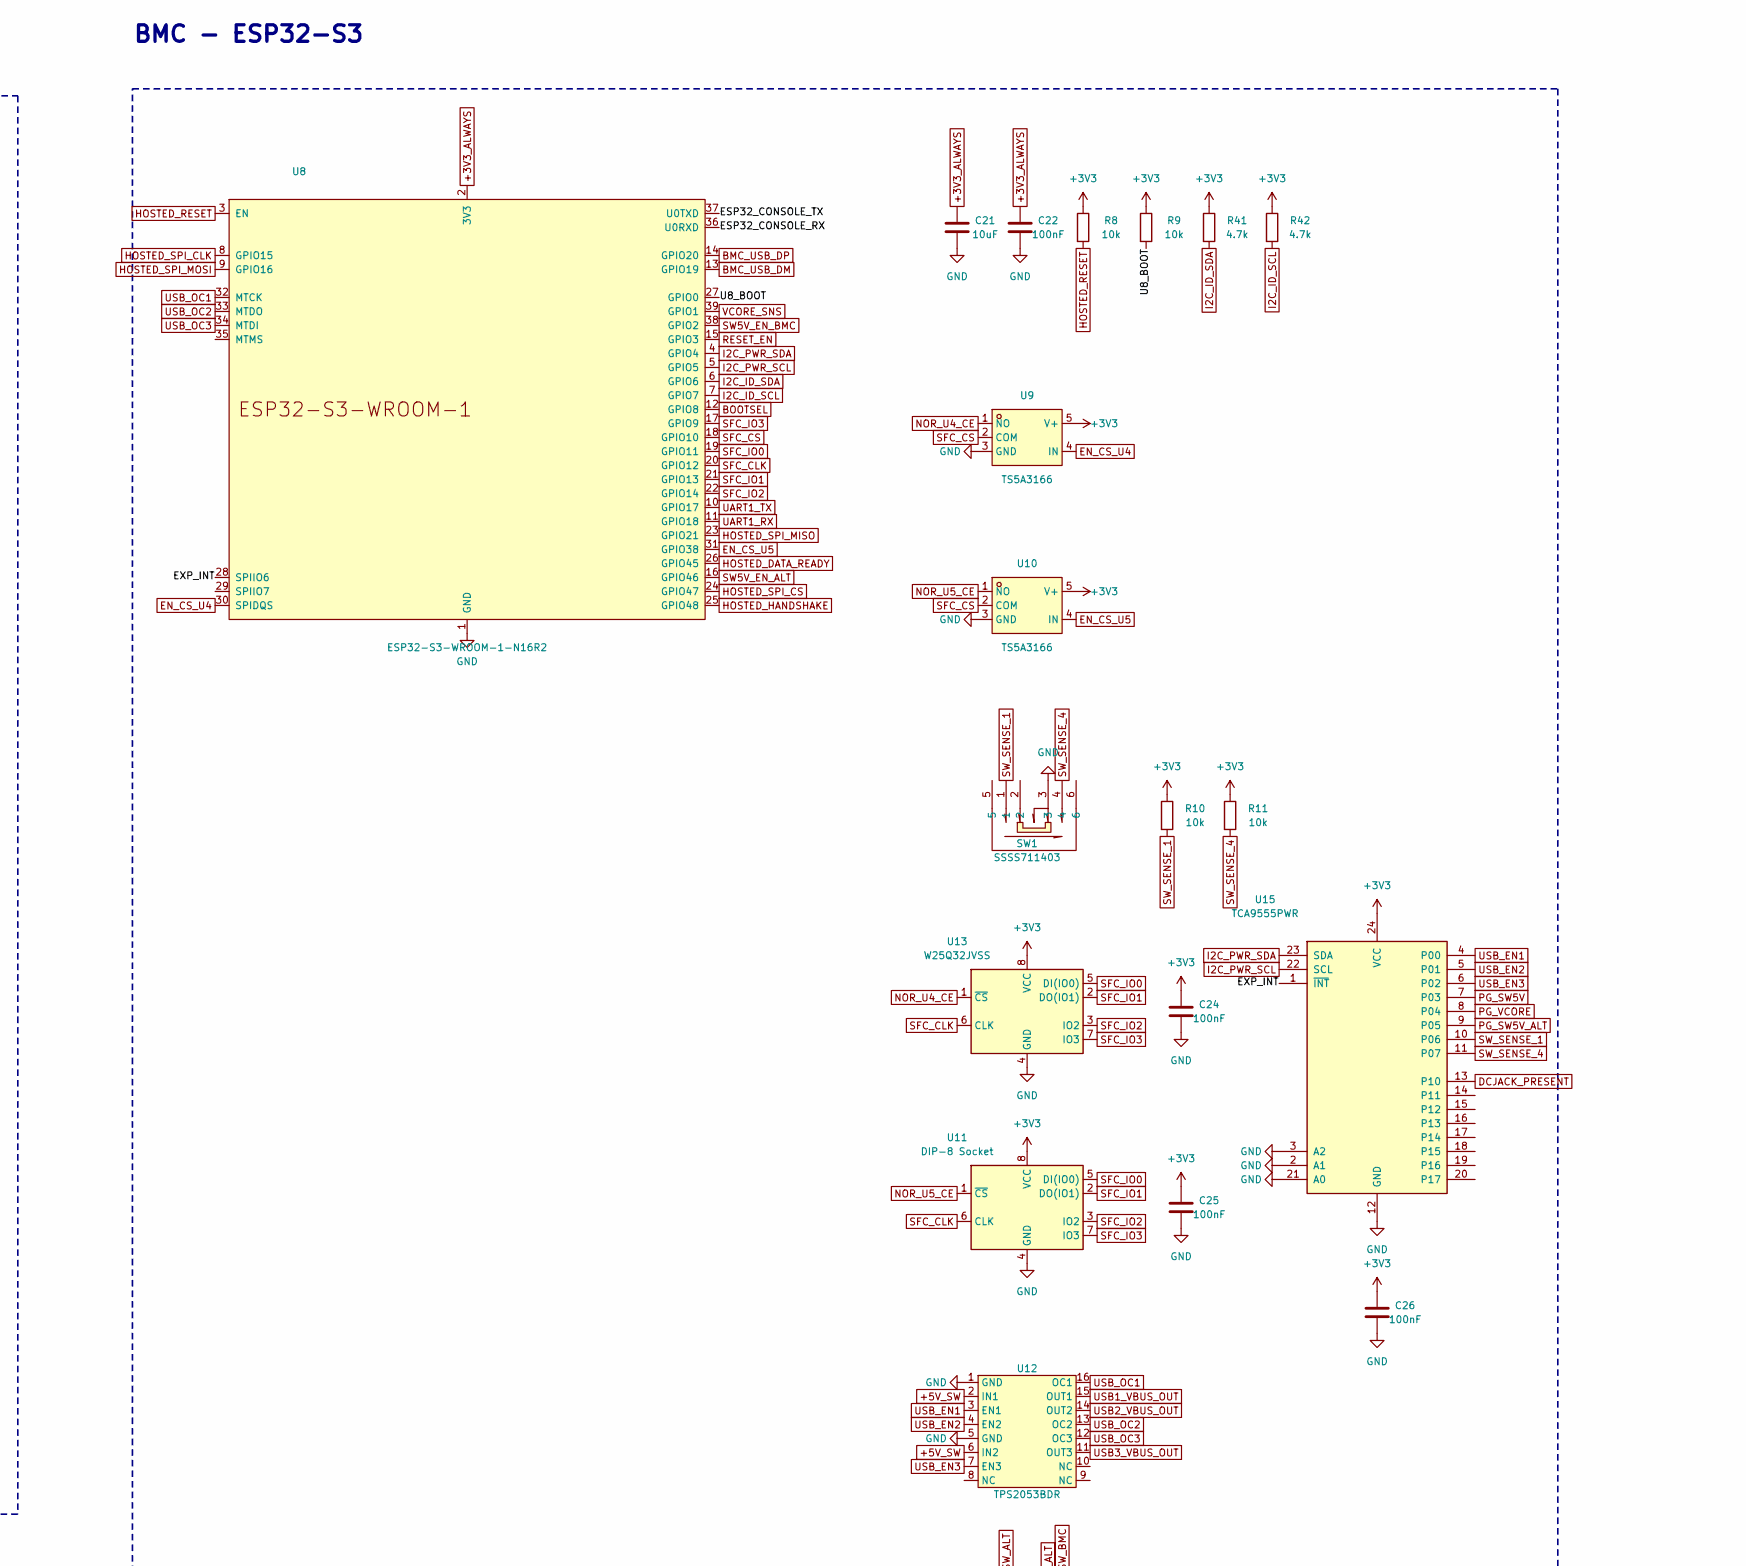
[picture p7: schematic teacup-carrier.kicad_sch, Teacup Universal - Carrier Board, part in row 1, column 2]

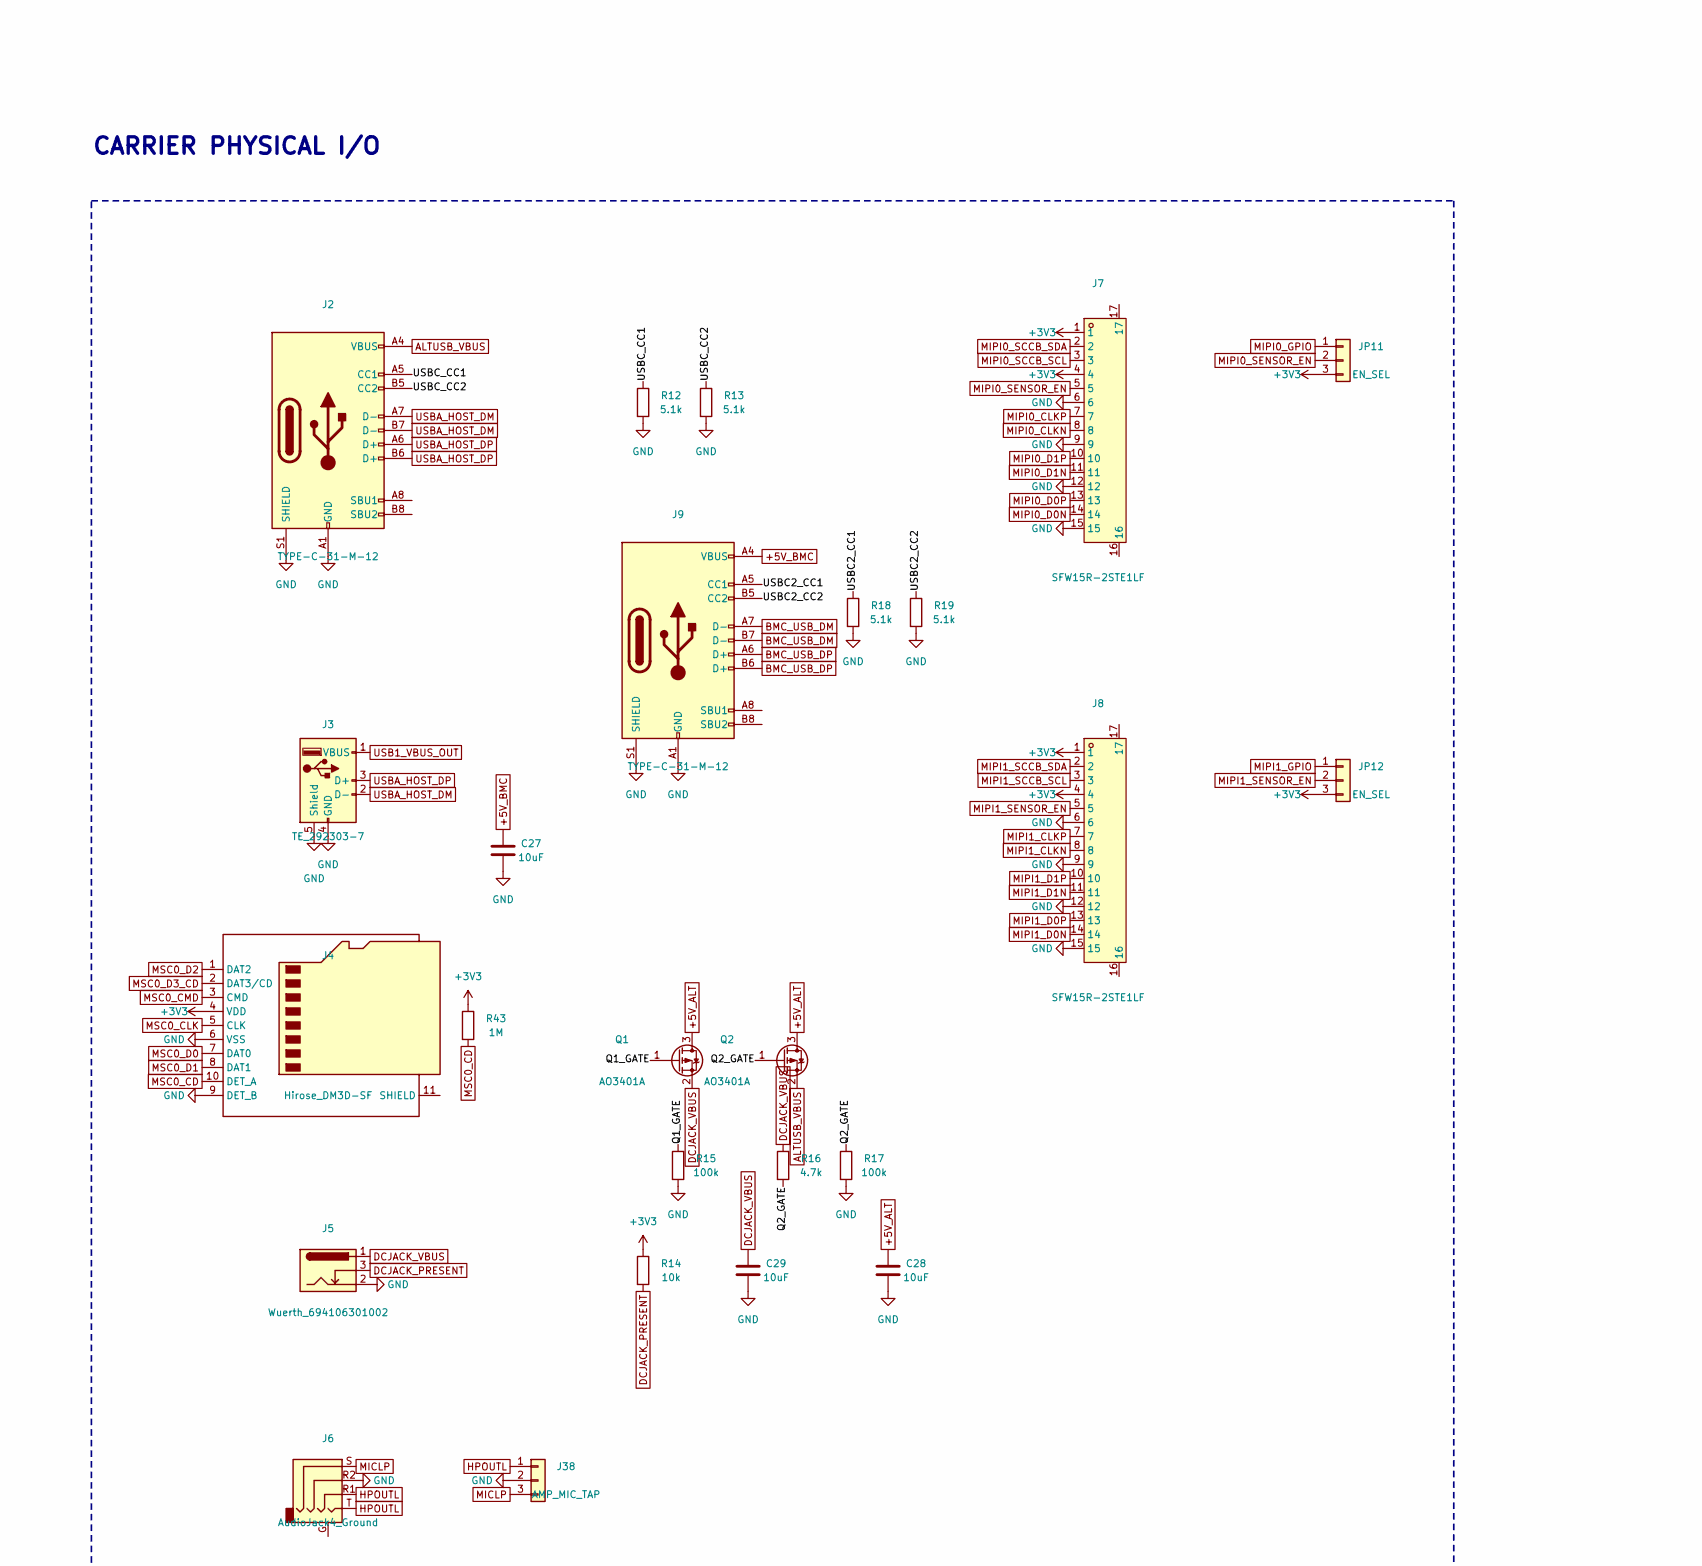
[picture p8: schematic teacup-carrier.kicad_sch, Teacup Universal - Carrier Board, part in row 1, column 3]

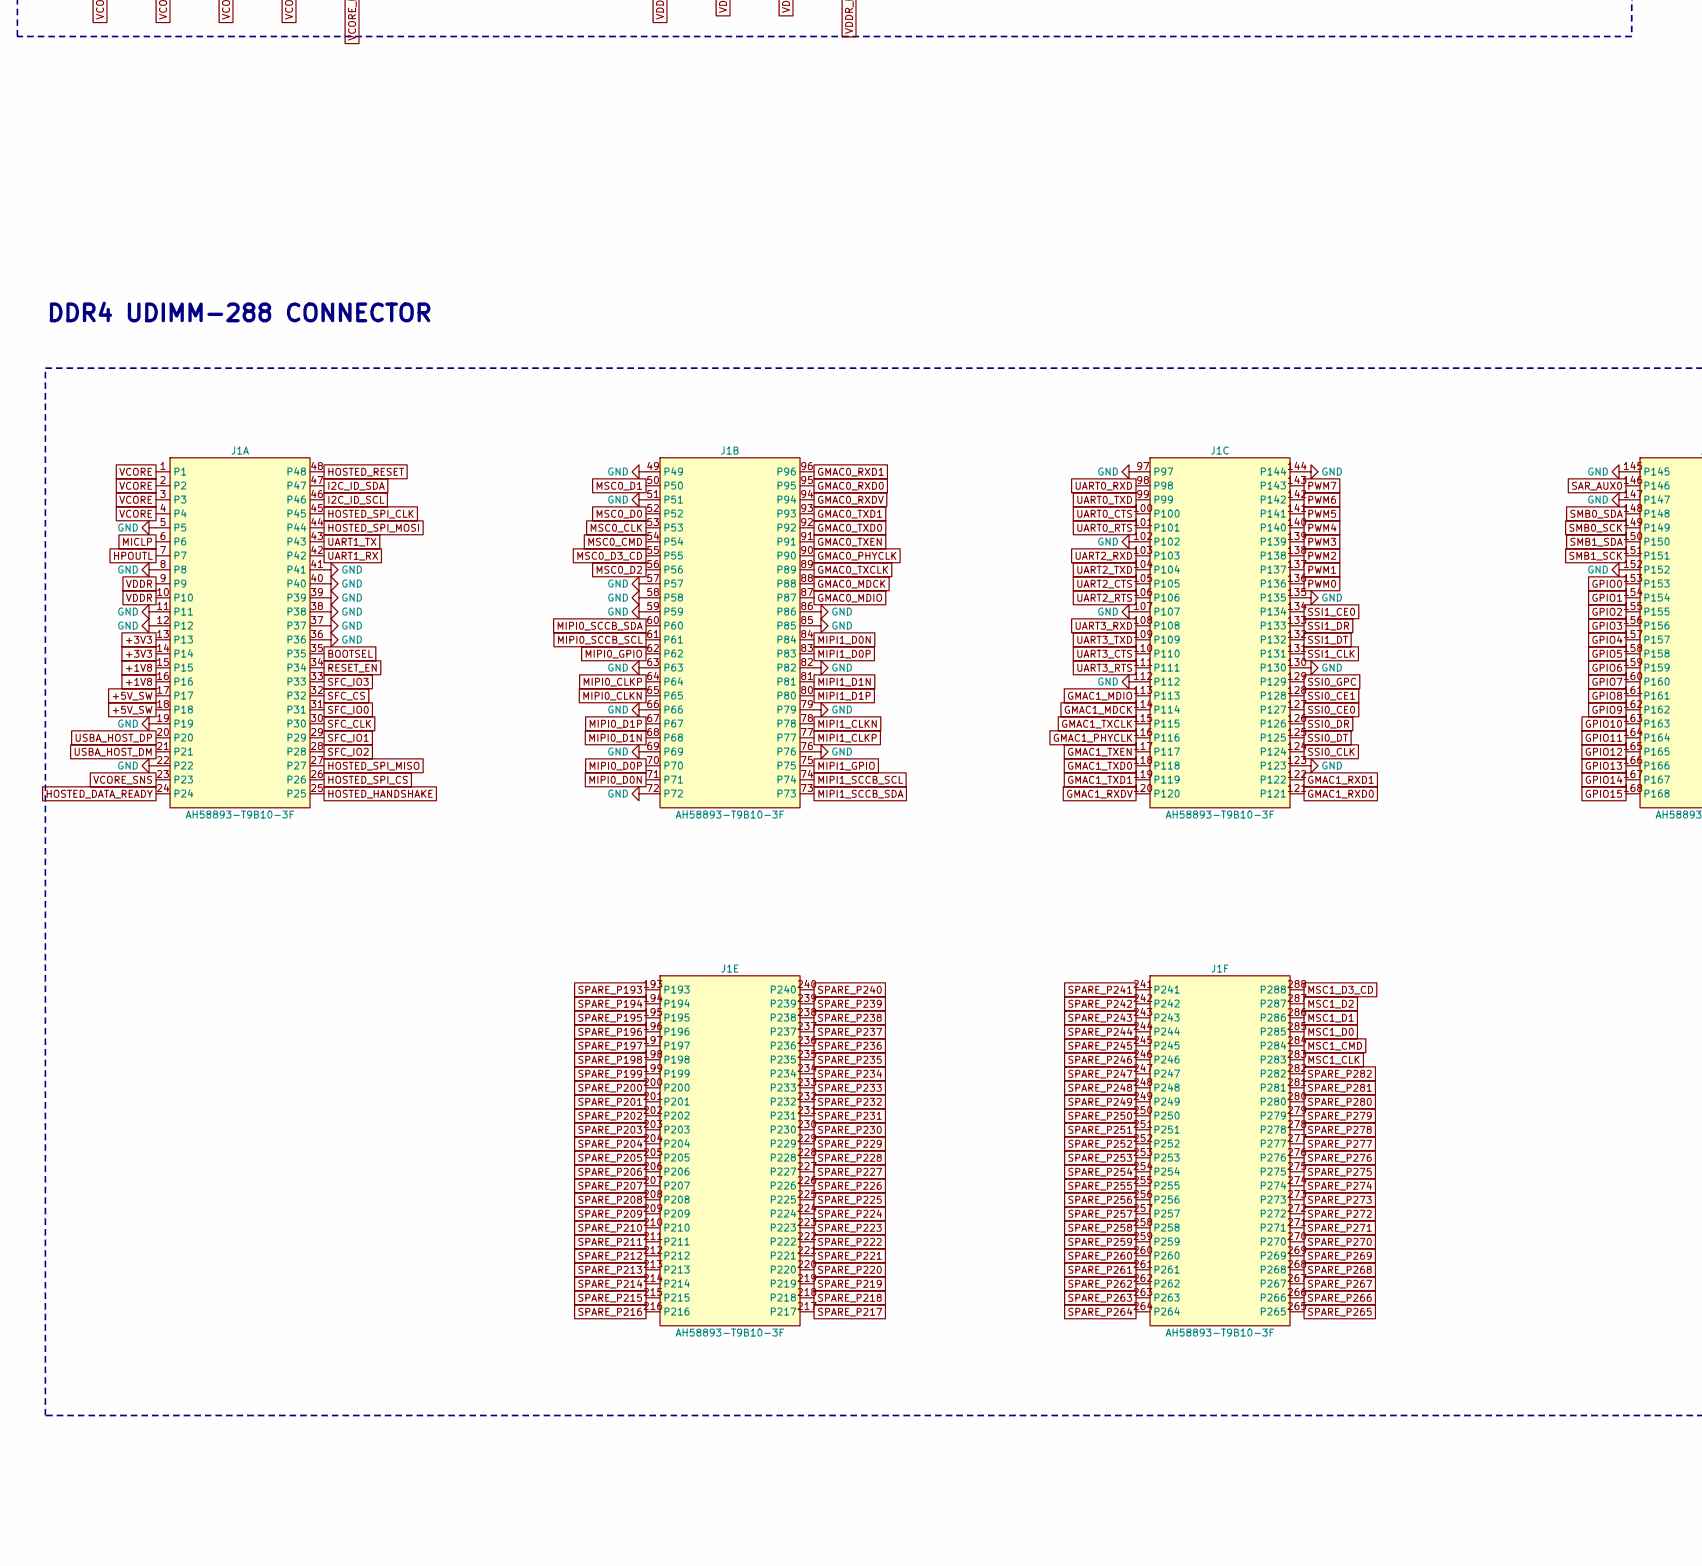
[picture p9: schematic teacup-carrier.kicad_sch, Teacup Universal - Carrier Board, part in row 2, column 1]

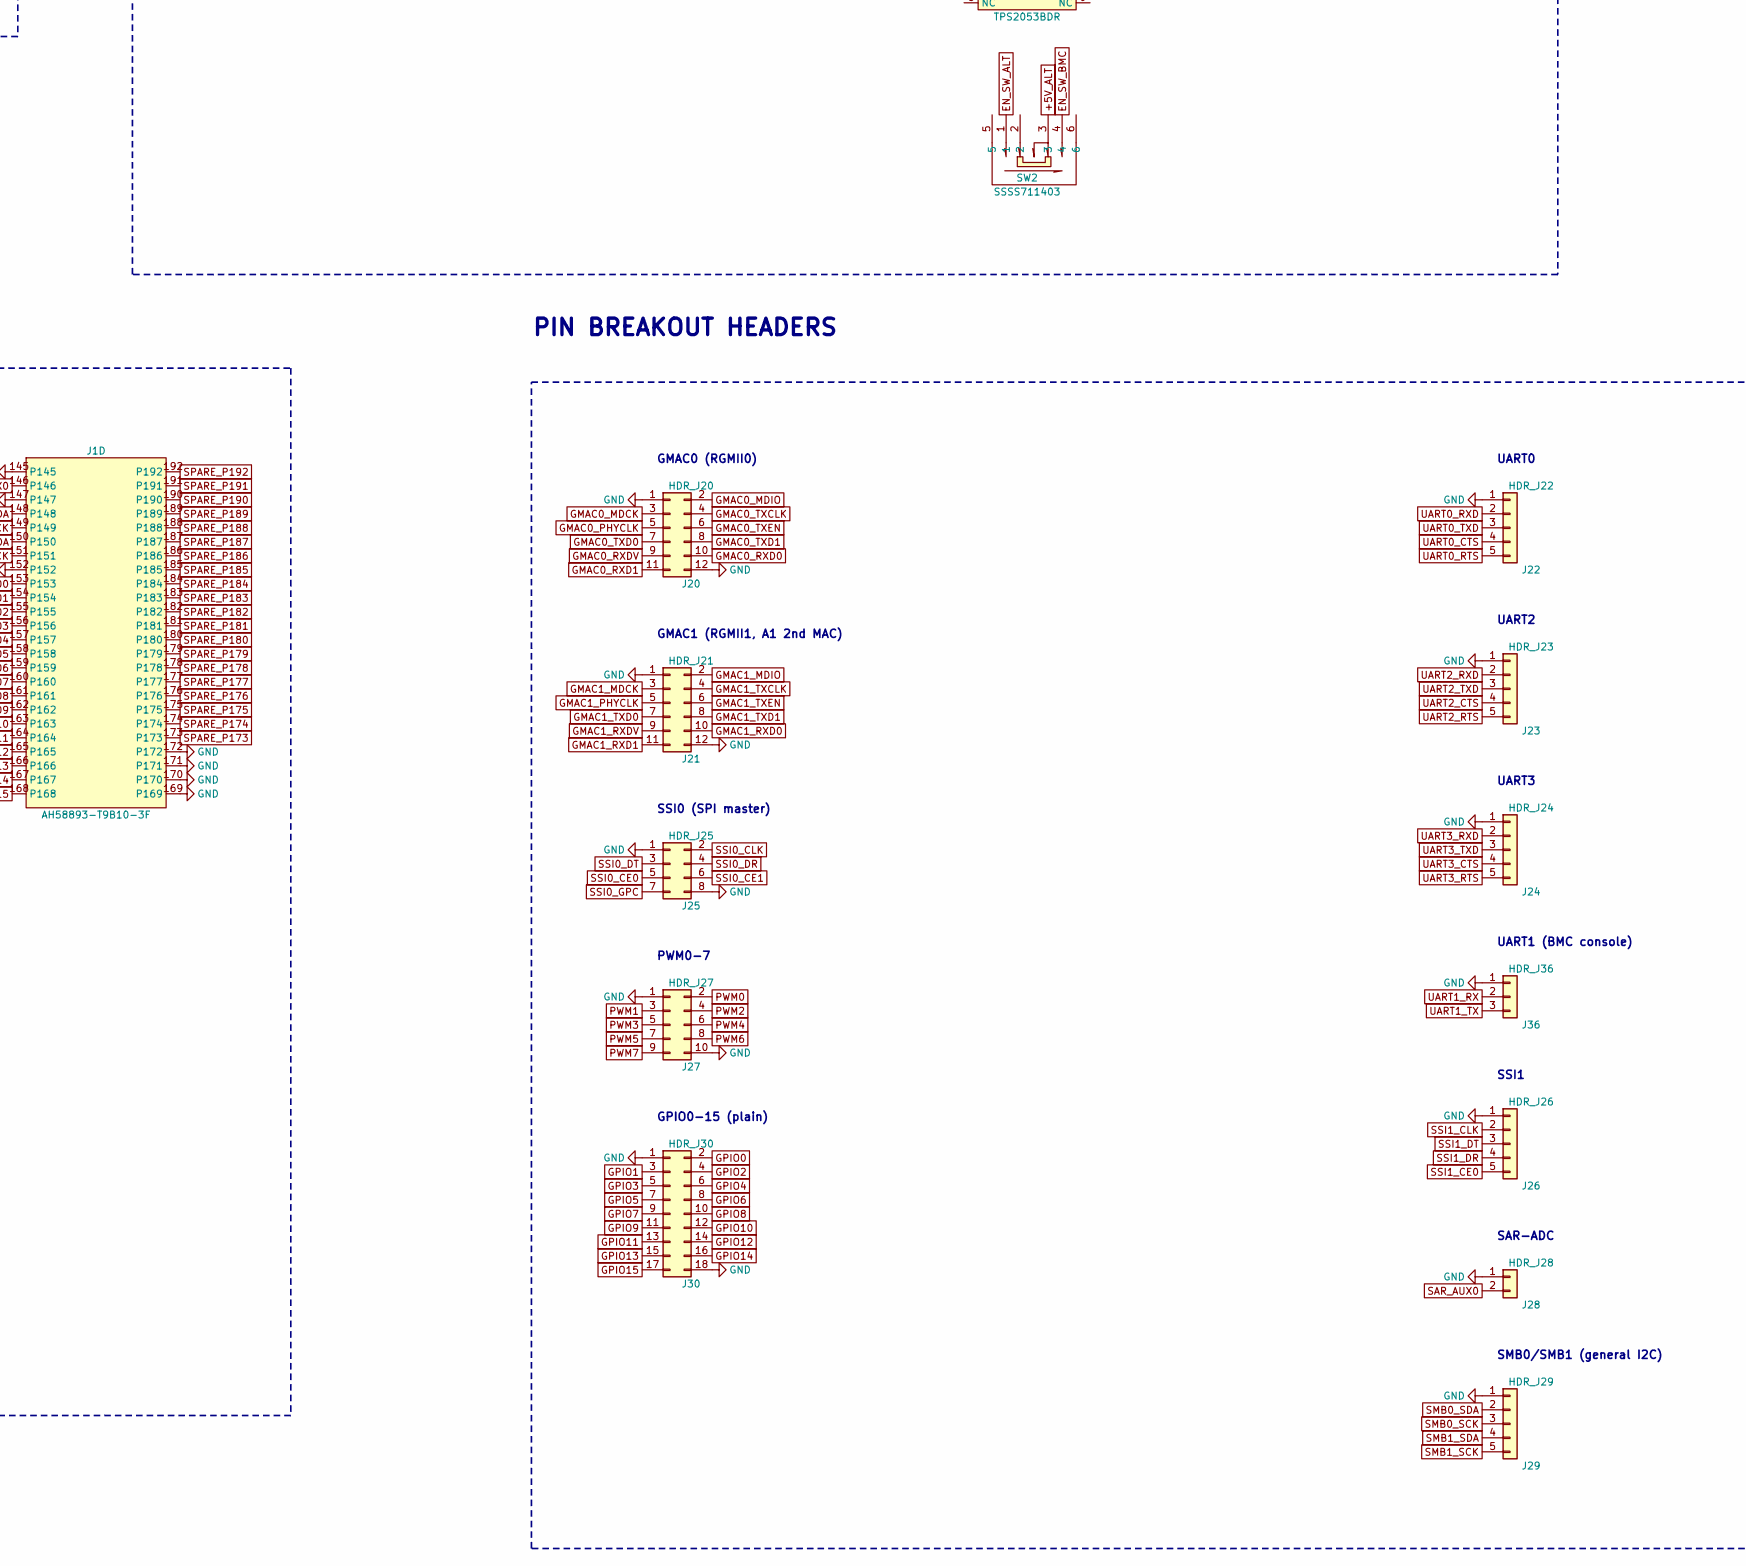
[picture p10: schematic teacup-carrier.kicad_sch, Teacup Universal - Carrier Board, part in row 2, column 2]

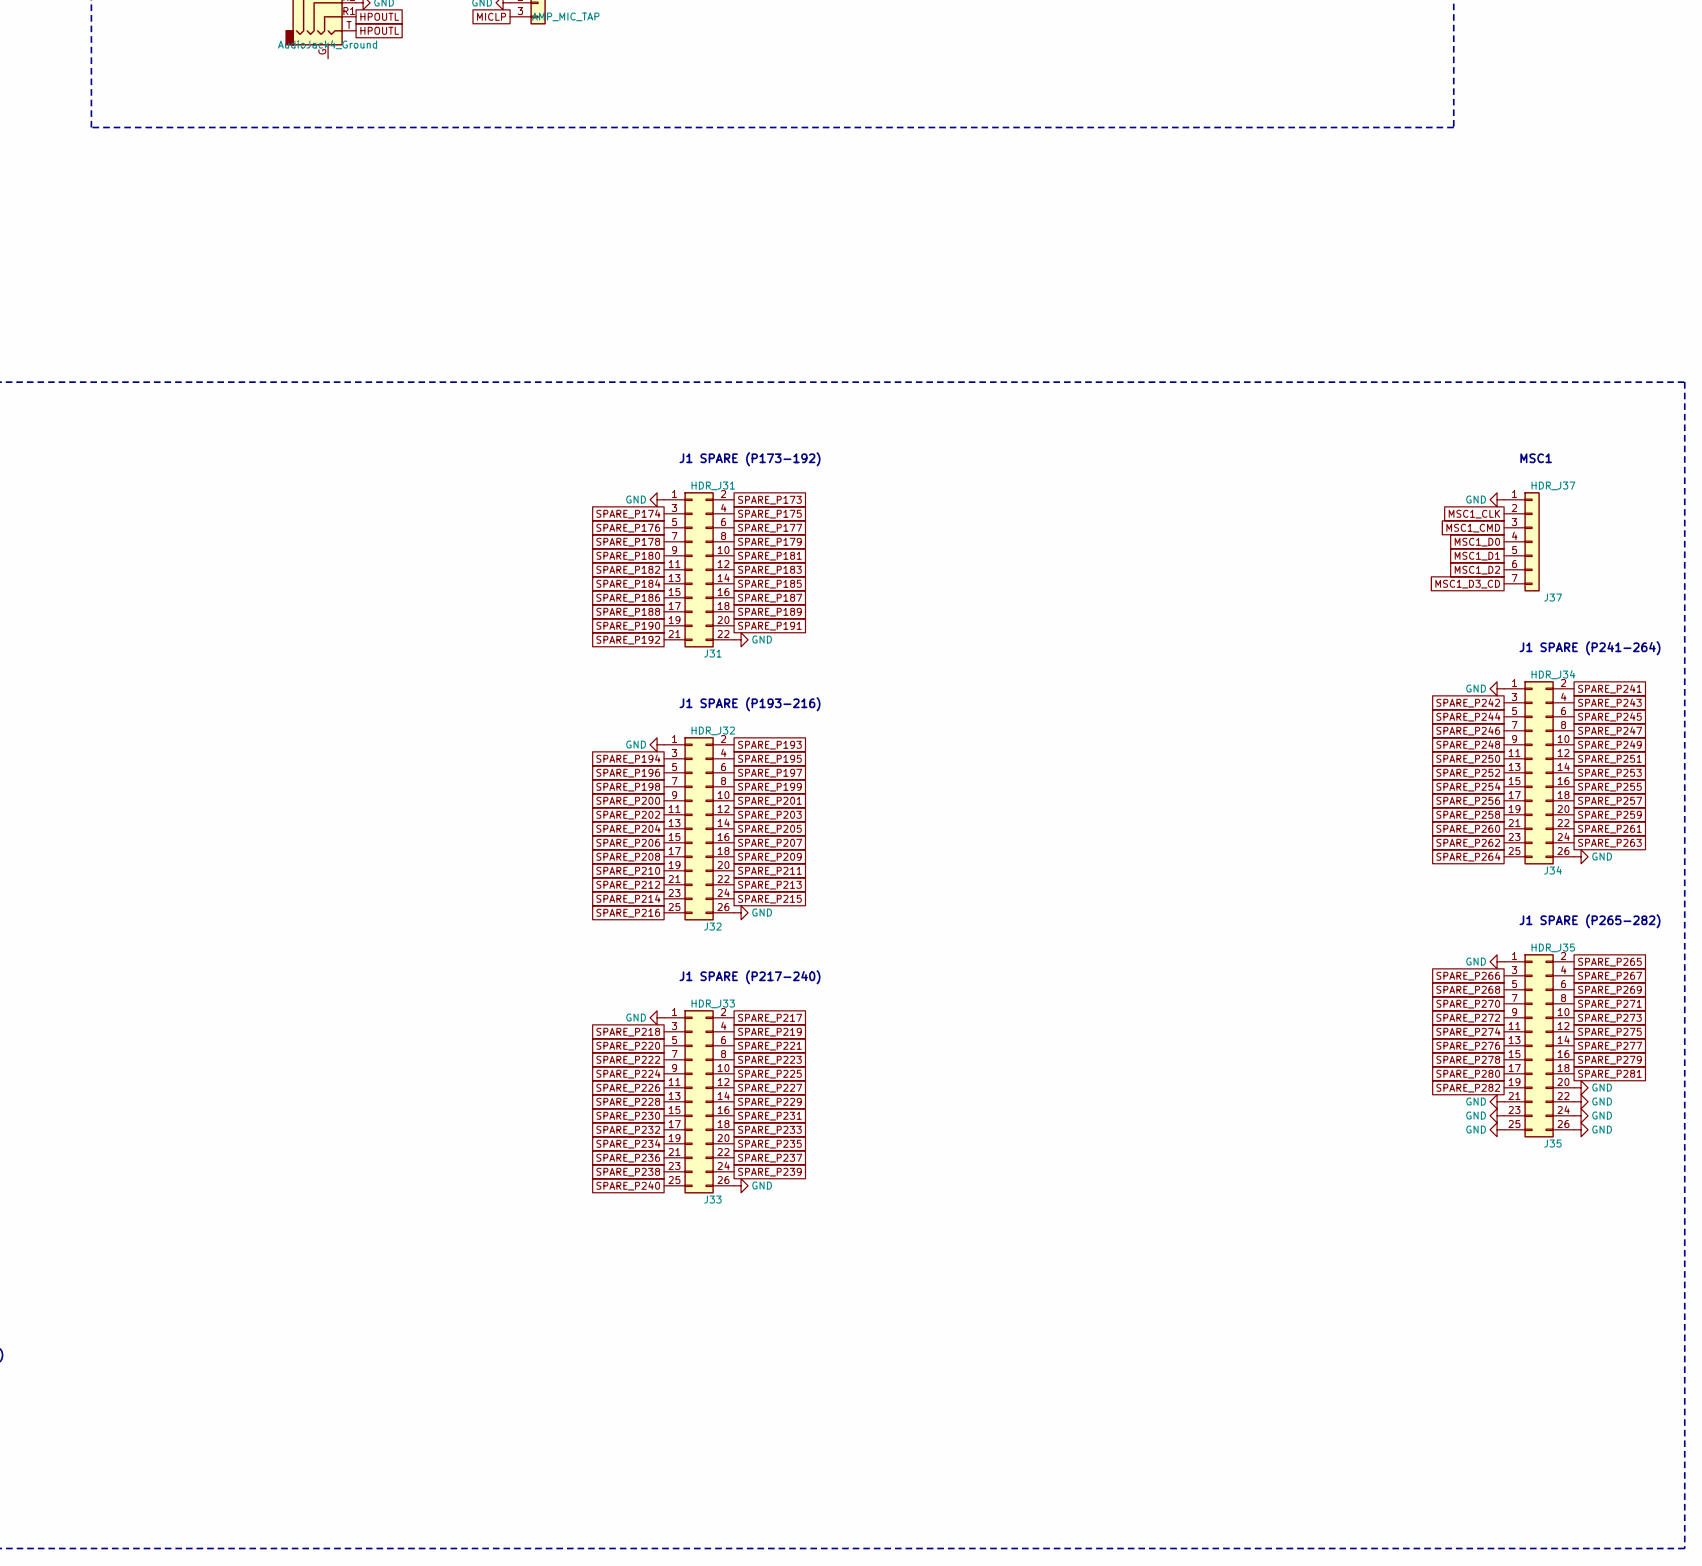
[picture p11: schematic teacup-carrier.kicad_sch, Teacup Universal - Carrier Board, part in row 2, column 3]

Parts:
C1, C9, C10, C11, C18: 22uF; C_0805_2012Metric
C2, C3, C7, C12, C17, C22, C24, C25, C26: 100nF; C_0402_1005Metric
C4: 1uF; C_0402_1005Metric
C5: 4.7nF; C_0402_1005Metric
C6, C15, C16, C20, C21, C27, C28, C29: 10uF; C_0805_2012Metric
C13, C23: 1nF; C_0402_1005Metric
C14, C19: 1uF; C_0603_1608Metric
D1, D2: PMEG2010ER; Nexperia_CFP3_SOD-123W
J1: AH58893-T9B10-3F; DDR4288S0511H_UDIMM288
J2, J9: TYPE-C-31-M-12; USB_C_Receptacle_HRO_TYPE-C-31-M-12
J3: TE_292303-7; USB_A_TE_292303-7_Horizontal
J4: Hirose_DM3D-SF; microSD_HC_Hirose_DM3D-SF
J5: Wuerth_694106301002; BarrelJack_Wuerth_6941xx301002
J6: AudioJack4_Ground; Jack_3.5mm_PJ320D_Horizontal
J7, J8: SFW15R-2STE1LF; FPC-SMD_15P-P1.00_SFW15R-2STE1LF
J20: HDR_J20; PinHeader_2x06_P2.54mm_Vertical
J21: HDR_J21; PinHeader_2x06_P2.54mm_Vertical
J22: HDR_J22; PinHeader_1x05_P2.54mm_Vertical
J23: HDR_J23; PinHeader_1x05_P2.54mm_Vertical
J24: HDR_J24; PinHeader_1x05_P2.54mm_Vertical
J25: HDR_J25; PinHeader_2x04_P2.54mm_Vertical
J26: HDR_J26; PinHeader_1x05_P2.54mm_Vertical
J27: HDR_J27; PinHeader_2x05_P2.54mm_Vertical
J28: HDR_J28; PinHeader_1x02_P2.54mm_Vertical
J29: HDR_J29; PinHeader_1x05_P2.54mm_Vertical
J30: HDR_J30; PinHeader_2x09_P2.54mm_Vertical
J31: HDR_J31; PinHeader_2x11_P2.54mm_Vertical
J32: HDR_J32; PinHeader_2x13_P2.54mm_Vertical
J33: HDR_J33; PinHeader_2x13_P2.54mm_Vertical
J34: HDR_J34; PinHeader_2x13_P2.54mm_Vertical
J35: HDR_J35; PinHeader_2x13_P2.54mm_Vertical
J36: HDR_J36; PinHeader_1x03_P2.54mm_Vertical
J37: HDR_J37; PinHeader_1x07_P2.54mm_Vertical
J38: AMP_MIC_TAP; PinHeader_1x03_P2.54mm_Vertical
JP2: 0.8V; PinHeader_1x02_P2.54mm_Vertical
JP3: 0.9V; PinHeader_1x02_P2.54mm_Vertical
JP4: 1.0V; PinHeader_1x02_P2.54mm_Vertical
JP5: 1.1V; PinHeader_1x02_P2.54mm_Vertical
JP6, JP10: COMPUTER; PinHeader_1x02_P2.54mm_Vertical
JP7: 1.35V; PinHeader_1x02_P2.54mm_Vertical
JP8: 1.5V; PinHeader_1x02_P2.54mm_Vertical
JP9: 1.8V; PinHeader_1x02_P2.54mm_Vertical
JP11, JP12: EN_SEL; PinHeader_1x03_P2.54mm_Vertical_SMD_Pin1Left
L1, L2, L3: 2.2uH; L_1210_3225Metric
Q1, Q2: AO3401A; SOT-23
R1, R3, R5, R15, R17, R20, R22: 100k; R_0402_1005Metric
R2, R4, R7, R8, R9, R10, R11, R14, R24: 10k; R_0402_1005Metric
R6: 31.6k; R_0402_1005Metric
R12, R13, R18, R19: 5.1k; R_0402_1005Metric
R16, R25, R26, R41, R42: 4.7k; R_0402_1005Metric
R21, R23: 1k; R_0402_1005Metric
R27: 3.32k; R_0402_1005Metric
R28, R30, R32, R34, R36, R38, R40: 10.0k; R_0402_1005Metric
R29: 4.99k; R_0402_1005Metric
R31: 6.65k; R_0402_1005Metric
R33: 8.25k; R_0402_1005Metric
R35: 6.81k; R_0402_1005Metric
R37: 8.66k; R_0402_1005Metric
R39: 12.4k; R_0402_1005Metric
R43: 1M; R_0402_1005Metric
SW1, SW2: SSSS711403; SW-TH_SSSS711403
U1: AP62600SJ-7; QFN-12_L3.0-W2.0-P0.50-TL_AP62600SJ-7
U2, U7: AP62300WU-7; TSOT-23-6_L2.9-W1.6-P0.95-LS2.8-BL
U3: MCP4661-104E_ST; TSSOP-14_4.4x5mm_P0.65mm
U4, U14: TPS22990DMLR; WSON-10_L3.0-W2.0-P0.50-BL-EP_TI_DML
U5: AZ1117CH-3.3TRG1; SOT-223-3_TabPin2
U6: AZ1117CH-1.8TRG1; SOT-223-3_TabPin2
U8: ESP32-S3-WROOM-1-N16R2; ESP32-S3-WROOM-1
U9, U10: TS5A3166; SOT-23-5
U11: DIP-8 Socket; DIP-8_W7.62mm_Socket
U12: TPS2053BDR; SOIC-16_3.9x9.9mm_P1.27mm
U13: W25Q32JVSS; SOIC-8_5.3x5.3mm_P1.27mm
U15: TCA9555PWR; TSSOP-24_4.4x7.8mm_P0.65mm

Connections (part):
+1V8: C20.1, J1.15, J1.16, U6.3 (OUT)
+3V3: C12.1, C18.1, C19.1, C24.1, C25.1, C26.1, J1.13, J1.14, J4.4 (VDD), J7.1, J7.4, J8.1, J8.4, JP11.3, JP12.3, L3.2, R2.1, R3.1, R4.1, R6.1, R8.1, R9.1, R10.1, R11.1, R14.1, R24.1, R25.1, R26.1, R41.1, R42.1, R43.1, U3.11 (WP), U3.14 (VDD), U6.1 (IN), U9.5 (V+), U10.5 (V+), U11.8 (VCC), U13.8 (VCC), U15.24 (VCC)
+3V3_ALWAYS: C15.1, C21.1, C22.1, U5.3 (OUT), U8.2 (3V3)
+5V_ALT: C28.1, D2.2 (A), Q1.3 (D), Q2.3 (D), SW2.3, U14.3 (VIN), U14.4 (VBIAS), U14.11 (VIN)
+5V_BMC: C27.1, D1.2 (A), J9.A4 (VBUS), J9.A9 (VBUS), J9.B4 (VBUS), J9.B9 (VBUS), U4.3 (VIN), U4.4 (VBIAS), U4.11 (VIN)
+5V_SW: C1.1, C2.1, C6.1, C16.1, J1.17, J1.18, R1.1, R5.1, U1.2 (VIN), U2.3 (VIN), U4.8 (VOUT), U4.9 (VOUT), U4.10 (VOUT), U7.3 (VIN), U12.2 (IN1), U12.6 (IN2), U14.8 (VOUT), U14.9 (VOUT), U14.10 (VOUT)
/ESP32_CONSOLE_RX: U8.36 (U0RXD)
/ESP32_CONSOLE_TX: U8.37 (U0TXD)
/EXP_INT: U8.28 (SPIIO6), U15.1 (~INT)
/P3V3_FB: R6.2, R7.1, U7.4 (FB)
/Q1_GATE: Q1.1 (G), R15.1
/Q2_GATE: Q2.1 (G), R16.2, R17.1
/U1_BST: C3.1, U1.7 (BST)
/U1_EN: R1.2, U1.3 (EN)
/U1_SS: C5.1, U1.10 (SS/TR)
/U1_SW: C3.2, L1.1, U1.8 (SW)
/U1_VCC: C4.1, U1.9 (VCC)
/U2_BST: C7.1, U2.6 (BST)
/U2_EN: R3.2, U2.5 (EN)
/U2_SW: C7.2, L2.1, U2.2 (SW)
/U4_CT: C13.1, U4.1 (CT)
/U5_VIN: C14.1, D1.1 (K), D2.1 (K), U5.1 (IN)
/U7_BST: C17.1, U7.6 (BST)
/U7_EN: R5.2, U7.5 (EN)
/U7_SW: C17.2, L3.1, U7.2 (SW)
/U8_BOOT: R9.2, U8.27 (GPIO0)
/U14_CT: C23.1, U14.1 (CT)
/USBC2_CC1: J9.A5 (CC1), R18.1
/USBC2_CC2: J9.B5 (CC2), R19.1
/USBC_CC1: J2.A5 (CC1), R12.1
/USBC_CC2: J2.B5 (CC2), R13.1
ALTUSB_VBUS: J2.A4 (VBUS), J2.A9 (VBUS), J2.B4 (VBUS), J2.B9 (VBUS), Q2.2 (S)
BMC_USB_DM: J9.A7 (D-), J9.B7 (D-), U8.13 (GPIO19)
BMC_USB_DP: J9.A6 (D+), J9.B6 (D+), U8.14 (GPIO20)
BOOTSEL: J1.35, U8.12 (GPIO8)
DCJACK_PRESENT: J5.3, R14.2, U15.13 (P10)
DCJACK_VBUS: C29.1, J5.1, Q1.2 (S), R16.1
EN_CS_U4: U8.30 (SPIDQS), U9.4 (IN)
EN_CS_U5: U8.31 (GPIO38), U10.4 (IN)
EN_SW_ALT: R22.1, R23.2, SW2.1, U14.5 (ON)
EN_SW_BMC: R20.1, R21.2, SW2.4, U4.5 (ON)
GMAC0_MDCK: J1.88, J20.3
GMAC0_MDIO: J1.87, J20.2
GMAC0_PHYCLK: J1.90, J20.5
GMAC0_RXD0: J1.95, J20.10
GMAC0_RXD1: J1.96, J20.11
GMAC0_RXDV: J1.94, J20.9
GMAC0_TXCLK: J1.89, J20.4
GMAC0_TXD0: J1.92, J20.7
GMAC0_TXD1: J1.93, J20.8
GMAC0_TXEN: J1.91, J20.6
GMAC1_MDCK: J1.114, J21.3
GMAC1_MDIO: J1.113, J21.2
GMAC1_PHYCLK: J1.116, J21.5
GMAC1_RXD0: J1.121, J21.10
GMAC1_RXD1: J1.122, J21.11
GMAC1_RXDV: J1.120, J21.9
GMAC1_TXCLK: J1.115, J21.4
GMAC1_TXD0: J1.118, J21.7
GMAC1_TXD1: J1.119, J21.8
GMAC1_TXEN: J1.117, J21.6
GND: C1.2, C2.2, C4.2, C5.2, C6.2, C9.2, C10.2, C11.2, C12.2, C13.2, C14.2, C15.2, C16.2, C18.2, C19.2, C20.2, C21.2, C22.2, C23.2, C24.2, C25.2, C26.2, C27.2, C28.2, C29.2, J1.5, J1.8, J1.11, J1.12, J1.19, J1.22, J1.36, J1.37, J1.38, J1.39, J1.40, J1.41, J1.49, J1.51, J1.57, J1.58, J1.59, J1.63, J1.66, J1.69, J1.72, J1.76, J1.79, J1.82, J1.85, J1.86, J1.97, J1.102, J1.107, J1.112, J1.123, J1.130, J1.135, J1.144, J1.145, J1.147, J1.152, J1.169, J1.170, J1.171, J1.172, J2.A1 (GND), J2.A12 (GND), J2.B1 (GND), J2.B12 (GND), J2.S1 (SHIELD), J3.4 (GND), J3.5 (Shield), J4.6 (VSS), J4.9 (DET_B), J5.2, J6.R2, J7.6, J7.9, J7.12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
GPIO0: J1.153, J30.2
GPIO1: J1.154, J30.3
GPIO2: J1.155, J30.4
GPIO3: J1.156, J30.5
GPIO4: J1.157, J30.6
GPIO5: J1.158, J30.7
GPIO6: J1.159, J30.8
GPIO7: J1.160, J30.9
GPIO8: J1.161, J30.10
GPIO9: J1.162, J30.11
GPIO10: J1.163, J30.12
GPIO11: J1.164, J30.13
GPIO12: J1.165, J30.14
GPIO13: J1.166, J30.15
GPIO14: J1.167, J30.16
GPIO15: J1.168, J30.17
HOSTED_DATA_READY: J1.24, U8.26 (GPIO45)
HOSTED_HANDSHAKE: J1.25, U8.25 (GPIO48)
HOSTED_RESET: J1.48, R8.2, U8.3 (EN)
HOSTED_SPI_CLK: J1.45, U8.8 (GPIO15)
HOSTED_SPI_CS: J1.26, U8.24 (GPIO47)
HOSTED_SPI_MISO: J1.27, U8.23 (GPIO21)
HOSTED_SPI_MOSI: J1.44, U8.9 (GPIO16)
HPOUTL: J1.7, J6.R1, J6.T, J38.1
I2C_ID_SCL: J1.46, R42.2, U8.7 (GPIO7)
I2C_ID_SDA: J1.47, R41.2, U8.6 (GPIO6)
I2C_PWR_SCL: R26.2, U3.2 (SCL), U8.5 (GPIO5), U15.22 (SCL)
I2C_PWR_SDA: R25.2, U3.3 (SDA), U8.4 (GPIO4), U15.23 (SDA)
MICLP: J1.6, J6.S, J38.3
MIPI0_CLKN: J1.65, J7.8
MIPI0_CLKP: J1.64, J7.7
MIPI0_D0N: J1.71, J7.14
MIPI0_D0P: J1.70, J7.13
MIPI0_D1N: J1.68, J7.11
MIPI0_D1P: J1.67, J7.10
MIPI0_GPIO: J1.62, JP11.1
MIPI0_SCCB_SCL: J1.61, J7.3
MIPI0_SCCB_SDA: J1.60, J7.2
MIPI0_SENSOR_EN: J7.5, JP11.2
MIPI1_CLKN: J1.78, J8.8
MIPI1_CLKP: J1.77, J8.7
MIPI1_D0N: J1.84, J8.14
MIPI1_D0P: J1.83, J8.13
MIPI1_D1N: J1.81, J8.11
MIPI1_D1P: J1.80, J8.10
MIPI1_GPIO: J1.75, JP12.1
MIPI1_SCCB_SCL: J1.74, J8.3
MIPI1_SCCB_SDA: J1.73, J8.2
MIPI1_SENSOR_EN: J8.5, JP12.2
MSC0_CD: J4.10 (DET_A), R43.2
MSC0_CLK: J1.53, J4.5 (CLK)
MSC0_CMD: J1.54, J4.3 (CMD)
MSC0_D0: J1.52, J4.7 (DAT0)
MSC0_D1: J1.50, J4.8 (DAT1)
MSC0_D2: J1.56, J4.1 (DAT2)
MSC0_D3_CD: J1.55, J4.2 (DAT3/CD)
MSC1_CLK: J1.283, J37.2
MSC1_CMD: J1.284, J37.3
MSC1_D0: J1.285, J37.4
MSC1_D1: J1.286, J37.5
MSC1_D2: J1.287, J37.6
MSC1_D3_CD: J1.288, J37.7
NOR_U4_CE: U9.1 (NO), U13.1 (~CS)
NOR_U5_CE: U10.1 (NO), U11.1 (~CS)
PG_SW5V: R4.2, U4.7 (PG), U15.7 (P03)
PG_SW5V_ALT: R24.2, U14.7 (PG), U15.9 (P05)
PG_VCORE: R2.2, U1.6 (PG), U15.8 (P04)
PWM0: J1.136, J27.2
PWM1: J1.137, J27.3
PWM2: J1.138, J27.4
PWM3: J1.139, J27.5
PWM4: J1.140, J27.6
PWM5: J1.141, J27.7
PWM6: J1.142, J27.8
PWM7: J1.143, J27.9
RESET_EN: J1.34, U8.15 (GPIO3)
SAR_AUX0: J1.146, J28.2
SFC_CLK: J1.30, U8.20 (GPIO12), U11.6 (CLK), U13.6 (CLK)
SFC_CS: J1.32, U8.18 (GPIO10), U9.2 (COM), U10.2 (COM)
SFC_IO0: J1.31, U8.19 (GPIO11), U11.5 (DI(IO0)), U13.5 (DI(IO0))
SFC_IO1: J1.29, U8.21 (GPIO13), U11.2 (DO(IO1)), U13.2 (DO(IO1))
SFC_IO2: J1.28, U8.22 (GPIO14), U11.3 (IO2), U13.3 (IO2)
SFC_IO3: J1.33, U8.17 (GPIO9), U11.7 (IO3), U13.7 (IO3)
SMB0_SCK: J1.149, J29.3
SMB0_SDA: J1.148, J29.2
SMB1_SCK: J1.151, J29.5
SMB1_SDA: J1.150, J29.4
SPARE_P173: J1.173, J31.2
SPARE_P174: J1.174, J31.3
SPARE_P175: J1.175, J31.4
SPARE_P176: J1.176, J31.5
SPARE_P177: J1.177, J31.6
SPARE_P178: J1.178, J31.7
SPARE_P179: J1.179, J31.8
SPARE_P180: J1.180, J31.9
SPARE_P181: J1.181, J31.10
SPARE_P182: J1.182, J31.11
SPARE_P183: J1.183, J31.12
SPARE_P184: J1.184, J31.13
SPARE_P185: J1.185, J31.14
SPARE_P186: J1.186, J31.15
SPARE_P187: J1.187, J31.16
SPARE_P188: J1.188, J31.17
SPARE_P189: J1.189, J31.18
SPARE_P190: J1.190, J31.19
SPARE_P191: J1.191, J31.20
SPARE_P192: J1.192, J31.21
SPARE_P193: J1.193, J32.2
SPARE_P194: J1.194, J32.3
SPARE_P195: J1.195, J32.4
SPARE_P196: J1.196, J32.5
SPARE_P197: J1.197, J32.6
SPARE_P198: J1.198, J32.7
SPARE_P199: J1.199, J32.8
SPARE_P200: J1.200, J32.9
SPARE_P201: J1.201, J32.10
SPARE_P202: J1.202, J32.11
SPARE_P203: J1.203, J32.12
SPARE_P204: J1.204, J32.13
SPARE_P205: J1.205, J32.14
SPARE_P206: J1.206, J32.15
SPARE_P207: J1.207, J32.16
SPARE_P208: J1.208, J32.17
SPARE_P209: J1.209, J32.18
SPARE_P210: J1.210, J32.19
SPARE_P211: J1.211, J32.20
SPARE_P212: J1.212, J32.21
SPARE_P213: J1.213, J32.22
SPARE_P214: J1.214, J32.23
SPARE_P215: J1.215, J32.24
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

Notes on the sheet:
POWER
DDR4 UDIMM-288 CONNECTOR
BMC - ESP32-S3
CARRIER PHYSICAL I/O
PIN BREAKOUT HEADERS
VCORE VOLTAGE SELECT
VDDR VOLTAGE SELECT
GMAC0 (RGMII0)
GMAC1 (RGMII1, A1 2nd MAC)
SSI0 (SPI master)
PWM0-7
GPIO0-15 (plain)
UART0
UART2
UART3
UART1 (BMC console)
MSC1
SSI1
SAR-ADC
SMB0/SMB1 (general I2C)
J1 SPARE (P173-192)
J1 SPARE (P193-216)
J1 SPARE (P217-240)
J1 SPARE (P241-264)
J1 SPARE (P265-282)

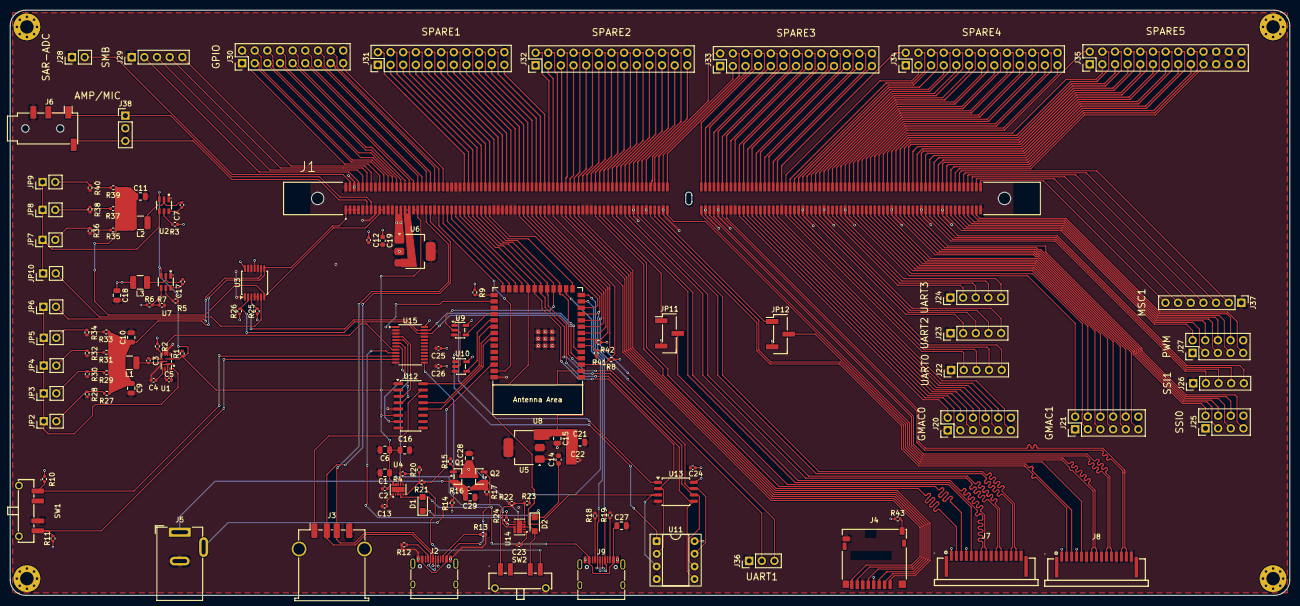
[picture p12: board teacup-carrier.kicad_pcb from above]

Board: 4 copper layers, 257.0 x 117.5 mm, 137 parts (0 on the bottom side), 308 nets.

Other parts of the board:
H1, H2, H3, H4: MountingHole_Pad; MountingHole_2.7mm_M2.5_Pad_Via

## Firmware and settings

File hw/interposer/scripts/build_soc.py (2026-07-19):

"""Interposer SoC section (T31ZX reference) -- connectivity by label, same
convention as the carrier's own scripts: every pin gets either a power
flag or a net label placed directly on it, no drawn wires. Component
values/footprints and the crystal/VREF/VCM bias topology are lifted
verbatim from TeaCup 3.3's tested schematic (the exact circuits this
project is standardizing on). Pin-to-net assignments come from
../pinout_288.csv, cross-referenced against T31ZX's real pin functions
and resolved for every genuine pin-sharing conflict (see that file and
session history for the reasoning behind each call). Per explicit user
direction, 2026-07-18.
"""
import sys, uuid
sys.path.insert(0, '.')
from schgen import Sheet, GRID

TI = "/home/administrator/projects/teacup-neo/hw/interposer/teacup-interposer.kicad_sym"
DEV = "/usr/share/kicad/symbols/Device.kicad_sym"
PWR = "/usr/share/kicad/symbols/power.kicad_sym"
FLASH = "/usr/share/kicad/symbols/Memory_Flash.kicad_sym"

def S(n):
    return round(n * GRID, 2)

s = Sheet()
s.ensure_symbol(TI, "T31ZX", "teacup-interposer:T31ZX")
s.ensure_symbol(DEV, "R", "Device:R")
s.ensure_symbol(DEV, "C", "Device:C")
s.ensure_symbol(DEV, "Crystal_GND24", "Device:Crystal_GND24")
s.ensure_symbol(FLASH, "W25Q32JVSS", "Memory_Flash:W25Q32JVSS")
s.ensure_symbol(PWR, "GND", "power:GND")
s.ensure_symbol(PWR, "PWR_FLAG", "power:PWR_FLAG")

LABEL_ANGLE = {"right": 0, "left": 180, "up": 90, "down": 270}
GNDF = ("flag", "GND")

# ---------- place T31ZX ----------
IC1 = "teacup-interposer:T31ZX"
icx, icy = S(140), S(160)
s.place(IC1, "IC1", "T31ZX", icx, icy, 0,
        footprint="teacup-interposer:QFN35P900X900X90-89N-D",
        ref_at=(icx, icy - S(70), 0), value_at=(icx, icy + S(70), 0))

# per-pin assignment: ("NET"|"RAIL", net_name) | ("LOCAL", local_net_name) | ("GND",)
# LOCAL nets stay sheet-local (no global_); NET/RAIL/SPARE are global so
# they reach the DDR4 edge connector sheet.
PIN_ASSIGN = {
    "1": ("NET", "PWM0"), "2": ("NET", "PWM1"),
    "3": ("RAIL", "+1V8"),
    "4": ("LOCAL", "EXCLK_O"), "5": ("LOCAL", "EXCLK_I"),
    "6": ("RAIL", "+1V8"),
    "7": ("NET", "SPARE_P173"),
    "8": ("NET", "SPARE_P174"),
    "9": ("RAIL", "+1V8"),
    "10": ("RAIL", "VCORE"),
    "11": ("NET", "SPARE_P175"),
    "12": ("NET", "SMB0_SCK"), "13": ("NET", "SMB0_SDA"),
    "14": ("NET", "MSC1_CMD"), "15": ("NET", "MSC1_CLK"),
    "16": ("NET", "MIPI0_GPIO"),
    "17": ("NET", "SPARE_P176"),
    "18": ("NET", "UART2_RXD"), "19": ("NET", "UART2_TXD"),
    "20": ("NET", "UART2_RTS"), "21": ("NET", "UART2_CTS"),
    "22": ("NET", "SPARE_P177"), "23": ("NET", "SPARE_P178"),
    "24": ("NET", "MIPI0_D0N"), "25": ("NET", "MIPI0_D0P"),
    "26": ("NET", "MIPI0_CLKN"), "27": ("NET", "MIPI0_CLKP"),
    "28": ("NET", "MIPI0_D1N"), "29": ("NET", "MIPI0_D1P"),
    "30": ("RAIL", "VCORE"), "31": ("RAIL", "+1V8"),
    "32": ("NET", "SAR_AUX0"),
    "33": ("RAIL", "+1V8"), "34": ("RAIL", "+1V8"),
    "35": ("NET", "USBA_HOST_DM"), "36": ("NET", "USBA_HOST_DP"),
    "37": ("RAIL", "+3V3"), "38": ("RAIL", "+1V8"),
    "39": ("RAIL", "VCORE"), "40": ("RAIL", "+3V3"),
    "41": ("NET", "MICLP"),
    "42": ("LOCAL", "VCM"),
    "43": ("RAIL", "+1V8"),
    "44": ("NET", "HPOUTL"),
    "45": ("NET", "SSI0_CE0"), "46": ("NET", "SSI0_DR"),
    "47": ("NET", "SSI0_DT"), "48": ("NET", "SSI0_CLK"),
    "49": ("NET", "MSC0_D1"), "50": ("NET", "MSC0_D0"),
    "51": ("NET", "MSC0_CLK"), "52": ("NET", "MSC0_CMD"),
    "53": ("NET", "MSC0_D3_CD"), "54": ("NET", "MSC0_D2"),
    "55": ("RAIL", "VCORE"), "56": ("RAIL", "+3V3"),
    "57": ("NET", "GMAC0_MDIO"), "58": ("NET", "GMAC0_MDCK"),
    "59": ("NET", "GMAC0_RXDV"),
    "60": ("NET", "GMAC0_RXD0"), "61": ("NET", "GMAC0_RXD1"),
    "62": ("NET", "GMAC0_TXCLK"), "63": ("NET", "GMAC0_PHYCLK"),
    "64": ("NET", "GMAC0_TXD0"), "65": ("NET", "GMAC0_TXD1"),
    "66": ("NET", "GMAC0_TXEN"),
    "67": ("NET", "SPARE_P179"),
    "68": ("NET", "UART0_RTS"), "69": ("NET", "UART0_CTS"),
    "70": ("NET", "UART0_TXD"), "71": ("NET", "UART0_RXD"),
    "72": ("RAIL", "VCORE"),
    "73": ("NET", "SPARE_P180"), "74": ("NET", "SPARE_P181"),
    "75": ("RAIL", "+1V8"), "76": ("RAIL", "+1V8"),
    "77": ("LOCAL", "VREF"),
    "78": ("RAIL", "VCORE"), "79": ("RAIL", "+1V8"),
    "80": ("NET", "GPIO0"),
    "81": ("NET", "SSI1_CE0"), "82": ("NET", "SSI1_CLK"),
    "83": ("RAIL", "VCORE"), "84": ("RAIL", "+3V3"),
    "85": ("NET", "PWM3"), "86": ("NET", "PWM2"),
    "87": ("NET", "SMB1_SCK"), "88": ("NET", "SMB1_SDA"),
    "89": ("GND",),
}
assert len(PIN_ASSIGN) == 89

for num, entry in PIN_ASSIGN.items():
    p = s.pin_pos(IC1, icx, icy, 0, num)
    d = s.pin_dir(IC1, num)
    kind = entry[0]
    if kind == "GND":
        s.flag("GND", p, "S", d)
    elif kind == "LOCAL":
        s.label(entry[1], p[0], p[1], LABEL_ANGLE[d], global_=False)
    else:  # NET or RAIL -- both cross to the DDR4 edge connector sheet
        s.label(entry[1], p[0], p[1], LABEL_ANGLE[d], global_=True)

# ============ Local support circuitry (values/topology per TeaCup 3.3) ============

RAIL_NAMES = {"+1V8", "+3V3", "VCORE", "VDDR"}

def vert2(lib, ref, val, x, y, top, bottom, fp):
    s.place(lib, ref, val, x, y, 0, footprint=fp,
            ref_at=(x + S(4), y - S(1), 0), value_at=(x + S(4), y + S(1), 0))
    for pn, spec, d in (("1", top, "up"), ("2", bottom, "down")):
        p = s.pin(lib, x, y, 0, pn)
        if isinstance(spec, tuple):
            s.flag(spec[1], p, "S", d)
        else:
            s.label(spec, p[0], p[1], LABEL_ANGLE[d], global_=spec in RAIL_NAMES)

# --- Crystal: Y1 (24MHz) + C20/C21 (12pF load) + R21 (1M feedback) ---
# Y1 pin1->EXCLK_I, pin3->EXCLK_O, pin2 (case, shared position with hidden
# pin4)->GND -- exact TeaCup 3.3 topology, using Crystal_GND24 since the
# real part is a 4-pad case-grounded crystal, not a plain 2-pin one.
CRYSTAL = "Device:Crystal_GND24"
cx, cy = S(20), S(20)
s.place(CRYSTAL, "Y1", "24 MHz", cx, cy, 0,
        footprint="Crystal:Crystal_SMD_2016-4Pin_2.0x1.6mm",
        ref_at=(cx, cy - S(6), 0), value_at=(cx, cy + S(6), 0))
for pn, spec in (("1", "EXCLK_I"), ("2", GNDF), ("3", "EXCLK_O")):
    p = s.pin(CRYSTAL, cx, cy, 0, pn)
    d = s.pin_dir(CRYSTAL, pn)
    if isinstance(spec, tuple):
        s.flag(spec[1], p, "S", d)
    else:
        s.label(spec, p[0], p[1], LABEL_ANGLE[d], global_=False)

vert2("Device:C", "C20", "12pF", S(30), S(20), "EXCLK_I", GNDF, "Capacitor_SMD:C_0402_1005Metric")
vert2("Device:C", "C21", "12pF", S(38), S(20), "EXCLK_O", GNDF, "Capacitor_SMD:C_0402_1005Metric")
vert2("Device:R", "R21", "1M", S(46), S(20), "EXCLK_I", "EXCLK_O", "Resistor_SMD:R_0402_1005Metric")
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

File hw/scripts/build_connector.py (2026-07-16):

"""DDR4 UDIMM-288 connector section -- connectivity by label per BUILD.md,
same system as the approved power/bmc sheets: flags directly on power pins
(parallel to the pin, value text in-row), labels directly on signal pins,
no wires, 50mil grid throughout."""
import sys, uuid
sys.path.insert(0, '.')
from schgen import Sheet, GRID

TC = "/home/administrator/projects/teacup-neo/hw/teacup-carrier.kicad_sym"
PWR = "/usr/share/kicad/symbols/power.kicad_sym"

def S(n):
    return round(n * GRID, 2)

s = Sheet()
s.ensure_symbol(TC, "AH58893-T9B10-3F", "teacup-carrier:AH58893-T9B10-3F")
s.ensure_symbol(PWR, "GND", "power:GND")
CONN = "teacup-carrier:AH58893-T9B10-3F"

LABEL_ANGLE = {"right": 0, "left": 180, "up": 90, "down": 270}

def unit_pin(ux, uy, unit, num, spec):
    if spec is None:
        return
    p = s.pin_pos(CONN, ux, uy, 0, str(num))
    d = s.pin_dir(CONN, str(num))
    if spec == "GND":
        s.flag("GND", p, "C", d)
    else:
        # RESERVED_* pins are placeholders local to this sheet; the rest
        # cross to other sections and stay global.
        s.label(spec, p[0], p[1], LABEL_ANGLE[d],
                global_=not spec.startswith("RESERVED_"))

# ============ Unit 1 (pins 1-48): infrastructure crossings ============
u1x, u1y = S(40), S(56)
s.place(CONN, "J1", "AH58893-T9B10-3F", u1x, u1y, 0, unit=1,
        footprint="teacup-carrier:DDR4288S0511H_UDIMM288",
        ref_at=(u1x, u1y - S(26), 0), value_at=(u1x, u1y + S(26), 0))

UNIT1 = {
    1: "VCORE", 2: "VCORE", 3: "VCORE", 4: "VCORE",
    # 6/7 carry HPOUTL/MICLP (moved from unit 4's old 170/171, which become
    # GND in their place -- see there), per explicit user direction,
    # 2026-07-15. Still GND-flanked on both sides (5, 8), same isolation
    # intent as before. 6/7 swapped (MICLP/HPOUTL instead of HPOUTL/MICLP)
    # per explicit user direction, 2026-07-15.
    5: "GND", 6: "MICLP", 7: "HPOUTL", 8: "GND",
    9: "VDDR", 10: "VDDR",
    11: "GND", 12: "GND",
    13: "+3V3", 14: "+3V3",
    15: "+1V8", 16: "+1V8",
    # 17/18 carry +5V_SW (the arbitrated switched-5V rail, U4/U14's shared
    # VOUT -- see docs/UNIVERSAL.md power architecture), not a dedicated
    # mode-A-only rail: +5V_MODEA was redundant since a self-contained
    # module already needs its own bare-bench power input regardless, per
    # explicit user direction, 2026-07-16.
    17: "+5V_SW", 18: "+5V_SW",
    # 20/21 carry the shared USB host data pair (moved from unit 1's old
    # 40/41, which become GND in their place -- see there), per explicit
    # user direction, 2026-07-16. Still GND-flanked on both sides (19, 22).
    19: "GND", 20: "USBA_HOST_DP", 21: "USBA_HOST_DM", 22: "GND",
    # 23-35: reordered so U8 (ESP32-S3-WROOM-1)'s ascending pin order maps
    # to J1's descending pin order in this group (U8 pin39->J1 23, pin26->
    # 24, pin25->25, pin24->26, pin23->27, pin22->28, pin21->29, pin20->30,
    # pin19->31, pin18->32, pin17->33, pin15->34, pin12->35), per explicit
    # user direction, 2026-07-16.
    23: "VCORE_SNS", 24: "HOSTED_DATA_READY",
    25: "HOSTED_HANDSHAKE",
    26: "HOSTED_SPI_CS",
    27: "HOSTED_SPI_MISO",
    28: "SFC_IO2", 29: "SFC_IO1",
    30: "SFC_CLK", 31: "SFC_IO0", 32: "SFC_CS", 33: "SFC_IO3",
    34: "RESET_EN", 35: "BOOTSEL",
    36: "GND", 37: "GND", 38: "GND", 39: "GND",
}
# Pins 40-48: explicitly reserved -- the per-SoC GPIO/peripheral superset
# mapping is a separate task (docs/UNIVERSAL.md SS8 geography-first rule);
# labeled placeholders keep them visible without inventing assignments.
for p in range(40, 49):
    UNIT1[p] = f"RESERVED_P{p}"
# 40/41: moved to 20/21 (see there), became GND in their place per
# explicit user direction, 2026-07-16.
UNIT1[40] = "GND"
UNIT1[41] = "GND"
# 42-48: ESP-Hosted full-duplex SPI + reset (BMC ESP32-S3 <-> interposer
# SoC), now one contiguous block -- HOSTED_RESET used to sit alone at
# unit 2 pin 86 (see there for why), far from its own SPI/handshake
# siblings; moved here next to them per explicit user direction,
# 2026-07-15. Reordered again so U8's ascending pin order maps to J1's
# descending pin order in this group (U8 pin11->J1 42, pin10->43, pin9->
# 44, pin8->45, pin7->46, pin6->47, pin3->48), per explicit user
# direction, 2026-07-16.
UNIT1[42] = "UART1_RX"
UNIT1[43] = "UART1_TX"
UNIT1[44] = "HOSTED_SPI_MOSI"
UNIT1[45] = "HOSTED_SPI_CLK"
UNIT1[46] = "I2C_ID_SCL"
UNIT1[47] = "I2C_ID_SDA"
UNIT1[48] = "HOSTED_RESET"

for num, spec in UNIT1.items():
    unit_pin(u1x, u1y, 1, num, spec)

# ============ Unit 2 (pins 49-96): microSD + headphone + 2x MIPI camera ============
u2x, u2y = S(110), S(56)
s.place(CONN, "J1", "AH58893-T9B10-3F", u2x, u2y, 0, unit=2,
        ref_at=(u2x, u2y - S(26), 0), value_at=(u2x, u2y + S(26), 0))
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

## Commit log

2026-07-05 Extract T31ZX pin usage from Teacup 3.3 netlist
    All 89 pins mapped to nets, none unconnected. Core rail is 0.8V on
    this board; DDR rail 1.8V (DDR2 SIP).
    [t31zx_teacup_pinuse.csv]
2026-07-05 Add T41NQ pin table (96+EP), verified against T41XQ datasheet
    Hand-extracted from T41NQ_ds_v1.6 section 5, structurally validated
    (pins 1-96 exactly once, power pin lists match DS). Full-table
    cross-check vs T41XQ_ds_v1.8: identical pinout.
    [t41nq_pins.csv]
2026-07-05 Add T31ZX->T41NQ pin mapping
    Bijective map of all 89 Teacup pads to T41 QFN96. J4 GPIO header
    remaps to PC bank (3.3V) with UART2/SMB1 function preservation.
    Dropped: PPRST_, 4 internal-only rails. New: POR_CTL strap, DDR ZQ
    resistors, MICNL, SFC quad option, 5 spare PC pads.
    [pinmap_t31_to_t41.csv]
2026-07-09 Universal: add DDR4 UDIMM-288 desktop as a third connector option
    Coarse 0.85mm pitch (easiest fingers, rugged), 288 pins (~93 gnd),
    cheap + LCSC-stocked; cost is ~133mm length (2x board size). SO-DIMM-260
    stays primary; UDIMM-288 for a larger rugged rig; MXM3-314 backup.
2026-07-09 Universal BMC: switch to ESP32-S3-WROOM-1-N16R2 (quad PSRAM frees GPIOs)
    Octal PSRAM (R8) eats GPIO33-37; BMC is GPIO-hungry (~24 lines). Quad
    PSRAM (R2) frees them -> ~34 usable GPIOs, 2MB PSRAM plenty. LCSC
    C2913205, 8.7k in stock, ~$3.41 - better stock + cheaper than R8.
2026-07-09 Universal: rail table is decided, not open
    Every SoC core/DDR/IO voltage is datasheet-confirmed (T20 via T10, T30 via its
    own). T30's unstated core current is covered by the >=3A universal VCORE spec.
    Moved from Open to Decided.
2026-07-09 Universal: resolve multi-sensor - camera FFC on interposer, not carrier pins
    Datasheet-verified: T41 is single 2-lane MIPI on every package (QFN96 has zero
    DVP), so teacup-neo T41 is single-sensor by silicon; T41 dual = MIPI+DVP BGA
    only. T40 is the real multi-sensor part (4 data + 2 clock lanes = two 2-lane
    sensors). Decision: sensor MIPI stays on the interposer like the clock (D-PHY
    too fast to cross the socket); multi-sensor = per-module FFC stuffing option at
    zero carrier-pin cost, which removes the past-260 pressure. Sections 2, 10.
    Section 10 Deferred is now empty too.
2026-07-09 Universal: DVP is first-class - mandatory for DVP-only T10/T20/T21
    Full family sensor map verified from datasheets: T10/T20/T21 = 12-bit DVP, NO
    MIPI (DVP is their only camera path); T23 = 2-lane MIPI + 8-bit DVP (PA00-18);
    T30/T31 = 2-lane MIPI + 12-bit DVP. Carrier routes a camera-zone to both a MIPI
    FFC and a DVP header; each interposer drives whichever its SoC has. No extra
    budget: DVP lines are GPIO-muxed (already in the ~120-GPIO superset), DVP/MIPI
    are mutually exclusive per interposer (share positions), and DVP is low-speed.
2026-07-09 Repo pivot: Universal platform IS Teacup Neo; T41 board -> old/
    The universal carrier+interposer design (docs/UNIVERSAL.md) is now the project.
    Archived the original single-SoC T41 (QFN96) board and its build pipeline under
    old/ (hw/, scripts/, reference/, T41-specific docs, old README). New top-level
    README frames the Universal platform; old/README marked as the archived
    precursor with a ../docs/UNIVERSAL.md pointer. History preserved (git renames).
    [12-30-23-Teacup.kicad_pcb-revC.csv, pinmap_t31_to_t41.csv, t31zx_teacup_pinuse.csv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]
2026-07-11 Add docs/BUILD.md: agent-facing headless build guide
    Companion to UNIVERSAL.md (what) covering how to build the carrier + interposer
    with the proven headless pipeline: toolchain (KiCad 9.0.2 kicad-cli + pcbnew,
    FreeRouting 1.9.0 under xvfb, Java 21), the label-driven schematic method + pin
    transform + netlist-diff verification, phase plan (pinout contract -> card-edge
    footprint -> interposer -> carrier), controlled-impedance/manual-routing gap,
    per-phase verify gates, T41 gotchas, and a reuse map of old/scripts/. Linked
    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
2026-07-11 Carrier board: BMC power isolation, ESP-Hosted link, GPIO expander
    Rebuilds the schematic to connectivity-by-label per BUILD.md (zero
    wires/junctions) across all four sections, and adds the BMC power
    architecture, connector crossings, and safety fixes worked out this
    session:
    - Dedicated BMC USB-C (J9), isolated 5V domains (+5V_BMC/+5V_ALT/+5V_SW),
    priority DC-jack-over-USB-C P-FET OR (Q1/Q2), 2:1 load-switch select
    (U4/U14) with a genuine ON-OFF-ON manual override (SW2)
    - D1/D2 diode-OR so the BMC stays powered on ALT-only input without
    reopening the J9 backfeed path
    - JP1 provisioning jumper + mandatory bring-up checklist: gates SW2 until
    the digipot's NV memory has been confirmed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
    [bmc.kicad_sch, connector.kicad_sch, io.kicad_sch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]
2026-07-12 Convert large pin-breakout headers to double-row, J1-ordered pinout
    J20/J21/J25/J27/J30-J35 now use Conn_02xNN_Odd_Even + PinHeader_2xNN
    footprints instead of single-row 1xNN -- half the physical length, and
    KiCad's odd/even pin numbering keeps each header's signals in the same
    J1-sequential order they were already assigned, just zig-zagged across
    two columns instead of one long row. Odd GND+signal counts get a 2nd
    GND appended at the far pin to fill the row evenly. J22-J24/J26/J28/J29
    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
    [headers.kicad_sch, teacup-carrier.kicad_pcb, teacup-carrier.kicad_sch]
